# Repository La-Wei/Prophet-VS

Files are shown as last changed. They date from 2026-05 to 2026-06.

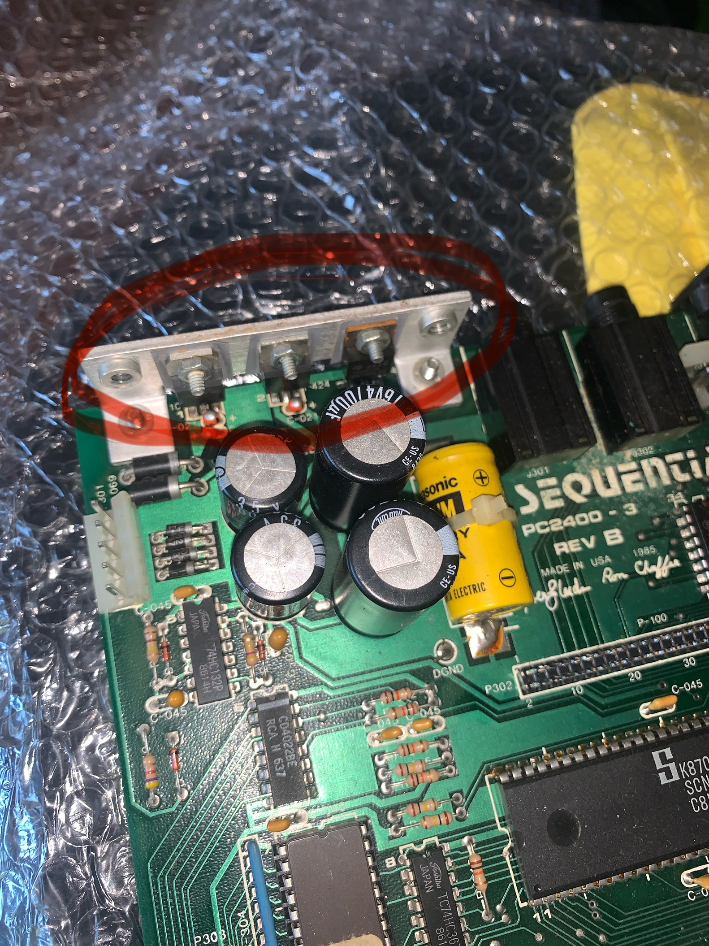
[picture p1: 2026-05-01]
IMG_5543.jpg

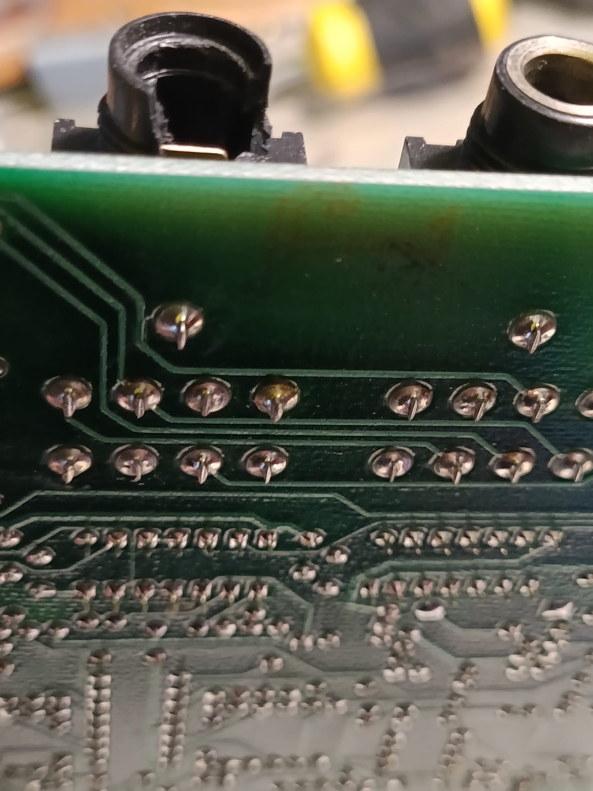
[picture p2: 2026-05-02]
b3b7119b-25aa-43f1-9ff1-f48e857112dc.JPG

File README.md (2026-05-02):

# Prophet VS - diagnosi riparazione

Questa repository contiene materiale preparato per aiutare un tecnico a diagnosticare due problemi separati sul Sequential Circuits Prophet VS:

- audio/modulazione/bleed che passa anche con volume a zero
- retro case molto caldo nella zona dei tre regolatori TO-220

## Apri prima questi file

1. [Cause possibili e fix](tecnico/01_problemi_e_fix/cause_e_fix.md)
2. [Briefing tecnico](tecnico/01_problemi_e_fix/technician_briefing_volume_zero_bleed.md)
3. [Mappa rapida](tecnico/01_problemi_e_fix/quick_navigation_map.md)
4. [CEM5530: diagnosi e ricambi](tecnico/01_problemi_e_fix/cem5530_diagnosi_ricambi.md)
5. [CEM5530/ELD5530: dossier clone o ricostruzione](tecnico/07_autocostruzione_ricambi/cem5530_clone_build_dossier.md)
6. [ELD5530 V2-like con MAX5167: progetto preliminare](tecnico/07_autocostruzione_ricambi/max5167_v2_like_pre_design.md)
7. [Rev A MAX5167: prototipo non validato](tecnico/07_autocostruzione_ricambi/rev_a_max5167_prototipo/README.md)
8. [Moduli Straylight X5530 trovati](tecnico/07_autocostruzione_ricambi/straylight_x5530_moduli_trovati.md)
9. [Contatti acquisto ELD5530 / CEM5530 replacement](tecnico/07_autocostruzione_ricambi/contatti_acquisto_eld5530_cem5530.md)
10. [Batteria memoria, SRAM e mod senza batteria](tecnico/01_problemi_e_fix/batteria_memoria_nvram.md)
11. [Jack posteriori](tecnico/01_problemi_e_fix/jack_sostituzione.md)
12. [Ricambi pannello posteriore](tecnico/01_problemi_e_fix/pannello_posteriore_ricambi.md)
13. [Checklist ispezione](tecnico/02_checklist_misure/visual_inspection_checklist.md)
14. [Piano misure sicure](tecnico/02_checklist_misure/safe_measurement_plan.md)

## Cartelle

- `tecnico/`: pacchetto pulito da consegnare al tecnico.
- `doc/`: PDF originali e knowledge base completa usata per estrarre note e immagini.
- `prompt/`: prompt di lavoro usati per generare la documentazione.

## PDF nel pacchetto tecnico

La cartella `tecnico/06_pdf_originali/` contiene:

- `pvs_service.pdf`
- `sci_prophet_vs_ecr738.pdf`
- `sci_prophet_vs_ecr739.pdf`
- `5530.pdf`
- `5508.pdf`

La sottocartella `tecnico/06_pdf_originali/component_datasheets/` contiene link ai datasheet esterni `MAX5167` e `SSM2300` utili per valutare cloni `CEM5530`. La cartella `tecnico/07_autocostruzione_ricambi/rev_a_max5167_prototipo/` contiene una proposta Rev A marcata chiaramente come prototipo non validato.

## Regolatori nella foto

Nella foto `tecnico/foto/IMG_5543.jpg`, i tre TO-220 fissati al case/dissipatore sono regolatori lineari:

- sinistra: `U301 7805`, rail `+5VD`
- centro: `U302 7812`, rail `+12V`
- destra: `U303 7912`, rail `-12V`

Il regolatore caldo non va considerato automaticamente guasto: e' gia' stato sostituito con uno piu capiente. La priorita' e' misurare rail, ripple, Vin/Vout, temperatura e carico a valle.

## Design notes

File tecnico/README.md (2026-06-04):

# Pacchetto tecnico pulito

Questa cartella e' pensata per un tecnico che deve diagnosticare un Sequential Circuits Prophet VS con due problemi da tenere separati finche le misure non li collegano:

- audio/modulazione/bleed che passa anche con volume a zero
- case posteriore molto caldo nella zona dei tre regolatori TO-220 fissati al dissipatore

## Da aprire per primi

1. `01_problemi_e_fix/cause_e_fix.md`
2. `01_problemi_e_fix/technician_briefing_volume_zero_bleed.md`
3. `01_problemi_e_fix/quick_navigation_map.md`
4. `01_problemi_e_fix/cem5530_diagnosi_ricambi.md`
5. `07_autocostruzione_ricambi/cem5530_clone_build_dossier.md`
6. `07_autocostruzione_ricambi/max5167_v2_like_pre_design.md`
7. `07_autocostruzione_ricambi/rev_a_max5167_prototipo/README.md`
8. `07_autocostruzione_ricambi/straylight_x5530_moduli_trovati.md`
9. `07_autocostruzione_ricambi/contatti_acquisto_eld5530_cem5530.md`
10. `01_problemi_e_fix/batteria_memoria_nvram.md`
11. `01_problemi_e_fix/jack_sostituzione.md`
12. `01_problemi_e_fix/pannello_posteriore_ricambi.md`
13. `02_checklist_misure/visual_inspection_checklist.md`
14. `02_checklist_misure/safe_measurement_plan.md`
15. `01_problemi_e_fix/ronzio_acuto_chorus_u916_ne571/README.md`

## Identificazione regolatori nella foto

La foto `foto/IMG_5543.jpg` mostra la board `PC2400-3 REV B` con tre TO-220 fissati al case/dissipatore. Dai documenti sono regolatori lineari:

- sinistra: `U301 7805`, rail `+5VD`
- centro: `U302 7812`, rail `+12V`
- destra: `U303 7912`, rail `-12V`

L'ordine sinistra->destra deriva dalla designator map `pvs_service` pagina 5; confermare sulla serigrafia reale se visibile.

## Struttura

- `01_problemi_e_fix/`: cause, fix, briefing e mappa rapida.
- `02_checklist_misure/`: controlli visivi e piano misure sicure.
- `03_mappe_circuito/`: mappe brevi per audio, S&H/CV, power/reset, pressure, ECR e chorus.
- `04_componenti_net_rail/`: indici componenti, rail, net e connettori utili.
- `05_pagine_rilevanti/`: note e immagini delle sole pagine utili.
- `06_pdf_originali/`: PDF sorgenti principali.
- `07_autocostruzione_ricambi/`: dossier per valutare cloni/ricostruzione di ricambi non reperibili e prototipo Rev A `MAX5167`.
- `foto/`: foto utente dell'area regolatori.

PDF inclusi in `06_pdf_originali/`: `pvs_service.pdf`, `sci_prophet_vs_ecr738.pdf`, `sci_prophet_vs_ecr739.pdf`, `5530.pdf`, `5508.pdf`. La sottocartella `06_pdf_originali/component_datasheets/` contiene link ai datasheet esterni `MAX5167` e `SSM2300`.

## Escluso apposta

Non ci sono prompt, OCR grezzo, script di estrazione, manifest JSON, cache o pagine non citate. La knowledge base completa resta in `doc/prophet_vs_service_context/` se serve tornare al materiale grezzo.

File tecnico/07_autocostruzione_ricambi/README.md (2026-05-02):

# Autocostruzione ricambi

Questa cartella raccoglie materiale per un tecnico che voglia valutare la ricostruzione di ricambi non reperibili.

Aprire prima:

1. [CEM5530 / ELD5530: dossier per clone o ricostruzione](cem5530_clone_build_dossier.md)
2. [Progetto preliminare ELD5530 V2-like con MAX5167](max5167_v2_like_pre_design.md)
3. [Rev A MAX5167 - prototipo non validato](rev_a_max5167_prototipo/README.md)
4. [Moduli Straylight X5530 trovati](straylight_x5530_moduli_trovati.md)
5. [Contatti per acquisto ELD5530 / CEM5530 replacement](contatti_acquisto_eld5530_cem5530.md)

Nota: questa cartella non contiene Gerber o schema ELD5530 originale, perche' non ne ho trovato una pubblicazione verificabile. Il dossier serve a evitare lavoro alla cieca; il progetto `MAX5167` porta invece la pista piu realistica fino a pin mapping, alimentazioni, vincoli PCB e test minimi. Synthelectro 2014 conferma IC Maxim Integrated per `ELD5530 V2`, ma non pubblica la sigla: `MAX5167` resta quindi un'ipotesi tecnica forte, non una BOM ufficiale. La sottocartella `rev_a_max5167_prototipo/` e' una base concreta per CAD/prototipo, ma resta non validata e non va montata nel Prophet VS senza collaudo fuori macchina.

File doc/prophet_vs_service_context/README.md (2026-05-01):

# Prophet VS service context

Questa cartella contiene una knowledge base locale generata dai PDF scannerizzati in `doc/`, senza modificare i PDF originali.

## Come e' stata creata
- `scripts/extract_pdf_pages.py` renderizza ogni pagina come PNG in `page_images/`.
- PyMuPDF/fitz non era disponibile in questo ambiente; lo script ha usato fallback locale macOS CUPS + `rastertotiff` + Pillow a 300 DPI.
- `scripts/extract_text_and_ocr.py` tenta testo nativo e poi OCR locale con Tesseract.
- `scripts/generate_markdown_kb.py` genera note pagina, indici, mappe circuito, indici componenti e note diagnostiche.

## Affidabilita OCR
OCR medio su datasheet e molte pagine schematiche; basso o incerto su alcune ECR/artwork. Ogni file pagina riporta `METHOD` e `CONFIDENCE`. Se un valore non e' chiaro, e' trattato come [NON CHIARO].

## Come navigare
- Inizia da `index.md` per argomento.
- Usa `source_files.md` per capire i PDF.
- Usa `page_notes/` per pagina specifica.
- Usa `circuit_maps/` per ragionare su pressure, S&H, audio, power/reset, keyboard e ECR.
- Usa `diagnostic_notes/` per partire dai sintomi.

## Da dove partire per riparazione
- Bleed/distorsione a volume zero: `diagnostic_notes/symptom_audio_at_volume_zero.md`, poi `circuit_maps/audio_path.md` e `circuit_maps/sample_hold_cv.md`.
- Pressure/aftertouch: `circuit_maps/pressure_aftertouch.md` e `circuit_maps/board_revisions_ecr.md`.
- Alimentazione: `circuit_maps/power_reset.md`.

## Avvisi
- Non sostituisce un tecnico synth qualificato.
- Sezioni alimentazione/mains possono essere pericolose.
- Vecchie PCB possono danneggiarsi con calore eccessivo, forza, puntali sbagliati o corti durante le misure.

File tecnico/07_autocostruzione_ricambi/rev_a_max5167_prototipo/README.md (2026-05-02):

# Rev A MAX5167 - prototipo non validato

## Stato

Questa cartella contiene una proposta di progetto `Rev A` per un modulo sostitutivo `CEM5530` basato su `MAX5167`.

E' un **prototipo non validato**:

- non e' uno schema originale `ELD5530`;
- non e' una BOM ufficiale Synthelectro: la fonte 2014 conferma solo IC Maxim Integrated, non la sigla `MAX5167`;
- non e' un progetto collaudato nel Prophet VS;
- non contiene Gerber pronti per produzione;
- non va montato nel synth senza test fuori macchina;
- va trasformato in CAD, revisionato e provato da un tecnico.

Obiettivo della `Rev A`: dare al tecnico una base concreta con schema testuale, pin map, BOM funzionale, vincoli PCB e test plan.

Nota batteria: questo prototipo sostituisce solo il `CEM5530`. Non e' la mod memoria non volatile e non elimina la batteria del Prophet VS; vedere `../../01_problemi_e_fix/batteria_memoria_nvram.md`.

## Applicazione pratica

La `Rev A` non e' una modifica interna a un chip. E' una schedina sostitutiva:

```text
CEM5530 originale fuori dallo socket
modulo Rev A inserito nello stesso socket
MAX5167 e alimentazioni locali montati sul modulo Rev A
```

Il CAD serve per realizzare fisicamente quella schedina: il `MAX5167` e' un 48-TQFP, mentre il `CEM5530` originale e' un modulo/IC a 40 pin con piedinatura diversa. La PCB fa da traduttore tra il Prophet e il `MAX5167`.

Se un modulo finito `ELD5530`/Straylight e' reperibile e collaudato, questa cartella non serve per montarlo. Serve solo se il tecnico deve costruire un sostituto.

## Aprire in ordine

1. [00_status_prototipo.md](00_status_prototipo.md)
2. [01_schema_testuale_rev_a.md](01_schema_testuale_rev_a.md)
3. [02_netlist_pinmap_rev_a.csv](02_netlist_pinmap_rev_a.csv)
4. [03_bom_funzione_rev_a.md](03_bom_funzione_rev_a.md)
5. [04_vincoli_pcb_rev_a.md](04_vincoli_pcb_rev_a.md)
6. [05_piano_collaudo_rev_a.md](05_piano_collaudo_rev_a.md)
7. [06_dati_da_misurare_sul_prophet.md](06_dati_da_misurare_sul_prophet.md)
8. [07_handoff_cad.md](07_handoff_cad.md)
9. [cad_kicad/README.md](cad_kicad/README.md)

## Cosa puo' fare il tecnico con questa cartella

- Disegnare lo schema in KiCad/Altium/Eagle senza dover ricavare da zero il mapping.
- Aprire un progetto KiCad iniziale in `cad_kicad/`.
- Creare il footprint adattatore `CEM5530` 40 pin -> `MAX5167` 48-TQFP.
- Selezionare componenti reali per boost, LDO, filtri e protezioni.
- Preparare un primo prototipo.
- Testare il modulo fuori dal Prophet VS.

## Cosa manca prima di dichiararlo funzionante

- Misure reali su `U449/U425`: rail, `VIN`, `INH`, address, carichi.
- Scelta part number finali per alimentazioni e protezioni.
- Layout PCB e revisione indipendente.
- Prototipo fisico.
- Collaudo strumentale.
- Installazione controllata in un solo socket alla volta.

## Rimandi

- Progetto preliminare: [../max5167_v2_like_pre_design.md](../max5167_v2_like_pre_design.md)
- Dossier generale: [../cem5530_clone_build_dossier.md](../cem5530_clone_build_dossier.md)
- Pinout CEM5530: [../../05_pagine_rilevanti/note/5530/page_002.md](../../05_pagine_rilevanti/note/5530/page_002.md)
- Schema Prophet S&H/CV: [../../05_pagine_rilevanti/note/pvs_service/page_006.md](../../05_pagine_rilevanti/note/pvs_service/page_006.md)

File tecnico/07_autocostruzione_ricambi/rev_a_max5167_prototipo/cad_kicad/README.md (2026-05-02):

# KiCad CAD - Rev A MAX5167 prototype

## Stato

Questa cartella contiene un progetto KiCad iniziale per il modulo `MAX5167 Rev A`.

E' **CAD di partenza**, non CAD finale:

- schema e PCB sono marcati come prototipo non validato;
- il PCB e' un placeholder meccanico/elettrico da completare in KiCad;
- non generare Gerber senza revisione del tecnico;
- usare la netlist CSV e lo schema testuale come sorgenti vincolanti.

## File

- `max5167_rev_a_prototype.kicad_pro`: progetto KiCad.
- `max5167_rev_a_prototype.kicad_sch`: foglio schematico di overview con vincoli Rev A.
- `max5167_rev_a_prototype.kicad_pcb`: board placeholder 4 layer con aree funzionali e serigrafia prototipo.
- [exports/max5167_rev_a_schematic.pdf](exports/max5167_rev_a_schematic.pdf): PDF esportato dallo schematico con `kicad-cli`.

Nota: lo schematico e' stato esportato con `kicad-cli 10.0.1` dal DMG KiCad montato localmente. Il PCB e' volutamente un placeholder di layout e va completato in KiCad prima di generare Gerber.

## Come usarlo

1. Aprire `max5167_rev_a_prototype.kicad_pro` in KiCad.
2. Creare/verificare i simboli reali:
   - `J1` socket/header `CEM5530` 40 pin;
   - `U1` `MAX5167` 48-TQFP;
   - `U2/U3/U4` alimentazioni;
   - `U5` DNP opzionale per stretching.
3. Importare il mapping da `../02_netlist_pinmap_rev_a.csv`.
4. Completare lo schema elettrico.
5. Completare il layout PCB.
6. Eseguire ERC/DRC.
7. Fare revisione indipendente prima di qualsiasi Gerber.

## Avvertenza

Il CAD non rende il progetto automaticamente sicuro. Il punto critico resta il collaudo fuori macchina: rail, startup, ripple, timing `INH`, address e carichi CV.

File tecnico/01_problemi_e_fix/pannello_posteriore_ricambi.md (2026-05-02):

# Pannello posteriore: jack, MIDI e switch

## Decisione sui jack 1/4"

I 4 jack 1/4" posteriori hanno plastica rotta: sostituirli tutti.

Foto locali aggiornate:

- `../foto/jack_pcb_01.JPG`
- `../foto/jack_pcb_02.JPG`
- `../foto/midi_din_originale_01.JPG`

Ricambio candidato:

- Jalco `YKB21-5078`
- 1/4" / 6.3 mm PCB
- stereo con switch
- filetto `M12x1`
- equivalenti dichiarati: `HLJ-2305`, `HTJ-064-16D`

Link sorgente: `https://www.synth-parts.com/en/products/connectors-and-cable/14-phone-jack/5460/ykb21-5078-phone-jack-1/4-6.3-mm-for-printed-circuits-stereo`

Jack mono Synth-Parts, solo se i footswitch risultano davvero mono e con footprint diverso:

- Jalco `YKB21-5076`, mono con switch, PCB, filetto `M12x1`: `https://www.synth-parts.com/en/products/connectors-and-cable/14-phone-jack/5475/ykb21-5076-phone-jack-1/4-6.3-mm-pcb-mono`
- Jalco `YKB21-5012`, mono con switch, PCB, filetto `M12x1`: `https://www.synth-parts.com/en/products/connectors-and-cable/14-phone-jack/5461/ykb21-5012-phone-jack-1/4-6.3-mm-for-printed-circuits-mono`

Compra: se tutti e 4 i footprint sono uguali, 4 pezzi `YKB21-5078`; se i due footswitch sono footprint mono, 2 stereo `YKB21-5078` piu 2 mono da scegliere tra `YKB21-5076`/`YKB21-5012` dopo misure.

## Porta/selettore MIDI OUT/THRU

Chiarimento utente: il componente rugginoso e' quello dell'area `MIDI OUT/THRU`, non il selettore tensione.

Il Prophet VS ha tre connessioni MIDI 5 poli DIN:

- `MIDI IN`
- `MIDI OUT`
- `MIDI OUT/THRU`

Il service mostra il circuito MIDI sulla pagina `pvs_service` 3:

- `U333 68B50`: UART MIDI;
- `U312 PC900`: optoisolatore MIDI IN;
- `Q302`: driver `MIDI OUT`;
- `Q301`: driver `MIDI OUT/THRU`.

Quindi la zona da controllare e' pagina `pvs_service` 3, non la pagina alimentazione.

## Se e' la presa DIN `MIDI OUT/THRU`

Se e' arrugginita la presa DIN femmina:

1. testare MIDI OUT e MIDI THRU con cavi buoni;
2. ispezionare pin, schermatura metallica, saldature e piazzole;
3. se la ruggine e' estesa o i contatti sono instabili, sostituire la presa.

Aggiornamento dalle foto: `../foto/midi_din_originale_01.JPG` mostra una presa DIN 5 poli diversa dai ricambi Jalco PCB gia linkati. Si vede un corpo con inserto rosso/fenolico, contatti lunghi piegati verso la PCB e due flange/orecchie di fissaggio. Quindi `YKF51-5050` e `YKF51-5046` non vanno ordinati come ricambi sicuri.

Il service non basta per garantire il footprint meccanico dei DIN. Prima di ordinare bisogna guardare la board reale e capire se i MIDI sono:

1. un blocco triplo integrato, tre DIN in un solo corpo;
2. tre prese DIN singole separate;
3. una DIN panel/chassis mount con terminali lunghi piegati/saldati in PCB, come sembra dalla nuova foto;
4. una variante ruotata o con pinout diverso.

Ricambi candidati, da confermare fisicamente:

- se e' un blocco triplo: Jalco `YKF51-5046`, triple female MIDI DIN socket for PCB, ma le foto nuove non puntano a questa soluzione;
- se sono singoli PCB moderni: Jalco `YKF51-5050` o `BCTE5P1-5211`, ma le foto nuove non sembrano combaciare;
- se e' come in foto: cercare una DIN femmina 5 poli `180 degree`, panel/chassis mount o PCB right-angle con flange, terminali solder/PC lunghi e stessa geometria.

Fonti ricambio:

- `https://www.synth-parts.com/en/products/connectors-and-cable/din-sockest-and-plugs/6651/e-mu-triple-female-midi-socket-for-pcb-jalco-ykf51-5046`
- `https://www.synth-parts.com/en/products/connectors-and-cable/din-sockest-and-plugs/6721/din-female-5-pin-midi-for-pcb-ykf51-5050`
- `https://www.synth-parts.com/en/products/connectors-and-cable/din-sockest-and-plugs/5442/din-female-5-pin-midi-for-printed-circuits`
- `https://www.synth-parts.com/en/products/connectors-and-cable/din-sockest-and-plugs/`

Nota importante: i link Synth-Parts sopra sono ora **solo confronto**, non ricambio confermato per il Prophet VS fotografato. Dalle foto bisogna cercare un ricambio con stessa meccanica, non solo "DIN MIDI 5 pin".

### Pista MIDI piu concreta dopo le foto

La pista piu concreta non e' Synth-Parts/Jalco, ma una DIN femmina 5 poli `180 degree` di famiglia Switchcraft DIN panel/PC mount.

Candidati Switchcraft da confrontare per primi:

- `57NC5FX`: DIN panel mount, 5 contatti a 180 gradi, terminali PC/thru-hole. E' il candidato piu interessante se il tecnico vuole terminali da PCB.
- `57GB5FX`: DIN panel mount, 5 contatti a 180 gradi, terminali solder cup/flared solder. E' interessante se l'originale ha terminali lunghi/saldabili da formare verso la PCB.
- `57PC5F`: DIN femmina right-angle PC mount, 5 contatti a 180 gradi, contact arrangement F. Da confrontare se serve un corpo piu "PCB right-angle" invece del panel mount classico.

Link utili:

- `https://www.switchcraft.com/din-panel-mount-connector-5-contacts-at-180-pc-terminals/57nc5fx/`
- `https://www.switchcraft.com/din-panel-mount-connector-5-contacts-at-180-/57gb5fx/`
- `https://www.switchcraft.com/female-din-right-angle-pc-mount-5-contacts-at-180-contact-arrangement-f/57pc5f/`

Verdetto operativo: prima misurare/interfacciare con questi tre datasheet/foto. Se uno combacia per flange, altezza e pattern terminali, quello diventa il ricambio MIDI preferito. Se non combacia, si cerca ancora, ma almeno si e' nella famiglia giusta.

Candidati/famiglie da confrontare fuori Synth-Parts:

- Switchcraft `57GB5FX`: DIN femmina 5 contatti 180 gradi, panel mount, usata per MIDI, `https://www.performanceaudio.com/products/switchcraft-57gb5fx-5-pin-din-panel-mount-jack`;
- Lumberg `0105 05`: DIN 5 poli right-angle/PCB chassis socket, `https://cpc.farnell.com/lumberg/0105-05/din-connector-rcpt-5pos-chassis/dp/CN25115`;
- Hirschmann `MAB 5 SH`: DIN 5 poli PCB right-angle, `https://uk.farnell.com/hirschmann/mab-5-sh/socket-din-pcb-5pin/dp/1944987`;
- Deltron `671-0501`: DIN 5 poli female PCB right-angle, `https://no.rs-online.com/web/p/din-connectors/1806737`.

Questi sono candidati di ricerca: non comprarli senza misurare distanza fori, altezza rispetto al pannello, forma flange, orientamento pin e pattern dei terminali.

## Se e' il piccolo switch `MIDI OUT/THRU`

Se il componente rugginoso e' proprio un piccolo slide switch vicino alla porta `MIDI OUT/THRU`, cercare come:

- slide switch right-angle PCB;
- `SP3T` / `1P3T`;
- funzione `ON-ON-ON`;
- low-current signal switch, non mains;
- stesso footprint, stessa altezza leva, stesso passo pin, stessi eventuali pin di ancoraggio.

Candidati da confrontare, non da comprare alla cieca:

- C&K `OS103011MA7QP1C`: SP3T, through-hole, right angle, PC pin;
- C&K `AYZ0103AGRLC`: SP3T, SMD/gull wing, right angle;
- Same Sky/CUI `SLW-1516255-6A-RA-D`: SP3T, through-hole, right angle;
- generici `SS-13F16` / `SS-13F24`: SP3T, through-hole, right angle.

Fonte utile ma non Prophet VS: una discussione Gearspace su Prophet 2000 descrive il selettore MIDI Thru/Out come slide switch right-angle `SP3T`. Questo aiuta la ricerca della famiglia componente, ma non prova il footprint del Prophet VS.

Fonte: `https://gearspace.com/board/geekzone/1421716-prophet-2000-need-help-finding-replacement-part.html`

## Test funzionale

Prima di dissaldare:

1. con MIDI monitor, verificare `MIDI OUT` separato;
2. verificare `MIDI OUT/THRU` nelle posizioni disponibili;
3. muovere leggermente plug/switch: se il segnale cade o diventa intermittente, il componente e' da sostituire;
4. se la ruggine e' sullo switch, misurare continuita' tra comune e contatti in ogni posizione.

## Nota separata: power e selettore tensione

Sul retro esistono anche componenti mains:

- `S1`: power switch;
- `S2`: selettore tensione `110/220`;
- `F1`: fuse.

Questi non sono l'oggetto indicato dall'utente, ma se risultano rugginosi vanno controllati come parti di rete AC.

## Lista acquisto pratica

Da comprare subito se il footprint jack e' confermato:

- 4 x Jalco `YKB21-5078`, se tutti e 4 i jack hanno stesso footprint stereo/switch
- oppure 2 x `YKB21-5078` + 2 x mono `YKB21-5076`/`YKB21-5012`, se i footswitch sono davvero footprint mono
- dadi `M12x1` di scorta, se non inclusi o se quelli originali sono ossidati

Da comprare solo dopo foto/misura:

- MIDI DIN: non comprare `YKF51-5050`/`YKF51-5046` come sicuri; dalle foto serve probabilmente DIN femmina 5 poli panel/PCB right-angle con flange e terminali lunghi. Prima confrontare Switchcraft `57NC5FX`, `57GB5FX`, `57PC5F`;
- eventuale slide switch `MIDI OUT/THRU` SP3T/right-angle con footprint identico.

Da non fare:

- non montare jack MIDI generici se non entrano perfettamente nel pannello;
- non ordinare un blocco triplo MIDI se sulla board ci sono tre DIN separati;
- non ordinare uno switch SP3T solo perche ha la stessa funzione: deve combaciare fisicamente;
- non lasciare la presa/switch `MIDI OUT/THRU` rugginosa se il contatto e' intermittente.

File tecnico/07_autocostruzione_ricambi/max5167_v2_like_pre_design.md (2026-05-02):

# Progetto preliminare ELD5530 V2-like con MAX5167

## Stato del progetto

Questo documento e' una pre-progettazione tecnica per una scheda sostitutiva del `CEM5530` in stile `ELD5530 V2`.

Non e' lo schema originale ELD5530, non e' una BOM definitiva e non e' un Gerber pronto da produrre. Serve a portare il lavoro fino al punto in cui un tecnico/progettista possa disegnare lo schema in CAD, fare una revisione pin-to-pin e preparare un prototipo senza ripartire da zero.

Per il pacchetto Rev A concreto, vedere [rev_a_max5167_prototipo/README.md](rev_a_max5167_prototipo/README.md). La Rev A e' marcata come prototipo non validato.

Risposta breve alla domanda: la fonte primaria Synthelectro 2014 conferma che `ELD5530 V2` e' basato su un IC Maxim Integrated, ma non pubblica la sigla. Il forum Gearspace cita esplicitamente il `MAX5167` e il datasheet `MAX5167` combacia molto bene con la funzione richiesta. Quindi il progetto piu realistico resta `MAX5167` su PCB adattatore 40 pin, con alimentazioni locali integrate, ma va trattato come prototipo dedotto e non come replica certificata dell'ELD5530 originale.

La stessa fonte 2014 spiega anche perche' le alimentazioni locali sono obbligatorie: la prima versione del ricambio richiedeva due piccole modifiche sulla board perche' non gestiva tutte le alimentazioni; la V2 invece fornisce direttamente le tensioni necessarie e viene presentata come plug-in replacement del `CEM5530`.

Nota batteria: questa scheda sostituisce il `CEM5530` nello sample & hold/CV e non elimina la batteria memoria. La batteria sparisce solo con una mod separata alle SRAM patch non volatili; vedere `../01_problemi_e_fix/batteria_memoria_nvram.md`.

## Cosa significa "modifica" in pratica

Non si modifica fisicamente il `MAX5167` e non si modifica il silicio del `CEM5530`.

La modifica e' una **scheda adattatrice**:

```text
socket Prophet per CEM5530
  -> schedina adattatrice 40 pin
  -> MAX5167 saldato sulla schedina
  -> regolatori/filtri locali sulla schedina
  -> pin della schedina che imitano il CEM5530 originale
```

Il `MAX5167` e' il chip commerciale che fa il lavoro sample & hold. Pero' non ha:

- lo stesso package del `CEM5530`;
- la stessa piedinatura;
- le stesse alimentazioni dirette;
- solo 30 canali, perche ne ha 32;
- la stessa meccanica plug-in.

Per questo serve il CAD: non per "programmare" o "modificare" il chip, ma per disegnare la piccola PCB che converte piedinatura, alimentazioni e segnali. In pratica il tecnico non prende un `MAX5167` e lo infila nel Prophet: salda il `MAX5167` su una schedina, testa la schedina, poi inserisce la schedina al posto del `CEM5530`.

Se si trova un modulo `ELD5530` o Straylight gia finito e collaudato, il CAD non serve all'utente: si compra il modulo e si monta. Il CAD serve solo se il modulo va ricostruito.

## Come si applica sul Prophet VS

Procedura pratica ideale, se il modulo Rev A viene davvero realizzato:

1. Diagnosticare quale `CEM5530` e' guasto o sospetto: `U449`, `U425`, oppure entrambi.
2. Misurare rail, `VIN`, `INH` e address sul socket originale.
3. Costruire la schedina adattatrice `MAX5167` fuori dal synth.
4. Collaudarla su alimentatore e fixture, non nel Prophet.
5. Spegnere il Prophet, rimuovere il `CEM5530` originale dal socket.
6. Se il socket originale e' doppia lira o fragile, sostituirlo con socket tulip di qualita'.
7. Inserire la schedina adattatrice rispettando pin 1.
8. Accendere con controllo corrente/temperatura.
9. Verificare CV e audio prima di montare il secondo modulo.

Quindi la modifica visibile sulla macchina dovrebbe essere minima: togliere il vecchio chip e inserire il modulo adattatore. La parte complessa sta tutta nella piccola scheda sostitutiva.

## Vincoli non negoziabili

- Modulo plug-in al posto del `CEM5530`, senza fili esterni se possibile.
- Compatibilita' con socket `U449` e `U425` del Prophet VS.
- Footprint maschio compatibile con il `CEM5530` a `40` pin.
- Ingresso comune dal DAC/S&H Prophet verso l'ingresso sample del nuovo IC.
- `30` uscite CV operative; i due canali extra del `MAX5167` restano non usati.
- Polarita' `INH` compatibile: high = hold, low = sample/acquire.
- Alimentazioni locali pulite: il `MAX5167` non va alimentato direttamente dal rail `+8V` originale.
- Prova fuori dal synth obbligatoria prima dell'installazione.

## Confronto CEM5530 vs MAX5167

| Punto | CEM5530 | MAX5167 | Impatto sul progetto |
| --- | --- | --- | --- |
| Canali | 30 S&H | 32 S&H | `OUT30/OUT31` restano NC/test pad |
| Address | 5 bit `A0..A4` | 5 bit `ADDR0..ADDR4` | Mapping diretto, da confermare sul timing Prophet |
| Controllo | `INH` | `S/H`, `SELECT`, `CONFIG` | `INH` puo' pilotare `S/H` se `SELECT` e' reso sempre attivo |
| Sample/hold | `INH` low aggiorna il canale indirizzato; high mette in hold/auto-zero | `S/H` low sample, high hold | Polarita' compatibile |
| Rail | Nel Prophet visibili `+8V`, `-5V`, GND/AGND | `VDD +10V`, `VSS -5V`, `VL +5V` | Serve generazione locale `+10V` e `+5V` |
| Package | 40 pin | 48 pin TQFP | Serve PCB adattatore |
| Droop | Da datasheet CEM, verificare pagina 4 | Tipico `1 mV/s` | Adeguato in teoria, ma va misurato nel refresh reale |
| Acquisition | CEM: ciclo veloce, pagina 4 | Datasheet MAX: 2.5 us tipico, fino a 4 us per acquisizione accurata | Misurare larghezza reale di sample nel Prophet |
| Output impedance | Buffer interni CEM | Varianti `L/M/N`: 50R/500R/1k | Preferire footprint che consenta piccole correzioni |

## Pinout CEM5530 ricavato dalla pagina 2

Da confermare visivamente su `../05_pagine_rilevanti/immagini/5530/page_002.png` e sulla board reale prima di disegnare il PCB.

| Pin CEM5530 | Segnale |
| --- | --- |
| 1 | `VIN` |
| 2-9 | `O0..O7` |
| 10 | `INH` |
| 11 | `A4` |
| 12-19 | `O8..O15` |
| 20 | `VSS` |
| 21 | `GND` |
| 22-29 | `O16..O23` |
| 30 | `A0` |
| 31 | `A1` |
| 32 | `A2` |
| 33 | `A3` |
| 34-39 | `O24..O29` |
| 40 | `VDD` |

## Mapping proposto CEM5530 -> MAX5167

Questo e' il mapping elettrico di partenza. Prima del CAD va verificato con continuita' sullo schema `pvs_service` pagina 6 e con una prova su breadboard/fixture.

| CEM5530 | MAX5167 | Note |
| --- | --- | --- |
| pin 1 `VIN` | pin 11 `IN` | Collegamento diretto iniziale; aggiungere footprint serie `0R/100R` e pad test |
| pin 10 `INH` | pin 5 `S/H` | Polarita' compatibile: high hold, low sample |
| pin 11 `A4` | pin 3 `ADDR4` | Address bit 4 |
| pin 30 `A0` | pin 47 `ADDR0` | Address bit 0 |
| pin 31 `A1` | pin 48 `ADDR1` | Address bit 1 |
| pin 32 `A2` | pin 1 `ADDR2` | Address bit 2 |
| pin 33 `A3` | pin 2 `ADDR3` | Address bit 3 |
| pin 2 `O0` | pin 14 `OUT0` | Uscita CV 0 |
| pin 3 `O1` | pin 15 `OUT1` | Uscita CV 1 |
| pin 4 `O2` | pin 16 `OUT2` | Uscita CV 2 |
| pin 5 `O3` | pin 17 `OUT3` | Uscita CV 3 |
| pin 6 `O4` | pin 18 `OUT4` | Uscita CV 4 |
| pin 7 `O5` | pin 19 `OUT5` | Uscita CV 5 |
| pin 8 `O6` | pin 20 `OUT6` | Uscita CV 6 |
| pin 9 `O7` | pin 21 `OUT7` | Uscita CV 7 |
| pin 12 `O8` | pin 22 `OUT8` | Uscita CV 8 |
| pin 13 `O9` | pin 23 `OUT9` | Uscita CV 9 |
| pin 14 `O10` | pin 24 `OUT10` | Uscita CV 10 |
| pin 15 `O11` | pin 25 `OUT11` | Uscita CV 11 |
| pin 16 `O12` | pin 26 `OUT12` | Uscita CV 12 |
| pin 17 `O13` | pin 27 `OUT13` | Uscita CV 13 |
| pin 18 `O14` | pin 28 `OUT14` | Uscita CV 14 |
| pin 19 `O15` | pin 29 `OUT15` | Uscita CV 15 |
| pin 22 `O16` | pin 31 `OUT16` | Uscita CV 16 |
| pin 23 `O17` | pin 32 `OUT17` | Uscita CV 17 |
| pin 24 `O18` | pin 33 `OUT18` | Uscita CV 18 |
| pin 25 `O19` | pin 34 `OUT19` | Uscita CV 19 |
| pin 26 `O20` | pin 35 `OUT20` | Uscita CV 20 |
| pin 27 `O21` | pin 36 `OUT21` | Uscita CV 21 |
| pin 28 `O22` | pin 37 `OUT22` | Uscita CV 22 |
| pin 29 `O23` | pin 38 `OUT23` | Uscita CV 23 |
| pin 34 `O24` | pin 39 `OUT24` | Uscita CV 24 |
| pin 35 `O25` | pin 40 `OUT25` | Uscita CV 25 |
| pin 36 `O26` | pin 41 `OUT26` | Uscita CV 26 |
| pin 37 `O27` | pin 42 `OUT27` | Uscita CV 27 |
| pin 38 `O28` | pin 43 `OUT28` | Uscita CV 28 |
| pin 39 `O29` | pin 44 `OUT29` | Uscita CV 29 |
| n/a | pin 45 `OUT30` | NC, pad test opzionale |
| n/a | pin 46 `OUT31` | NC, pad test opzionale |
| pin 20 `VSS` | pin 9 `VSS` | Filtrare; rail `-5V` locale |
| pin 21 `GND` | pin 8 `DGND`, pin 10 `AGND` | Unione controllata, stella locale |
| pin 40 `VDD` | non diretto a MAX `VDD` | Usare come ingresso `+8V` per alimentazioni locali |
| n/a | pin 30 `VDD` | `+10V` locale regolato |
| n/a | pin 7 `VL` | `+5V` logico locale |
| n/a | pin 4 `SELECT` | Default a `VL` |
| n/a | pin 6 `CONFIG` | Default a `DGND`; cosi `SELECT` e' active-high |
| n/a | pin 12 `CH` | Default a `VDD +10V`, verificare clamp desiderato |
| n/a | pin 13 `CL` | Default a `VSS -5V`, verificare clamp desiderato |

## Schema elettrico di principio

```text
CEM5530 socket pin 40 VDD circa +8V
  -> filtro ingresso
  -> boost low-noise +11/+12V
  -> LDO/filtraggio finale +10V
  -> MAX5167 pin 30 VDD
  -> MAX5167 pin 12 CH

CEM5530 socket pin 40 VDD circa +8V
  -> LDO low-noise +5V
  -> MAX5167 pin 7 VL
  -> pull-up SELECT

CEM5530 socket pin 20 VSS circa -5V
  -> filtro ingresso
  -> MAX5167 pin 9 VSS
  -> MAX5167 pin 13 CL

CEM5530 socket pin 21 GND/AGND
  -> punto stella locale
  -> MAX5167 pin 10 AGND
  -> MAX5167 pin 8 DGND

CEM5530 pin 10 INH
  -> 47R/100R serie opzionale
  -> MAX5167 pin 5 S/H

MAX5167 pin 6 CONFIG
  -> DGND

MAX5167 pin 4 SELECT
  -> VL
```

## Alimentazioni locali

La parte piu "V2-like" e' questa: la scheda deve generare da sola le tensioni che il `MAX5167` richiede.

Proposta base:

- ingresso dal pin `VDD` CEM: misurare sul Prophet reale, atteso circa `+8V`;
- ingresso dal pin `VSS` CEM: misurare sul Prophet reale, atteso circa `-5V`;
- `+10V` analogico per `MAX5167 VDD`: generarlo con boost da `+8V`, preferibilmente seguito da filtraggio o LDO se il margine e lo spazio lo consentono;
- `+5V` logico per `MAX5167 VL`: generarlo da `+8V` con LDO locale low-noise;
- `-5V` analogico per `MAX5167 VSS`: usare il rail `VSS` esistente solo dopo filtro e misura ripple;
- `AGND/DGND`: unione locale controllata, poi ritorno al pin `GND` CEM.

Punti da non saltare:

- misurare corrente assorbita dal modulo originale se ancora funzionante;
- dimensionare il boost con margine termico, non solo con corrente teorica del datasheet;
- rispettare il limite `VDD-VSS` del `MAX5167`: con `+10V` e `-5V` si lavora gia vicino al massimo ammesso; evitare overshoot di startup, boost mal regolato o `-5V` assente durante l'accensione;
- tenere il ripple del boost lontano dall'ingresso `VIN`, dalle uscite CV e dal ground analogico;
- prevedere test pad per `+8_IN`, `-5_IN`, `+10_A`, `+5_L`, `GND`, `INH`, `VIN`.

Protezione raccomandata in revisione 1: soft-start o enable controllato del boost, clamp/TVS adeguati sui rail locali se compatibili con il rumore richiesto, e prova di accensione/spegnimento con oscilloscopio su `VDD`, `VSS`, `VL` e `GND`.

## Timing e logica

Il `MAX5167` puo' funzionare in modo molto simile al `CEM5530` se:

- `CONFIG` e' tenuto low;
- `SELECT` e' tenuto high;
- `S/H` riceve il segnale `INH`.

Con questa configurazione:

- `INH`/`S/H` high: tutti i canali in hold;
- `INH`/`S/H` low: il canale indirizzato da `ADDR0..ADDR4` campiona `IN`.

Il rischio vero non e' la polarita', ma la larghezza temporale. Nel `MAX5167` il minimo impulso digitale `S/H` e' molto breve, ma quello non basta a garantire che l'uscita abbia gia acquisito il valore analogico con precisione. Il datasheet indica acquisizione tipica `2.5 us` e fino a `4 us` per accuratezza piena: il datasheet `CEM5530` e la logica Prophet vanno quindi misurati con oscilloscopio:

- larghezza del tratto `INH` low;
- setup/hold degli address rispetto a `INH`;
- stabilizzazione del DAC prima del sample;
- tempo tra due canali successivi.

Decisione progettuale consigliata:

- primo prototipo senza stretching di `INH`, per non alterare la macchina;
- se la finestra low e' troppo breve, aggiungere solo in seconda revisione una piccola logica opzionale, abilitabile con jumper, che estenda `S/H` low senza invadere il cambio address/DAC successivo;
- non aggiungere monostabili "a sentimento": un impulso piu lungo puo' campionare il canale sbagliato.

Nota di audit: aggiungere nel CAD footprint DNP per una logica di stretching, ma popolare la revisione 1 in modalita' passiva/direct. In questo modo si lascia una via di correzione senza introdurre subito una variabile nuova.

## Uscite e carichi

Scelta iniziale consigliata: partire dal `MAX5167L` se reperibile autentico, per l'impedenza d'uscita piu bassa (`50R`). Le varianti `M` e `N` hanno impedenze piu alte e possono essere utili con carichi capacitivi, ma possono introdurre piu errore se il carico della CV e' basso.

Layout consigliato:

- footprint per resistenza serie opzionale su ogni uscita, default `0R` o DNP secondo test;
- test pad almeno su `OUT0`, `OUT15`, `OUT29`;
- `OUT30` e `OUT31` solo su test pad, non collegati al socket;
- niente condensatori verso massa sulle uscite in revisione 1, salvo footprint DNP, per non rallentare CV o caricare il chip;
- se una linea Prophet mostra carico troppo basso, prevedere buffer op amp esterno solo su revisione dedicata.

## BOM preliminare

Questa BOM e' volutamente per funzione, non per marca definitiva.

| Q.ta | Parte | Nota |
| --- | --- | --- |
| 1 | `MAX5167L` / `MAX5167M` / `MAX5167N`, 48-TQFP | Preferenza iniziale `L`; comprare solo da fonte affidabile |
| 1 | PCB adattatore 40 pin -> 48-TQFP | 4 layer consigliati: power/ground piu puliti |
| 1 | Boost converter regolato per `+10V` finale | Da `+8V`; scegliere modello low-noise e collaudabile |
| 1 | LDO/filtraggio `+10V` se si usa boost sopra `+10V` | Consigliato se lo spazio lo permette |
| 1 | LDO `+5V` logico | Da `+8V` a `VL` |
| 1 | Filtro/ferrite rail `-5V` | Prima di `MAX5167 VSS` |
| varie | Protezione startup/overshoot rail | Soft-start, enable o clamp da definire in CAD |
| 1 | Footprint DNP per stretching `S/H` | Solo se le misure Prophet mostrano sample troppo breve |
| 1 | Set pin torniti 40 pin | Maschio, passo e larghezza da misurare sul socket |
| 30 | Resistenze serie uscita opzionali | Footprint `0R/100R/470R`, default dopo test |
| 6 | Resistenze serie logica opzionali | `INH`, `A0..A4`, tipicamente `47R/100R` se servono |
| varie | Decoupling | `100nF` vicino ai pin, piu bulk `1uF/10uF` per rail |
| varie | Test pad | Rail, `VIN`, `INH`, address, uscite campione |

## Vincoli PCB

- Tenere boost converter e induttore lontani da `VIN` e dalle uscite CV.
- Ground plane continuo, con ritorno analogico pulito.
- `MAX5167` il piu vicino possibile al centro del modulo per fanout equilibrato.
- Decoupling direttamente ai pin `VDD`, `VSS`, `VL`.
- Pin header meccanicamente robusto; evitare pin economici che stressano il socket.
- Altezza massima da misurare nel Prophet reale prima di scegliere componenti.
- Orientamento pin 1 marcato in modo molto evidente sul silkscreen.
- Prevedere spazio per una label `MAX5167 V2-like, not original ELD5530`.

## Piano test prima del Prophet

1. Ispezione ottica del PCB e continuita' tra tutti i pin del finto `CEM5530`.
2. Alimentazione da banco con limitazione corrente su `+8V`, `-5V`, GND simulati.
3. Verifica rail locali: `+10V`, `+5V`, ripple e startup.
4. Verifica termica 30-60 minuti senza segnali.
5. Generatore DAC simulato su `VIN`, address manuali/logic analyzer su `A0..A4`.
6. Per ogni address 0-29: portare `S/H` low, campionare, tornare high, verificare solo il canale atteso.
7. Verificare che `OUT30/OUT31` non tocchino il socket.
8. Misurare droop su 1 minuto e su intervallo pari al refresh Prophet.
9. Misurare hold step e glitch quando si cambia address.
10. Test con carichi equivalenti alle CV Prophet: almeno `5k`, `10k`, `47k` e capacita' parassita ragionevole.
11. Solo dopo: installare un modulo alla volta nel Prophet, con alimentatore limitato o lamp/current monitor se disponibile.

## Gate prima di mandare in produzione

Non produrre piu di un prototipo finche questi punti non sono chiusi:

- rail reali misurati sui socket `U449` e `U425`;
- larghezza `INH` low/high misurata in condizioni operative;
- range reale del segnale `VIN` misurato;
- carico minimo delle linee CV piu critiche stimato o misurato;
- spazio verticale e orientamento pin 1 verificati fisicamente;
- disponibilita' reale e autenticita' del `MAX5167` verificata;
- revisione indipendente del mapping pin-to-pin.

## Esito audit

| Area | Stato | Nota |
| --- | --- | --- |
| Architettura | verde | `MAX5167` e' funzionalmente molto vicino al `CEM5530` |
| Pin mapping | giallo | Tabella pronta, ma da verificare su immagine e board reale |
| Alimentazioni | giallo | Concetto V2-like definito; part number da scegliere dopo misure |
| Timing | giallo/rosso | Polarita' ok; larghezza sample da misurare prima del PCB definitivo |
| Output/carichi | giallo | Serve misura o stima carichi CV Prophet |
| Meccanica | giallo | Serve misura altezza e socket |
| Produzione | rosso | Nessun Gerber definitivo; serve prototipo e test |

## Fonti e rimandi

- Dossier generale: [cem5530_clone_build_dossier.md](cem5530_clone_build_dossier.md)
- Rev A prototipo: [rev_a_max5167_prototipo/README.md](rev_a_max5167_prototipo/README.md)
- Datasheet CEM5530 locale: `../06_pdf_originali/5530.pdf`
- Pinout CEM5530 locale: [5530 pagina 2](../05_pagine_rilevanti/note/5530/page_002.md)
- Timing CEM5530 locale: [5530 pagina 4](../05_pagine_rilevanti/note/5530/page_004.md)
- Schema Prophet S&H/CV: [pvs_service pagina 6](../05_pagine_rilevanti/note/pvs_service/page_006.md)
- Synthelectro ELD5530 V2: `https://synthelectro-fr.blogspot.com/2014/06/cem5530-pour-prophet-vs-studio-440.html`
- Synthelectro archivio giugno 2014 con lo stesso post: `https://synthelectro-fr.blogspot.com/2014/06/`
- Analog Devices / Maxim MAX5167 product page: `https://www.analog.com/en/products/max5167l.html`
- Analog Devices / Maxim MAX5167 datasheet: `https://www.analog.com/media/en/technical-documentation/data-sheets/MAX5167-MAX5167N.pdf`

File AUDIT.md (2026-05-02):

# Audit repository

Data audit: 2026-05-02

## Esito rapido

- `5508.pdf` copiato in `tecnico/06_pdf_originali/5508.pdf`.
- Aggiunto dossier `CEM5530/ELD5530` per clone/ricostruzione in `tecnico/07_autocostruzione_ricambi/`.
- Aggiunto progetto preliminare `ELD5530 V2-like` basato su `MAX5167`, con pin mapping, rail locali, vincoli PCB e piano test.
- Aggiunta cartella `rev_a_max5167_prototipo/` con schema testuale, netlist CSV, BOM funzionale, vincoli PCB, collaudo e handoff CAD. E' marcata come prototipo non validato.
- Aggiunto progetto KiCad iniziale in `tecnico/07_autocostruzione_ricambi/rev_a_max5167_prototipo/cad_kicad/`.
- Aggiunta nota `batteria_memoria_nvram.md`: `ELD5530` non elimina la batteria; solo una mod SRAM non volatile puo' farlo.
- Correzione ELD5530 da fonte primaria Synthelectro 2014: V2 confermata su IC Maxim Integrated, ma `MAX5167` resta ipotesi tecnica non BOM ufficiale.
- Aggiunto file `contatti_acquisto_eld5530_cem5530.md` con destinatari e email inglesi per cercare 2 moduli.
- Aggiunta nota `straylight_x5530_moduli_trovati.md`: i due moduli in foto sembrano Straylight `X5530`, cloni/ricambi `CEM5530` basati su 4 x `SMP18`.
- Chiarito che i dissipatori consigliati sono per `CEM5530` originali; sui cloni `X5530` non vanno aggiunti senza misura o istruzione Straylight.
- Aggiunti link datasheet esterni `MAX5167` e `SSM2300` in `tecnico/06_pdf_originali/component_datasheets/README.md`.
- Link Markdown controllati: 364 link locali controllati, 0 rotti su 109 file Markdown.
- Pacchetto tecnico controllato: non contiene prompt, script, OCR grezzo, manifest JSON o cache.
- Vecchia cartella `doc/prophet_vs_technician_package/`: assente.
- Cartella consegnabile: `tecnico/`.
- Knowledge base completa: `doc/prophet_vs_service_context/`.

## Struttura attuale

- `README.md`: guida principale in root.
- `AUDIT.md`: questo report.
- `tecnico/`: materiale pulito per il tecnico.
- `doc/`: PDF originali e knowledge base completa/generata.
- `prompt/`: prompt di lavoro.

## Pacchetto tecnico

File principali da aprire:

1. `tecnico/01_problemi_e_fix/cause_e_fix.md`
2. `tecnico/01_problemi_e_fix/technician_briefing_volume_zero_bleed.md`
3. `tecnico/01_problemi_e_fix/quick_navigation_map.md`
4. `tecnico/01_problemi_e_fix/cem5530_diagnosi_ricambi.md`
5. `tecnico/07_autocostruzione_ricambi/cem5530_clone_build_dossier.md`
6. `tecnico/07_autocostruzione_ricambi/max5167_v2_like_pre_design.md`
7. `tecnico/07_autocostruzione_ricambi/rev_a_max5167_prototipo/README.md`
8. `tecnico/07_autocostruzione_ricambi/straylight_x5530_moduli_trovati.md`
9. `tecnico/07_autocostruzione_ricambi/contatti_acquisto_eld5530_cem5530.md`
10. `tecnico/01_problemi_e_fix/batteria_memoria_nvram.md`
11. `tecnico/01_problemi_e_fix/jack_sostituzione.md`
12. `tecnico/01_problemi_e_fix/pannello_posteriore_ricambi.md`
13. `tecnico/02_checklist_misure/visual_inspection_checklist.md`
14. `tecnico/02_checklist_misure/safe_measurement_plan.md`

PDF inclusi:

- `tecnico/06_pdf_originali/pvs_service.pdf`
- `tecnico/06_pdf_originali/sci_prophet_vs_ecr738.pdf`
- `tecnico/06_pdf_originali/sci_prophet_vs_ecr739.pdf`
- `tecnico/06_pdf_originali/5530.pdf`
- `tecnico/06_pdf_originali/5508.pdf`

Link datasheet esterni utili:

- `tecnico/06_pdf_originali/component_datasheets/README.md`
- `MAX5167-MAX5167N` Analog Devices
- `SSM2300` Analog Devices

## Controlli effettuati

- Validazione link Markdown su tutti i `.md` della repo: nessun link mancante.
- Ricerca percorsi obsoleti nel pacchetto tecnico: nessun riferimento a `doc/prophet_vs_technician_package`.
- Ricerca contenuti da escludere in `tecnico/`: nessun `prompt/`, `scripts/`, `extracted_text/`, `manifest*.json`.
- Dimensione indicativa: `tecnico/` circa 11M; `doc/prophet_vs_service_context/` circa 17M.

## Note residue

- `.DS_Store` era presente in root come file di sistema macOS. Aggiunto `.gitignore` per evitarne il tracking futuro; il file fisico non e' stato cancellato.
- `IMG_5543.jpg` resta sia in root sia in `tecnico/foto/IMG_5543.jpg`: la copia in `tecnico/` serve al pacchetto consegnabile, quella in root e' il sorgente originale dell'utente.
- Non sono stati trovati Gerber/schema/BOM pubblici e verificabili per `ELD5530`: il dossier documenta questa assenza. La pre-progettazione `MAX5167` e la cartella Rev A portano avanti la soluzione piu probabile, ma restano da verificare al banco prima di qualsiasi produzione o installazione.

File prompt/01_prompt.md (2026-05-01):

Stai lavorando su un workspace locale e privato per ricerca/riparazione di un Sequential Circuits Prophet VS.

Obiettivo:
Trasformare i PDF/documenti scannerizzati di servizio in una knowledge base tecnica strutturata e leggibile, così che un altro agente di codice/analisi possa usarla più avanti per ragionare su possibili guasti, comportamento dei circuiti, posizione dei componenti, revisioni delle schede e passi diagnostici.

Importante:
- Non modificare i PDF originali.
- Non cancellare nulla.
- I documenti sorgente sono dentro la cartella: doc/
- Lavora solo dentro una nuova sottocartella: doc/prophet_vs_service_context/
- Questi PDF sono quasi tutti scansioni/immagini, quindi l’estrazione normale del testo potrebbe essere incompleta o vuota.
- Preferisci script riproducibili e file Markdown generati, invece di note manuali sparse.
- Sii molto esplicito sull’incertezza. Se l’OCR non è chiaro, marca il punto come [NON CHIARO] invece di indovinare.
- L’output finale deve essere utile anche senza riaprire i PDF originali.
- Non usare servizi remoti, API esterne o upload online. Tutto deve rimanere locale.

File sorgente:
- doc/sci_prophet_vs_ecr738.pdf
- doc/sci_prophet_vs_ecr739.pdf
- doc/pvs_service.pdf
- doc/5508.pdf
- doc/5530.pdf

Contesto:
Lo strumento è un Sequential Circuits Prophet VS. L’utente vuole indagare possibili problemi di riparazione, tra cui audio distorto o bleed con volume a zero, possibile contaminazione di CV/controlli, comportamento del circuito pressure/aftertouch, problemi sample & hold, revisioni scheda, riparazioni fatte male, piste sollevate, componenti che scaldano, problemi di alimentazione e percorsi diagnostici generali.

Task:

1. Crea struttura cartelle

Crea:

doc/prophet_vs_service_context/
  README.md
  index.md
  source_files.md
  extracted_text/
  page_images/
  page_notes/
  circuit_maps/
  diagnostic_notes/
  component_index/
  scripts/

2. Estrai ogni pagina PDF come immagine ad alta risoluzione

Scrivi uno script:

doc/prophet_vs_service_context/scripts/extract_pdf_pages.py

Usa Python.
Usa PyMuPDF/fitz se disponibile. Se non è disponibile, documenta la dipendenza mancante e fornisci istruzioni di installazione.

Per ogni PDF:
- renderizza ogni pagina ad alta risoluzione, circa 300 DPI se pratico
- salva PNG in:
  doc/prophet_vs_service_context/page_images/<nome_pdf_senza_estensione>/page_001.png
- crea un manifest JSON con:
  - nome PDF sorgente
  - numero pagine
  - percorsi immagini generate
  - dimensioni immagini
  - timestamp estrazione

3. Estrai testo / OCR dove possibile

Scrivi lo script:

doc/prophet_vs_service_context/scripts/extract_text_and_ocr.py

Prima prova l’estrazione testo nativa dal PDF.
Se il testo estratto è vuoto o quasi vuoto, prova OCR solo se esiste uno strumento OCR locale disponibile.
Non usare servizi remoti.
Se l’OCR non è disponibile, crea file placeholder che dicano che l’OCR non è disponibile e indicano il percorso dell’immagine pagina.

Per ogni pagina crea:

doc/prophet_vs_service_context/extracted_text/<nome_pdf>/page_001.txt

Formato file:

SOURCE: <pdf>
PAGE: <n>
METHOD: native_text | ocr | unavailable
CONFIDENCE: high | medium | low | unavailable

CONTENT:
...

4. Crea note tecniche per ogni pagina

Per ogni pagina crea:

doc/prophet_vs_service_context/page_notes/<nome_pdf>/page_001.md

Ogni nota deve includere:

# <nome PDF> pagina <n>

## Cosa sembra contenere questa pagina
Descrivi in italiano semplice se la pagina sembra essere:
- schema elettrico
- artwork PCB
- datasheet
- ECR / engineering change record
- BOM / lista modifiche
- layout
- pressure circuit
- sample & hold
- chorus
- keyboard matrix
- alimentazione
- cartridge board
- generazione waveform
- ecc.

## Etichette / componenti / IC / net visibili
Estrai tutto quello che è chiaramente leggibile:
- riferimenti IC: Uxxx
- resistenze/capacitori: Rxxx, Cxxx
- connettori: Pxxx, Jxxx
- rail: +5V, -5V, +12V, -12V, AGND, DGND
- net nominate: LEFT, RIGHT, PAN, LEV, VCA, VCF, PRESSURE, RESET, ecc.
- chip: CEM5530, PD508, 4051, TL08x, 7805, 7905, 5530, ecc.

## Riassunto funzione del circuito
Spiega cosa probabilmente fa il circuito, separando:
- Confermato dalle etichette
- Inferenza ragionevole
- Incerto / da verificare manualmente

## Rilevanza per riparazione
Elenca perché questa pagina è utile per diagnosticare un Prophet VS.

## Possibili failure mode collegati a questa pagina
Elenca solo guasti elettronici plausibili. Esempi:
- op amp guasto
- condensatore in perdita
- regolatore guasto
- saldatura crepata
- via/pista danneggiata
- sample & hold IC guasto
- problema rete resistiva pressure sensor
- ossidazione connettore
- problema ground analogico/digitale
- rail alimentazione basso o con ripple
- CV bleed da sample & hold droop
- valore resistenza ECR errato
- circuito keyboard/pressure danneggiato

## Cross-reference
Collega pagine correlate di altri PDF se evidente.

5. Crea source_files.md

Riassumi lo scopo di ogni PDF sorgente:

- doc/sci_prophet_vs_ecr738.pdf:
  ECR 738, engineering change record Sequential. Sembra relativo a Prophet VS PCB 2400 board 4 / circuito main analog sample & hold / sensor e modifiche resistenze pressure sensor.

- doc/sci_prophet_vs_ecr739.pdf:
  ECR 739, engineering change record Sequential. Sembra relativo a Prophet VS PCB 2400 board 3 / keyboard and power supply / pressure circuit changes.

- doc/pvs_service.pdf:
  Pacchetto schemi Prophet VS, inclusi keyboard matrix, pressure circuit, sample & hold/sensor, wave circuits, chorus, cartridge board, artwork/layout schede.

- doc/5508.pdf:
  Datasheet OnChip Systems PD508 Octal Sample & Hold.

- doc/5530.pdf:
  Datasheet preliminare CEM5530 30-channel Sample & Hold.

Marca ogni riassunto come basato sul materiale scannerizzato visibile e non garantito completo.

6. Crea index.md

Crea un indice navigabile raggruppato per argomento:

## Pressure / aftertouch circuit
Linka tutte le pagine rilevanti da:
- ECR738
- ECR739
- pvs_service
- eventuali sezioni datasheet utili a capire comportamento S&H/tensioni

## Sample & Hold / generazione CV
Linka:
- datasheet PD508
- datasheet CEM5530
- pagine schematiche Prophet VS che mostrano S&H, LEV, PAN, VCF, VCA, WAVE A-D, ecc.

## Audio path / VCA / filtri / chorus
Linka tutte le pagine pvs_service che riguardano:
- chorus left/right
- filtri 7 kHz
- percorso uscita analogica
- controlli VCA/filtro se visibili

## Keyboard / pannello / controlli
Linka:
- keyboard matrix
- pressure sensor
- pagine ECR scannerizzate

## Alimentazione / rail
Linka tutte le pagine che mostrano:
- trasformatore
- regolatori 7805/7905
- +5V, -5V, +12V, -12V
- reset circuits
- ground analogico/digitale

## Board artwork / riparazione fisica
Linka pagine layout/artwork PCB dagli ECR e dal service PDF.

7. Crea indice componenti

Crea questi file Markdown:

doc/prophet_vs_service_context/component_index/ics.md
doc/prophet_vs_service_context/component_index/resistors_caps.md
doc/prophet_vs_service_context/component_index/connectors.md
doc/prophet_vs_service_context/component_index/power_rails.md
doc/prophet_vs_service_context/component_index/named_nets.md

Ogni file deve contenere una tabella:

| Riferimento / Net | Visto in pagina sorgente | Funzione / contesto | Note / incertezza |

Esempi:
| U459 | sci_prophet_vs_ecr738 pagina 2 | Op amp vicino al circuito pressure sensor | Visibile nello schema; verificare parte/valore esatto |
| R458 | sci_prophet_vs_ecr738 pagina 2 | Resistenza modificata in ECR 738 | ECR dice cambiata da 2K a 15K, verificare sulla board |
| CEM5530 | 5530.pdf pagine 1-4 | IC 30-channel sample & hold | Importante per generazione CV/droop/bleed |

8. Crea mappe circuitali

Crea:

doc/prophet_vs_service_context/circuit_maps/pressure_aftertouch.md
doc/prophet_vs_service_context/circuit_maps/sample_hold_cv.md
doc/prophet_vs_service_context/circuit_maps/audio_path.md
doc/prophet_vs_service_context/circuit_maps/power_reset.md
doc/prophet_vs_service_context/circuit_maps/keyboard_matrix.md
doc/prophet_vs_service_context/circuit_maps/chorus.md
doc/prophet_vs_service_context/circuit_maps/board_revisions_ecr.md

Ogni mappa circuito deve includere:

## Ruolo nel Prophet VS
## Pagine/sorgenti
## Componenti importanti
## Rail importanti
## Flusso del segnale, per quanto leggibile
## Cosa può andare storto
## Come potrebbe collegarsi ai sintomi
## Cose da misurare in sicurezza
## Cose da non assumere

Per “cose da misurare in sicurezza”, suggerisci test point concettuali, non procedure invasive precise, a meno che siano chiaramente mostrate nello schema.

9. Crea una knowledge base diagnostica

Crea:

doc/prophet_vs_service_context/diagnostic_notes/README.md
doc/prophet_vs_service_context/diagnostic_notes/symptom_audio_at_volume_zero.md
doc/prophet_vs_service_context/diagnostic_notes/symptom_distorted_self_sound.md
doc/prophet_vs_service_context/diagnostic_notes/symptom_aftertouch_pressure_fault.md
doc/prophet_vs_service_context/diagnostic_notes/symptom_overheating_component.md
doc/prophet_vs_service_context/diagnostic_notes/symptom_cv_bleed_or_modulation_leak.md
doc/prophet_vs_service_context/diagnostic_notes/symptom_power_rail_problem.md
doc/prophet_vs_service_context/diagnostic_notes/visual_inspection_checklist.md
doc/prophet_vs_service_context/diagnostic_notes/safe_measurement_plan.md

Per ogni file sintomo usa questa struttura:

# Sintomo: <nome>

## Descrizione sintomo
## Aree circuito più rilevanti
## Pagine sorgente da ispezionare
## Possibili cause ordinate dalla più probabile alla meno probabile
## Quale evidenza supporterebbe ogni causa
## Quale evidenza la escluderebbe
## Misure/controlli da eseguire
## Aree scheda/componenti da ispezionare visivamente
## Rischi / cautele
## Domande per un tecnico

Per questo sintomo specifico:
“Prophet VS emette suono / bleed distorto anche con volume a zero; in alcune patch sembra passare LFO/modulazione anche con volume a zero.”

Considera possibili aree:
- leakage controllo VCA
- audio path dopo il volume control
- sezione output/chorus
- uscite CV sample & hold che perdono/droopano
- op amp o analog switch guasto
- ripple alimentazione
- problema ground
- riparazione precedente fatta male / pista sollevata
- problema connettore o jack
- contaminazione CV da pannello/controlli
- possibile problema CEM5530/PD508 o circuiti collegati alla generazione CV, se applicabile

Non diagnosticare nulla come certo. Crea un albero di ipotesi.

10. Analisi specifica ECR

Crea:

doc/prophet_vs_service_context/circuit_maps/board_revisions_ecr.md

Riassumi con attenzione ECR738 e ECR739.

Per ECR738:
- identifica il motivo dichiarato della modifica
- identifica piste/componenti cambiati se visibili
- elenca valori resistenze menzionati
- spiega perché le modifiche a tensione/resistenze del pressure sensor possono essere importanti
- elenca cosa un tecnico dovrebbe verificare fisicamente sulla scheda

Per ECR739:
- stessa struttura
- confronto con ECR738

Importante:
Non assumere che il Prophet VS dell’utente abbia o non abbia queste modifiche ECR.
Crea una checklist per verificare:
- revisione board
- presenza di piste tagliate
- jumper aggiunti
- valori resistenze
- qualità saldature
- corrispondenza con artwork PCB scannerizzato

11. README.md finale

README.md deve spiegare:

- Cosa contiene questa cartella
- Come sono state estratte le pagine
- Quanto è affidabile l’OCR
- Come navigare il materiale
- Da dove partire per diagnosi riparazione
- Avviso importante: non sostituisce un tecnico synth qualificato
- Avviso importante: sezioni alimentazione/mains possono essere pericolose
- Avviso importante: vecchie PCB possono danneggiarsi con calore eccessivo, forza, probe sbagliati o corti durante le misure

12. Regole qualità

- Non inventare valori componenti.
- Se non sei sicuro, scrivi [NON CHIARO].
- Usa link relativi.
- Usa nomi file esatti e numeri pagina.
- Ogni affermazione su un circuito deve puntare a una pagina sorgente.
- Tieni separati “confermato”, “inferito” e “speculativo”.
- Dai priorità all’utilità per la riparazione, non alla formattazione perfetta.
- Genera Markdown conciso ma completo. Evita muri di testo enormi.
- Alla fine stampa un breve riassunto dei file creati e i file più importanti da cui partire per la diagnosi.

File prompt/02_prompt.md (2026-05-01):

Ora usa la knowledge base generata in:

doc/prophet_vs_service_context/

per creare un briefing diagnostico mirato per un tecnico che deve lavorare su un Sequential Circuits Prophet VS.

Sintomo principale osservato:
- Con volume a zero, passa comunque qualcosa: suono, patch distorta o bleed audio.
- In alcune patch sembra passare un comportamento tipo LFO/modulazione anche con volume a zero.
- Nella foto locale `IMG_5543.jpg` si vede la board `PC2400-3 REV B` e tre dispositivi TO-220 fissati al case/dissipatore. L'utente li chiama "transistor", ma dai documenti sembrano i regolatori lineari della sezione alimentazione digital/keyboard:
  - `U301` = `7805`, rail `+5VD`
  - `U302` = `7812`, rail `+12V`
  - `U303` = `7912`, rail `-12V`
  La designator map `pvs_service` pagina 5 mostra questi tre TO-220 in ordine fisico sinistra->destra come `U301`, `U302`, `U303`; confermare comunque sulla serigrafia reale se visibile.
- Uno di questi tre regolatori scalda troppo: da dietro il case diventa molto caldo/brucia. E' stata aggiunta una ventola esterna come mitigazione, ma la causa non e' stata trovata.
- Quel regolatore e' gia stato sostituito con un componente piu capiente; quindi non trattare il regolatore stesso come causa certa. Considera invece carico eccessivo a valle, condensatore in perdita/corto, ponte/rectifier o filtro, rail sbilanciato, dissipazione anomala per tensione in ingresso, isolamento termico/mica/pasta termica, vite/dissipatore/case, ground o riparazione precedente.
- Potrebbero esserci riparazioni precedenti e alcune saldature/piste potrebbero richiedere ispezione.
- Lo strumento è rimasto inutilizzato per anni.
- L’utente vuole capire quali aree circuito possono plausibilmente causare questi sintomi prima di consegnarlo a un tecnico.

Foto utente da includere nel briefing:
- `IMG_5543.jpg`: area alimentazione `PC2400-3 REV B`, tre TO-220 su dissipatore/case, connettori e condensatori vicini.

Crea:

doc/prophet_vs_service_context/diagnostic_notes/technician_briefing_volume_zero_bleed.md

Struttura:

# Briefing tecnico: Prophet VS audio/modulazione che passa con volume a zero

## 1. Sintomo noto
Descrivi il sintomo senza sovradiagnosticare.
Includi anche il sintomo termico separato:
- case posteriore molto caldo in corrispondenza dei tre TO-220/regolatori
- uno dei regolatori scalda troppo
- e' gia stato sostituito con uno piu capiente, quindi il sospetto principale deve spostarsi sul circuito alimentato o sulle condizioni di dissipazione, non sul solo regolatore

## 2. Documenti/pagine sorgente più rilevanti
Elenca le note Markdown pagina per pagina e le immagini originali generate da ispezionare.
Includi esplicitamente:
- `IMG_5543.jpg`
- `doc/prophet_vs_service_context/page_notes/pvs_service/page_004.md`
- `doc/prophet_vs_service_context/page_images/pvs_service/page_004.png`
- `doc/prophet_vs_service_context/page_notes/pvs_service/page_005.md`
- `doc/prophet_vs_service_context/page_images/pvs_service/page_005.png`
- `doc/prophet_vs_service_context/page_notes/sci_prophet_vs_ecr739/page_004.md`
- `doc/prophet_vs_service_context/circuit_maps/power_reset.md`
- `doc/prophet_vs_service_context/component_index/ics.md`
- `doc/prophet_vs_service_context/component_index/power_rails.md`

## 3. Albero ipotesi ad alto livello
Separa in:

A. Percorso audio dopo il controllo volume
B. Problema VCA / control voltage
C. Leakage/droop/uscita errata dal sample & hold
D. Leakage sezione chorus/output o op amp guasto
E. Problema rail alimentazione / ground / reset
F. Problema CV keyboard/pressure/aftertouch
G. Riparazione precedente fatta male: solder bridge, pista sollevata, resistenza errata, pista tagliata, jumper errato
H. Problema normalizzazione connettori/jack
I. Surriscaldamento dei regolatori `U301/U302/U303` sul dissipatore/case

Per ogni ipotesi includi:
- Perché potrebbe essere compatibile con il sintomo
- Quale area dello schema ispezionare
- Quale misura o osservazione la supporterebbe
- Cosa la escluderebbe
- Componenti/net/pagine rilevanti dai documenti

## 4. Controlli sicuri e non invasivi da fare prima
Includi:
- ispezione visiva
- reinserimento/reseating connettori
- controllo corrosione/ruggine evidente intorno a MIDI/footswitch/aux/output
- controllo revisione board / modifiche ECR alle resistenze
- controllo rail alimentazione con la dovuta cautela
- test di ascolto: uscita dry vs chorus/output se applicabile
- inizializzazione patch / confronto tra patch inizializzata e factory patch
- comportamento del pot volume e capire se il segnale è prima o dopo il volume control
- identificazione visiva dei tre regolatori su `IMG_5543.jpg`: `U301 7805`, `U302 7812`, `U303 7912`; la designator map indica sinistra->destra `U301/U302/U303`, da confermare sulla PCB reale se la serigrafia e visibile
- controllo segni di stress termico intorno a `U301/U302/U303`, condensatori elettrolitici/tantalio vicini, ponte rettificatore/diodi e connettori
- controllo che vite, isolamento, rondella, pasta termica e contatto con dissipatore/case siano corretti

## 5. Misure per tecnico qualificato
Includi misure concettuali:
- rail +5, -5, +12, -12 e ripple
- per `U301 7805`, `U302 7812`, `U303 7912`: tensione ingresso, tensione uscita, ripple, caduta Vin-Vout, temperatura, corrente/carico se misurabile in sicurezza
- confronto temperatura tra i tre regolatori, senza concludere che quello piu caldo sia guasto
- controllo assorbimento a valle dei rail `+5VD`, `+12V`, `-12V`
- controllo di condensatori in perdita/corto o IC a valle che caricano il rail
- comportamento CV VCA quando volume è a zero
- uscite sample & hold per droop/rumore/livelli DC errati
- uscite op amp bloccate/saturate
- tensione circuito pressure sensor / valori resistenze
- continuità piste tagliate/jumper ECR
- continuità ground

Non dare istruzioni pericolose lato mains.

## 6. Rilevanza ECR738/ECR739
Spiega come le modifiche ECR su pressure sensor, resistenze e piste potrebbero o non potrebbero essere collegate al sintomo.
Dichiara chiaramente che questi ECR non sono automaticamente la causa, ma modifiche mancanti, sbagliate o fatte male potrebbero creare comportamenti strani nelle control voltage.

## 7. Componenti/aree da attenzionare
Crea una tabella:

| Area | Componenti/net | Perché rilevante | Pagina sorgente |

Usa solo componenti realmente trovati nell’indice generato.
La tabella deve includere una riga dedicata ai tre regolatori:
- `U301 7805`, `U302 7812`, `U303 7912`, rail `+5VD`, `+12V`, `-12V`, ordine fisico sinistra->destra dalla designator map `pvs_service pagina 5`, sorgenti `pvs_service pagina 4`, `sci_prophet_vs_ecr739 pagina 4`, foto `IMG_5543.jpg`.

## 8. Domande da fare al riparatore
Crea una checklist che l’utente può mandare a un tecnico:

- Puoi verificare se le modifiche ECR738/ECR739 sono presenti e fatte correttamente?
- Puoi controllare rail e ripple prima di sostituire IC a caso?
- Puoi verificare se il bleed è prima o dopo il potenziometro volume/output stage?
- Puoi controllare con oscilloscopio le linee CV rilevanti e il controllo VCA?
- Puoi ispezionare solder bridge, piste sollevate o riparazioni precedenti?
- Puoi identificare fisicamente i tre regolatori sul dissipatore/case (`U301/U302/U303`) e dirmi quale dei tre scalda?
- Puoi misurare Vin/Vout/ripple e caduta termica sui regolatori, e verificare se c'e' carico eccessivo a valle?
- Puoi controllare condensatori/diodi/ponte rettificatore e IC alimentati dal rail del regolatore caldo?
- Puoi verificare isolamento, vite, rondelle e pasta termica del regolatore sul dissipatore/case?
- Puoi confrontare il comportamento su patch inizializzata e factory patch?
- Puoi evitare recap generalizzato se le misure non indicano problemi ai condensatori?

## 9. Conclusione
Dai un ordine diagnostico più probabile, non una diagnosi singola fissa.
La conclusione deve trattare i due sintomi insieme ma senza forzarli:
- il bleed/distorsione puo essere audio/CV/S&H/output
- il regolatore caldo puo essere una causa comune se il rail e' rumoroso/basso o se un carico a valle disturba la macchina
- oppure possono essere due problemi separati

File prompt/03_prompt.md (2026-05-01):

Crea una mappa rapida di navigazione per la riparazione:

doc/prophet_vs_service_context/diagnostic_notes/quick_navigation_map.md

Usa anche il briefing gia' creato:

doc/prophet_vs_service_context/diagnostic_notes/technician_briefing_volume_zero_bleed.md

Mantieni separati due problemi che possono essere collegati ma non vanno forzati in una sola diagnosi:

- audio/modulazione/bleed che passa con volume a zero
- case/regolatore troppo caldo nella zona dei tre TO-220 fissati al dissipatore

I tre TO-220 della foto `IMG_5543.jpg` sono da trattare come regolatori lineari, non transistor generici:

- `U301` = `7805`, rail `+5VD`
- `U302` = `7812`, rail `+12V`
- `U303` = `7912`, rail `-12V`

La designator map `pvs_service` pagina 5 indica ordine fisico sinistra->destra `U301`, `U302`, `U303`; confermare comunque sulla serigrafia reale se visibile.

Deve rispondere in modo pratico a queste domande:

1. Se il problema è audio che passa con volume a zero, partire da queste pagine.
2. Se il problema è contaminazione CV/modulazione, partire da queste pagine.
3. Se il problema è pressure/aftertouch, partire da queste pagine.
4. Se il problema è instabilità alimentazione/rail, partire da queste pagine.
5. Se il problema è case caldo/regolatore che scalda troppo, partire da queste pagine.
6. Se il problema è riparazione precedente fatta male/pista sollevata/modifica ECR sbagliata, partire da queste pagine.
7. Se il problema è chorus/output, partire da queste pagine.

Per ogni punto includi:
- PDF sorgente
- numero pagina
- percorso immagine pagina generata
- percorso nota pagina generata
- perché questa pagina è importante
- cosa ispezionare per primo
- eventuale nota "non concludere automaticamente" quando il problema potrebbe avere cause multiple

Tieni il file corto, pratico e orientato a un tecnico.

Poi prepara una cartella consegnabile e pulita per il tecnico fuori da `doc/`:

tecnico/

Aggiorna anche un `README.md` nella root principale del progetto, con link ai file principali e una sintesi delle cause/fix.

Deve contenere solo materiale utile alla diagnosi:

- `01_problemi_e_fix/cause_e_fix.md` con cause possibili, verifiche e fix consigliati
- README operativo della cartella
- briefing tecnico `technician_briefing_volume_zero_bleed.md`
- mappa rapida `quick_navigation_map.md`
- checklist/ispezione/misure sicure
- mappe circuito concise
- indici componenti utili
- note pagina e immagini pagina solo delle pagine davvero rilevanti
- PDF sorgenti principali
  - includere anche `5508.pdf` come riferimento S&H, anche se non e' il primo PDF da aprire
- foto utente `IMG_5543.jpg`

Usa cartelle visualmente utili e non ripetere "Prophet VS" nel nome delle cartelle. Esempio:

- `01_problemi_e_fix/`
- `02_checklist_misure/`
- `03_mappe_circuito/`
- `04_componenti_net_rail/`
- `05_pagine_rilevanti/`
- `06_pdf_originali/`
- `foto/`

Non includere:

- cartella `prompt/`
- script di estrazione
- OCR grezzo `extracted_text/`
- manifest JSON
- cache o file di sistema
- pagine/immagini non citate dalla mappa o dal briefing

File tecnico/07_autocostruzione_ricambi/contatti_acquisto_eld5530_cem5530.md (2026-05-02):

# Contatti per chiedere 2 ELD5530 / CEM5530 replacement

Data ricerca: 2026-05-02.

Obiettivo: trovare due moduli sostitutivi per `CEM5530` del Sequential Circuits Prophet VS, posizioni `U449` e `U425`.

Nota importante: `ELD5530` e' il ricambio Synthelectro/Eric Penot. Con gli altri contatti non chiamarlo necessariamente `ELD5530`: chiedere "CEM5530 replacement modules" o "CEM5530 clone modules" compatibili Prophet VS.

Aggiornamento: sono stati trovati in casa due moduli `Straylight Engineering X5530` con quattro `SMP18` per scheda. Prima di comprare altri ricambi, vedere `straylight_x5530_moduli_trovati.md` e farli verificare al tecnico.

## Priorita contatti

| Priorita | Contatto | Cosa chiedere | Canale | Fonte/nota |
| --- | --- | --- | --- | --- |
| 1 | Eric Penot / Synthelectro | 2 veri `ELD5530 V2` per Prophet VS `U449/U425` | `synthelectro@netcourrier.com` | Email pubblicata da Synthelectro nei commenti 2015: `https://synthelectro-fr.blogspot.com/2015/07/how-to-upgrade-programm-memory-of.html` |
| 2 | Straylight Engineering / Tom Virostek | 2 `CEM5530 replacement modules`; non sono ELD ma sono ricambi moderni gia documentati | Contact form: `https://www.straylightengineering.com/contact/` | Straylight 2023 diceva di avere `CEM5530 replacement modules`; pagina 2020 indicava `75 USD` cad.: `https://www.straylightengineering.com/update-jan-2023/`, `https://www.straylightengineering.com/what-a-year/` |
| 3 | Syntaur | 2 `IC, CEM5530 clone`, part `#7012`; verificare stock reale e spedizione in Italia | Shop/contact Syntaur: `https://syntaur.com/keyboard.php?keyboard=Sequential_Prophet+VS`, telefono `+1 830-627-1530`, contact page `https://syntaur.com/contact.html` | Pagina Prophet VS lista `IC, CEM5530 clone $139.95 (Part #7012)` |
| 4 | Wine Country Sequential / SequentialCircuits.com | Chiedere se resta qualche daughterboard/clone `CEM5530` o ricambio compatibile, oppure una pista ufficiale | `Sales@WineCountrySequential.com`; per riparazioni storiche `Repairs@WineCountrySequential.com` | Wine Country sta liquidando ricambi; sales email pubblicata su SequentialCircuits.com: `https://sequentialcircuits.com/sequentialcircuitsends.html` |
| 5 | D.L.S.E. / Synthrepair | Chiedere stock NOS/pull `CEM5530`, eventuali cloni o indicazioni europee | `INFO@DLSE.NL`, `INFO@SYNTHREPAIR.COM`, telefono `+31-653-846722` | Il sito dichiara stock di molti ricambi rari e contatti: `https://www.dlse.nl/info.html` |
| 6 | Synthtaste Germany | Chiedere se possono fornire/installare moduli compatibili Prophet VS o indicare fonte EU | `post@synthtaste.com`, telefono `+49 160 96456505` | Fanno service Prophet VS/VS Rack: `https://www.synthtaste.com/en/synth-service-product-upgrades/sequential-circuit-service` |
| 7 | Sequential official support | Chiedere se conoscono un service partner o fonte attuale per `CEM5530 replacement modules` | `support@sequential.com`, telefono `+1 415 830 6393 x1` | Supporto ufficiale Sequential: `https://sequential.com/support/contact-support/` |
| 8 | Reverb seller "Sounds Good" | Chiedere via Reverb se hanno ancora moduli Straylight extra o altri `CEM5530 clone` | Messaggio venditore nella vecchia inserzione Reverb | Inserzione venduta riportava 3 Straylight replacements acquistati come backup: `https://reverb.com/item/70333060-cem-5530-clone-sequential-prophet-vs` |

## Email 1 - Synthelectro / veri ELD5530

Subject:

```text
Two ELD5530 V2 modules for Sequential Prophet VS
```

Body:

```text
Hello Eric,

I own a Sequential Circuits Prophet VS and I am looking for two ELD5530 V2
replacement modules for the original CEM5530 chips, positions U449 and U425.

I found your Synthelectro post about the CEM5530 replacement for Prophet VS
and Studio 440. Are two ELD5530 V2 modules still available?

If yes, could you please confirm:

- price for two modules;
- shipping cost to Italy;
- payment method;
- installation notes;
- pin-1 orientation;
- height clearance inside the Prophet VS;
- whether replacing the original double-lyre sockets with quality tulip sockets
  is recommended before installation;
- whether you recommend replacing both CEM5530 modules at the same time.

If the modules are no longer available, would you be willing to share or sell
the schematic, PCB/Gerber files, BOM, or enough documentation for my technician
to build two replacement modules?

Thank you very much,

[Your name]
Italy
```

## Email 2 - Straylight / Syntaur / Wine Country / ricambi compatibili

Subject:

```text
Two CEM5530 replacement modules for Sequential Prophet VS
```

Body:

```text
Hello,

I own a Sequential Circuits Prophet VS and I am looking for two replacement
modules for the original CEM5530 sample-and-hold chips, positions U449 and U425.

Do you currently have two CEM5530 replacement/clone modules available?

If yes, could you please confirm:

- price for two modules;
- shipping cost to Italy;
- payment method;
- compatibility with Prophet VS keyboard, positions U449 and U425;
- installation notes;
- pin-1 orientation;
- height clearance;
- whether replacing the original double-lyre sockets with quality tulip sockets
  is recommended;
- whether the modules are tested before shipping.

If you do not have modules available, do you know a reliable current source for
two Prophet VS compatible CEM5530 replacement modules?

Thank you very much,

[Your name]
Italy
```

## Email 3 - Tecnici / stockisti EU

Subject:

```text
Looking for two CEM5530 replacements for Sequential Prophet VS
```

Body:

```text
Hello,

I am repairing a Sequential Circuits Prophet VS and need two replacements for
the original CEM5530 sample-and-hold chips, positions U449 and U425.

I am looking for one of the following:

- two ELD5530 modules;
- two Straylight or other modern CEM5530 replacement modules;
- two tested original CEM5530 chips;
- or a reliable source for any of the above.

Do you have any available, or can you recommend a current source in Europe?

The instrument is in Italy. I can provide board photos if useful.

Thank you,

[Your name]
Italy
```

## Messaggio breve per Reverb

```text
Hello,

I saw your sold listing for CEM5530 clone / Straylight replacements for the
Sequential Prophet VS. Do you still have any available, or do you know a source
for two modules?

I need two for a Prophet VS, positions U449 and U425, shipped to Italy.

Thank you.
```

## Prima di pagare

Chiedere sempre:

- foto fronte/retro del modulo;
- conferma compatibilita' Prophet VS `U449/U425`;
- pin 1/orientamento;
- altezza massima;
- se serve cambiare socket;
- se i moduli sono testati;
- politica in caso di DOA;
- costo spedizione e dogana/VAT;
- numero tracking.

Non comprare moduli anonimi senza foto e senza conferma installazione Prophet VS.

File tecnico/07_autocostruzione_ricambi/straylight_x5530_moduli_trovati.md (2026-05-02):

# Moduli Straylight X5530 trovati

Data nota: 2026-05-02.

## Identificazione dalla foto

La foto utente mostra due schede verdi marchiate:

- `X5530`;
- `Straylight Engineering`;
- data/lotto visibile `2018`;
- quattro IC Analog Devices `SMP18` per scheda.

Conclusione pratica: questi sembrano **due moduli Straylight Engineering X5530**, cioe' moduli sostitutivi/cloni per `CEM5530`.

Non sono `ELD5530` Synthelectro e non sono il prototipo `MAX5167` della repo. Sono una terza pista concreta, probabilmente gia' pronta all'uso se integra e correttamente compatibile.

## Perche sono compatibili come architettura

Il `CEM5530` originale e' un sample & hold multiplexato a `30` canali.

Ogni `SMP18` e' un sample & hold ottale, quindi:

```text
4 x SMP18 = 4 x 8 canali = 32 canali
```

Questo combacia con l'idea di sostituire un `CEM5530` a `30` canali usando quattro IC ottali e lasciando due canali non usati o gestiti dalla logica della scheda.

Fonte IC: Analog Devices descrive `SMP18` come `Fast Acquisition Octal Sample-and-Hold with Multiplexed Input`: `https://www.analog.com/en/products/smp18.html`

Fonte modulo: Straylight Engineering documenta una nuova board clone `5530` prodotta come PCB a 4 layer/factory assembled: `https://www.straylightengineering.com/5530-clone-boards-available-new-design/`

## Cosa cambia per il piano

Se questi due moduli sono fisicamente integri, la priorita' cambia:

1. non comprare subito `ELD5530` o altri cloni;
2. far verificare questi due moduli al tecnico;
3. contattare Straylight solo per confermare istruzioni, orientamento e note installazione se necessario;
4. usare il progetto `MAX5167` solo come backup/documentazione, non come prima strada.

Il Prophet VS usa due `CEM5530`, in posizioni `U449` e `U425`. Quindi una coppia di moduli `X5530` e' potenzialmente il set completo richiesto dalla macchina.

## Controlli prima di montarli

Non montarli direttamente solo perche sembrano corretti.

Chiedere al tecnico di verificare:

- foto fronte/retro e laterale di entrambi i moduli;
- presenza e rettilineita' dei pin maschio;
- nessun pin piegato, ossidato o spezzato;
- nessun corto visibile tra pin o saldature;
- nessun componente staccato o scheda flessa;
- verso pin 1 del modulo e verso pin 1 del socket `CEM5530`;
- compatibilita' meccanica con lo spazio disponibile sopra `U449/U425`;
- stato dei socket originali Prophet VS: se double-lyre fragili, valutare socket tulip di qualita';
- continuita' di base su alimentazioni e GND prima dell'inserimento;
- eventuale assorbimento anomalo con test fuori macchina, se il tecnico ha fixture adatta.

## Dissipatori sui cloni X5530

Non aggiungere automaticamente i dissipatori pensati per i `CEM5530` originali.

Il consiglio dei dissipatori riguarda soprattutto il chip originale in package lungo `40` pin, che concentra calore su un solo corpo DIP. Il modulo `X5530` e' diverso:

- usa quattro `SMP18` SOIC distribuiti sulla scheda;
- la dissipazione e' divisa su piu IC e sulla PCB;
- un dissipatore `40-DIP` non si applica meccanicamente al modulo;
- piccoli dissipatori incollati sui singoli SOIC possono toccare pin, aumentare altezza o stressare le saldature.

Quindi, salvo istruzioni Straylight o misura termica reale:

1. montare il modulo senza dissipatori aggiunti;
2. verificare temperatura dopo accensione controllata;
3. confrontare i due moduli tra loro;
4. se un `SMP18` o una zona della scheda scalda molto piu dell'altra, spegnere e diagnosticare rail/orientamento/modulo;
5. non incollare dissipatori permanenti prima di avere misure.

Una leggera temperatura sui `SMP18` puo' essere normale. Un modulo troppo caldo al tatto, con assorbimento anomalo o rail che crollano, non va "curato" col dissipatore: va spento e diagnosticato.

## Installazione raccomandata

Sequenza prudente:

1. diagnosticare se il problema riguarda `U449`, `U425` o entrambi;
2. salvare foto dei `CEM5530` originali montati, con orientamento pin 1;
3. spegnere e scollegare completamente il Prophet VS;
4. rimuovere un solo `CEM5530` alla volta;
5. se il socket e' fragile, sostituirlo prima di provare il modulo;
6. inserire un solo `X5530`, rispettando pin 1;
7. accendere con controllo corrente/temperatura;
8. verificare rail, CV e comportamento audio;
9. solo dopo ripetere sul secondo socket.

## Nota acquisti

Con questi due moduli in mano, le email di acquisto diventano secondarie.

Usare `contatti_acquisto_eld5530_cem5530.md` solo per:

- chiedere conferma installazione a Straylight;
- comprare ricambi solo se questi moduli risultano danneggiati;
- cercare un secondo set di backup.

## Da comunicare al tecnico

Messaggio breve:

```text
I found two Straylight Engineering X5530 modules dated 2018.
They appear to be CEM5530 replacement modules based on four Analog Devices SMP18
octal sample-and-hold ICs per board. Please verify pin-1 orientation, socket
condition, mechanical clearance, shorts, and basic power/GND continuity before
installing them in U449/U425.
```

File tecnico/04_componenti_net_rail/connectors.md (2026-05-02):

# Connettori e test point utili

| Riferimento | Area | Perche interessa | Sorgenti |
| --- | --- | --- | --- |
| `P402/P403` | Main analog S&H / pressure | Interconnessione tra sensor, CV e rail; utile per tracciamento non invasivo | pvs_service pagina 6 |
| `P302/P305` | Digital/analog interconnect | Collegano aree keyboard/power e analog/S&H; ossidazione o falso contatto puo' creare sintomi strani | pvs_service pagine 4/6 |
| `P303` | Keyboard/power | Visibile nella sezione pressure/power | pvs_service pagina 4, ECR739 pagina 4 |
| `P901`, `P3908`, `P4093` | Output/chorus/audio | Utili se il difetto cambia tra uscite o canali | pvs_service pagine 9/11 |
| `TP301/TP302` | Pressure circuit | Test point legati a pressure/sensor; utili per verificare ECR e comportamento aftertouch | pvs_service pagina 4, ECR739 pagina 4 |
| 4 jack 1/4" posteriori | Output audio e footswitch | Ossido o normalizzazione difettosa puo' introdurre rumore, bleed o falsi contatti; non sono tutti equivalenti elettricamente | Vedi `../01_problemi_e_fix/jack_sostituzione.md` |
| 3 porte MIDI DIN | `MIDI IN`, `MIDI OUT`, `MIDI OUT/THRU` | Corrosione o contatti laschi possono bloccare MIDI; la nuova foto mostra una DIN diversa dai Jalco PCB moderni linkati inizialmente. Prima pista ricambio: famiglia Switchcraft `57NC5FX` / `57GB5FX` / `57PC5F`, da misurare | pvs_service pagina 3; foto `../foto/midi_din_originale_01.JPG`; vedi `../01_problemi_e_fix/pannello_posteriore_ricambi.md` |
| Eventuale slide switch `MIDI OUT/THRU` | Selettore OUT/THRU vicino alla porta MIDI | Se presente fisicamente sulla macchina, cercare un SP3T/right-angle low-current con stesso footprint; non dedurre dal solo schema | Verifica fisica; vedi `../01_problemi_e_fix/pannello_posteriore_ricambi.md` |
| `S1/S2/F1` posteriori | Power switch, selettore tensione, fuse | Nota separata: se anche questi fossero rugginosi sono mains e vanno trattati con cautela | pvs_service pagina 4 |

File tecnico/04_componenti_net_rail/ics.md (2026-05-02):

# IC e regolatori utili

| Riferimento | Area | Perche interessa | Sorgenti |
| --- | --- | --- | --- |
| `U301 7805` | Alimentazione digital/keyboard | Regolatore `+5VD`; uno dei tre TO-220 sul dissipatore/case | pvs_service pagina 4/5, ECR739 pagina 4 |
| `U302 7812` | Alimentazione digital/keyboard | Regolatore `+12V`; uno dei tre TO-220 sul dissipatore/case | pvs_service pagina 4/5, ECR739 pagina 4 |
| `U303 7912` | Alimentazione digital/keyboard | Regolatore `-12V`; uno dei tre TO-220 sul dissipatore/case | pvs_service pagina 4/5, ECR739 pagina 4 |
| `U304 78L05` | Alimentazione/reset | Regolatore locale nella sezione keyboard/power | pvs_service pagina 4, ECR739 pagina 4 |
| `U305 HC132` | Reset/logica | Reset gate; rail instabili possono creare comportamenti digitali strani | pvs_service pagina 4, ECR739 pagina 4 |
| `U310` | Pressure circuit | Op amp/IC nel circuito pressure lato keyboard/power | pvs_service pagina 4, ECR739 pagina 4 |
| `U459` | Pressure sensor | Op amp pressure lato main analog/S&H; vicino a R458/ECR738 | pvs_service pagina 6, ECR738 pagina 2 |
| `U449/U425 CEM5530` | Sample & hold / CV | Generano CV `VCA/VCF/PAN/LEV` e chorus/final CV; noti come punto fragile del Prophet VS; vedi `../01_problemi_e_fix/cem5530_diagnosi_ricambi.md` | pvs_service pagina 6, 5530 pagine 1/3/4 |
| SRAM patch + batteria | Memoria programmi | Le SRAM originali restano alimentate dalla batteria a synth spento; `ELD5530` non cambia questa parte; vedi `../01_problemi_e_fix/batteria_memoria_nvram.md` | pvs_service CPU/memoria, Synthelectro 2015 |
| `5508.pdf` | Riferimento S&H | Datasheet S&H supplementare utile per concetti di hold/droop/timing; non prova che PD508/5508 sia montato nello strumento | PDF in `06_pdf_originali/` |
| `U451` | DAC/riferimento S&H | Parte del percorso DAC verso CEM5530 | pvs_service pagina 6 |
| `U453/U454` | Timing/logica S&H | Logica associata a controllo/timing CV | pvs_service pagina 6 |
| `U401 7905`, `U402 78M05`, `U450 78M08` | Rail analogici locali | Generano rail locali per S&H/CV; ripple qui puo' causare CV errate | pvs_service pagina 6 |
| `U455-U458` | VCF/VCA/PAN audio path | Area diretta per bleed, VCA che non chiude o audio distorto | pvs_service pagina 9 |
| `U903/U904/U920` | Chorus/output | Output/chorus left-right; possibile bleed dopo volume | pvs_service pagina 11 |
| `TL082` | Output/lowpass | Op amp nel percorso output/right/lowpass | pvs_service pagina 12 |

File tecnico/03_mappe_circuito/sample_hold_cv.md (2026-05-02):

# Sample & Hold / CV Generation

## Ruolo nel Prophet VS
Mappa di lavoro per diagnosi e lettura incrociata. Le affermazioni sotto derivano dalle pagine/sorgenti linkate.

## Pagine/sorgenti
- [pvs_service pagina 6](../05_pagine_rilevanti/note/pvs_service/page_006.md)
- [pvs_service pagina 9](../05_pagine_rilevanti/note/pvs_service/page_009.md)
- [5530 pagina 1](../05_pagine_rilevanti/note/5530/page_001.md)
- [5530 pagina 2](../05_pagine_rilevanti/note/5530/page_002.md)
- [5530 pagina 3](../05_pagine_rilevanti/note/5530/page_003.md)
- [5530 pagina 4](../05_pagine_rilevanti/note/5530/page_004.md)
- [CEM5530: diagnosi, ricambi e dissipazione](../01_problemi_e_fix/cem5530_diagnosi_ricambi.md)
- PDF supplementare: [5508.pdf](../06_pdf_originali/5508.pdf), utile come riferimento S&H generico ma non trattato come prova che quel chip sia montato nel Prophet VS esaminato.

## Componenti importanti
U449/U425 CEM5530, DAC/U451 6012, U453/U454 HC174 e concetti CEM5530/5508 per hold, droop e timing.

Nota pratica: `U449/U425` sono anche componenti storicamente fragili; prima di sostituirli controllare rail/timing/socket/piste, e valutare dissipatori o cloni solo con conferma strumentale. Per i dissipatori sui due `CEM5530`, usare due pezzi bassi, circa `50-51 x 13-14 x 5 mm`, con pad/tape termico se non integrato; dettagli e link sono in `../01_problemi_e_fix/cem5530_diagnosi_ricambi.md`.

## Rail importanti
+12V, -12V, +8V, +5.6V, -5V, +5VD, VDD/VSS/VREF.

## Flusso del segnale, per quanto leggibile
Digital data/address/timing -> DAC/reference -> CEM5530 input/inhibit/address -> held CV outputs such as VCA, VCF, PAN, LEV, chorus/final CV.

## Cosa puo andare storto
- Op amp o IC guasto, condensatore in perdita, saldatura crepata, via/pista danneggiata, connettore ossidato.
- Rail basso/con ripple o ground analogico/digitale disturbato.
- Valori ECR errati, jumper/tagli non documentati o riparazioni precedenti malfatte.

## Come potrebbe collegarsi ai sintomi
CV droop, modulation leak, VCA not closing, pan/level drift, distorted control voltages, output bleed with volume low.

## Cose da misurare in sicurezza
- Verificare concettualmente i rail indicati nelle pagine sorgente prima di inseguire segnali piccoli.
- Confrontare ground analogico/digitale solo come da schema e senza creare corti accidentali.
- Osservare uscite/ingressi etichettati nelle pagine linkate con strumenti adeguati e massa corretta.
- Nelle aree mains/trasformatore, operare solo con tecnico qualificato e isolamento appropriato.

## Cose da non assumere
- Non assumere che le modifiche ECR738/ECR739 siano presenti sullo strumento reale.
- Non assumere valori OCR se l'immagine non li conferma chiaramente.
- Non sostituire componenti per somiglianza del sintomo senza prova elettrica o ispezione fisica.

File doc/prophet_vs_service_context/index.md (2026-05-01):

# Prophet VS service context index

## Pressure / aftertouch circuit
- [ECR738 pressure sensor modification](page_notes/sci_prophet_vs_ecr738/page_002.md)
- [ECR739 pressure circuit / power supply](page_notes/sci_prophet_vs_ecr739/page_004.md)
- [Digital keyboard and power supply: pressure circuit](page_notes/pvs_service/page_004.md)
- [Main analog sample & hold / sensor](page_notes/pvs_service/page_006.md)
- [CEM5530 overview, CV generation context](page_notes/5530/page_001.md)

## Sample & Hold / generazione CV
- [Main analog S&H/sensor, CEM5530 outputs](page_notes/pvs_service/page_006.md)
- [Main analog wave/CV area](page_notes/pvs_service/page_007.md)
- [Main analog wave/voice area](page_notes/pvs_service/page_008.md)
- [VCF/VCA/PAN audio/CV area](page_notes/pvs_service/page_009.md)
- [PD508 overview](page_notes/5508/page_001.md)
- [PD508 specifications](page_notes/5508/page_002.md)
- [PD508 timing](page_notes/5508/page_003.md)
- [PD508 input/output](page_notes/5508/page_004.md)
- [CEM5530 overview](page_notes/5530/page_001.md)
- [CEM5530 application hints](page_notes/5530/page_003.md)
- [CEM5530 timing](page_notes/5530/page_004.md)

## Audio path / VCA / filtri / chorus
- [CV outputs for VCA/VCF/PAN/LEV and chorus/final CV](page_notes/pvs_service/page_006.md)
- [Main analog VCF/VCA/PAN](page_notes/pvs_service/page_009.md)
- [Audio output / chorus area](page_notes/pvs_service/page_011.md)
- [Right voices / 7 kHz lowpass / output](page_notes/pvs_service/page_012.md)

## Keyboard / pannello / controlli
- [Left front panel controls](page_notes/pvs_service/page_001.md)
- [Right front panel and cartridge](page_notes/pvs_service/page_002.md)
- [Keyboard matrix / pressure](page_notes/pvs_service/page_004.md)
- [Pressure/keyboard/power ECR page](page_notes/sci_prophet_vs_ecr739/page_004.md)

## Alimentazione / rail
- [Digital keyboard and power supply](page_notes/pvs_service/page_004.md)
- [Main analog local regulators and analog rails](page_notes/pvs_service/page_006.md)
- [Digital reset/clock/bus](page_notes/pvs_service/page_003.md)
- [Power supply and reset on ECR739](page_notes/sci_prophet_vs_ecr739/page_004.md)
- [CEM5530 power supply limits](page_notes/5530/page_003.md)

## Board artwork / riparazione fisica
- [Digital/keyboard PCB artwork/layout](page_notes/pvs_service/page_005.md)
- [Main analog PCB artwork/layout](page_notes/pvs_service/page_010.md)
- [ECR738 artwork/layout reference](page_notes/sci_prophet_vs_ecr738/page_003.md)
- [ECR739 support page, low confidence](page_notes/sci_prophet_vs_ecr739/page_002.md)

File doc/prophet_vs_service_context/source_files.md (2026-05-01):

# Source files

Ogni riassunto e' basato sul materiale scannerizzato visibile e sull'OCR locale; non e' garantito completo.

| File | Scopo apparente | Affidabilita |
| --- | --- | --- |
| `doc/sci_prophet_vs_ecr738.pdf` | ECR 738, engineering change record Sequential. Sembra relativo a Prophet VS PCB 2400/main analog sample & hold / sensor e modifiche al pressure sensor. | Medio/basso: scansione chiara solo in parte; pagina 2 mostra il dettaglio piu utile. |
| `doc/sci_prophet_vs_ecr739.pdf` | ECR 739, engineering change record Sequential. Sembra relativo a Prophet VS PCB 2400 digital/keyboard/power supply e pressure circuit changes. | Medio/basso: pagina 4 e' la piu leggibile; pagine 2-3 sono poco chiare. |
| `doc/pvs_service.pdf` | Pacchetto schemi Prophet VS: front panel, cartridge, digital processor, keyboard/power/pressure, main analog sample & hold/sensor, voice/audio/chorus/output e artwork/layout. | Medio: OCR rumoroso ma immagini renderizzate sono leggibili. |
| `doc/5508.pdf` | Datasheet OnChip Systems PD508 Octal Sample & Hold. | Medio: OCR leggibile; verificare formule e tabelle sull'immagine. |
| `doc/5530.pdf` | Datasheet preliminare CEM5530 30-channel Sample & Hold. | Medio: pagine 1, 3, 4 leggibili; pagina 2/pinout richiede verifica immagine. |

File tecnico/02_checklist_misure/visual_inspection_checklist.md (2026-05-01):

# Visual inspection checklist

## Prima di alimentare
- Cercare componenti anneriti, crepati, montati al contrario o con valore non coerente con le ECR.
- Cercare pad sollevati, piste tagliate, jumper volanti, fili stressati e saldature fredde.
- Ispezionare connettori P/J/TB citati nelle page note e jack/output.
- Verificare zone pressure sensor, regolatori, main analog S&H e audio output.

## Dopo confronto con documenti
- Confrontare board revision con ECR738/ECR739.
- Verificare R458, R321, R307/R308/R309/R320/R304 solo con riferimento immagine e misura fisica.
- Marcare ogni punto non leggibile come [NON CHIARO], non indovinare.

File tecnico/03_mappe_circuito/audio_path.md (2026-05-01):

# Audio Path / VCA / VCF / Output

## Ruolo nel Prophet VS
Mappa di lavoro per diagnosi e lettura incrociata. Le affermazioni sotto derivano dalle pagine/sorgenti linkate.

## Pagine/sorgenti
- [pvs_service pagina 6](../05_pagine_rilevanti/note/pvs_service/page_006.md)
- [pvs_service pagina 9](../05_pagine_rilevanti/note/pvs_service/page_009.md)
- [pvs_service pagina 11](../05_pagine_rilevanti/note/pvs_service/page_011.md)
- [pvs_service pagina 12](../05_pagine_rilevanti/note/pvs_service/page_012.md)

## Componenti importanti
VCF/VCA/PAN/LEV CV outputs, op amps on audio pages, left/right voice/output sections, 7 kHz lowpass section.

## Rail importanti
+12V, -12V, AGND and any local analog rails shown on the page images.

## Flusso del segnale, per quanto leggibile
Voice/filter/VCA stages -> pan/left/right routing -> chorus/output/filter stages. CV from S&H controls VCA/VCF/PAN/LEV.

## Cosa puo andare storto
- Op amp o IC guasto, condensatore in perdita, saldatura crepata, via/pista danneggiata, connettore ossidato.
- Rail basso/con ripple o ground analogico/digitale disturbato.
- Valori ECR errati, jumper/tagli non documentati o riparazioni precedenti malfatte.

## Come potrebbe collegarsi ai sintomi
Bleed with volume at zero can come from VCA control leakage, audio coupling after volume, output/chorus leakage, op amp bias issues, rail ripple, or bad ground.

## Cose da misurare in sicurezza
- Verificare concettualmente i rail indicati nelle pagine sorgente prima di inseguire segnali piccoli.
- Confrontare ground analogico/digitale solo come da schema e senza creare corti accidentali.
- Osservare uscite/ingressi etichettati nelle pagine linkate con strumenti adeguati e massa corretta.
- Nelle aree mains/trasformatore, operare solo con tecnico qualificato e isolamento appropriato.

## Cose da non assumere
- Non assumere che le modifiche ECR738/ECR739 siano presenti sullo strumento reale.
- Non assumere valori OCR se l'immagine non li conferma chiaramente.
- Non sostituire componenti per somiglianza del sintomo senza prova elettrica o ispezione fisica.

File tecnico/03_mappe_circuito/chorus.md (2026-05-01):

# Chorus / Output Control

## Ruolo nel Prophet VS
Mappa di lavoro per diagnosi e lettura incrociata. Le affermazioni sotto derivano dalle pagine/sorgenti linkate.

## Pagine/sorgenti
- [pvs_service pagina 6](../05_pagine_rilevanti/note/pvs_service/page_006.md)
- [pvs_service pagina 9](../05_pagine_rilevanti/note/pvs_service/page_009.md)
- [pvs_service pagina 11](../05_pagine_rilevanti/note/pvs_service/page_011.md)
- [pvs_service pagina 12](../05_pagine_rilevanti/note/pvs_service/page_012.md)

## Componenti importanti
LEFT CHORUS CV, RIGHT CHORUS CV, chorus LEDs/status, left/right output pages, op amps and filters on C9xx/R9xx pages.

## Rail importanti
+12V, -12V, +5VD for control, AGND.

## Flusso del segnale, per quanto leggibile
Front panel/status/control lines enable chorus; analog audio path routes left/right through chorus/output/filter sections.

## Cosa puo andare storto
- Op amp o IC guasto, condensatore in perdita, saldatura crepata, via/pista danneggiata, connettore ossidato.
- Rail basso/con ripple o ground analogico/digitale disturbato.
- Valori ECR errati, jumper/tagli non documentati o riparazioni precedenti malfatte.

## Come potrebbe collegarsi ai sintomi
Distorted self-sound, channel imbalance, bleed after volume, chorus stuck on/off, noisy output.

## Cose da misurare in sicurezza
- Verificare concettualmente i rail indicati nelle pagine sorgente prima di inseguire segnali piccoli.
- Confrontare ground analogico/digitale solo come da schema e senza creare corti accidentali.
- Osservare uscite/ingressi etichettati nelle pagine linkate con strumenti adeguati e massa corretta.
- Nelle aree mains/trasformatore, operare solo con tecnico qualificato e isolamento appropriato.

## Cose da non assumere
- Non assumere che le modifiche ECR738/ECR739 siano presenti sullo strumento reale.
- Non assumere valori OCR se l'immagine non li conferma chiaramente.
- Non sostituire componenti per somiglianza del sintomo senza prova elettrica o ispezione fisica.

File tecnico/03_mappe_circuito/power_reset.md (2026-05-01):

# Power / Reset

## Ruolo nel Prophet VS
Mappa di lavoro per diagnosi e lettura incrociata. Le affermazioni sotto derivano dalle pagine/sorgenti linkate.

## Pagine/sorgenti
- [pvs_service pagina 4](../05_pagine_rilevanti/note/pvs_service/page_004.md)
- [pvs_service pagina 6](../05_pagine_rilevanti/note/pvs_service/page_006.md)
- [sci_prophet_vs_ecr739 pagina 4](../05_pagine_rilevanti/note/sci_prophet_vs_ecr739/page_004.md)
- [5530 pagina 3](../05_pagine_rilevanti/note/5530/page_003.md)

## Componenti importanti
U301 7805, U302 7812, U303 7912, U304 78L05, U401 7905, U402 78M05, U450 78M08, reset gates U305/HC132, transformer/rectifier area.

## Rail importanti
+5VD, +12V, -12V, +8V, +5.6V, -5V, AGND/DGND.

## Flusso del segnale, per quanto leggibile
Transformer/rectifiers/regulators generate digital and analog rails; reset logic depends on supply behavior.

## Cosa puo andare storto
- Op amp o IC guasto, condensatore in perdita, saldatura crepata, via/pista danneggiata, connettore ossidato.
- Rail basso/con ripple o ground analogico/digitale disturbato.
- Valori ECR errati, jumper/tagli non documentati o riparazioni precedenti malfatte.

## Come potrebbe collegarsi ai sintomi
Low/rippled rails can cause distortion, CV error, digital mis-refresh, reset instability, heat, or audio hum/bleed.

## Cose da misurare in sicurezza
- Verificare concettualmente i rail indicati nelle pagine sorgente prima di inseguire segnali piccoli.
- Confrontare ground analogico/digitale solo come da schema e senza creare corti accidentali.
- Osservare uscite/ingressi etichettati nelle pagine linkate con strumenti adeguati e massa corretta.
- Nelle aree mains/trasformatore, operare solo con tecnico qualificato e isolamento appropriato.

## Cose da non assumere
- Non assumere che le modifiche ECR738/ECR739 siano presenti sullo strumento reale.
- Non assumere valori OCR se l'immagine non li conferma chiaramente.
- Non sostituire componenti per somiglianza del sintomo senza prova elettrica o ispezione fisica.

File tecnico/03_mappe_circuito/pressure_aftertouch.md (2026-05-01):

# Pressure / Aftertouch

## Ruolo nel Prophet VS
Mappa di lavoro per diagnosi e lettura incrociata. Le affermazioni sotto derivano dalle pagine/sorgenti linkate.

## Pagine/sorgenti
- [pvs_service pagina 4](../05_pagine_rilevanti/note/pvs_service/page_004.md)
- [pvs_service pagina 6](../05_pagine_rilevanti/note/pvs_service/page_006.md)
- [sci_prophet_vs_ecr738 pagina 2](../05_pagine_rilevanti/note/sci_prophet_vs_ecr738/page_002.md)
- [sci_prophet_vs_ecr739 pagina 4](../05_pagine_rilevanti/note/sci_prophet_vs_ecr739/page_004.md)

## Componenti importanti
U310, U459, R321, R307, R308, R309, R320, R304, R458, pressure sensor connector, TP301/TP302.

## Rail importanti
+12V, -12V, +5VD, AGND/DGND; ECR738 page 2 also shows local +12V biasing near pressure sensor.

## Flusso del segnale, per quanto leggibile
Pressure sensor -> op amp/scale network -> SENSOR/PRESSURE net -> digital/analog interconnect. Confermato sulle pagine sopra; dettagli di pin/value vanno verificati sulle immagini.

## Cosa puo andare storto
- Op amp o IC guasto, condensatore in perdita, saldatura crepata, via/pista danneggiata, connettore ossidato.
- Rail basso/con ripple o ground analogico/digitale disturbato.
- Valori ECR errati, jumper/tagli non documentati o riparazioni precedenti malfatte.

## Come potrebbe collegarsi ai sintomi
Aftertouch non lineare, pressione sempre alta/bassa, CV contaminato, reset/rumore se ground/rail condivisi hanno problemi.

## Cose da misurare in sicurezza
- Verificare concettualmente i rail indicati nelle pagine sorgente prima di inseguire segnali piccoli.
- Confrontare ground analogico/digitale solo come da schema e senza creare corti accidentali.
- Osservare uscite/ingressi etichettati nelle pagine linkate con strumenti adeguati e massa corretta.
- Nelle aree mains/trasformatore, operare solo con tecnico qualificato e isolamento appropriato.

## Cose da non assumere
- Non assumere che le modifiche ECR738/ECR739 siano presenti sullo strumento reale.
- Non assumere valori OCR se l'immagine non li conferma chiaramente.
- Non sostituire componenti per somiglianza del sintomo senza prova elettrica o ispezione fisica.

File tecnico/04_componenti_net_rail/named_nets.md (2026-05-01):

# Net utili

| Net | Area | Perche interessa | Sorgenti |
| --- | --- | --- | --- |
| `VCA` | S&H -> VCA | Se non raggiunge il livello di chiusura, puo' lasciare passare audio a volume zero | pvs_service pagine 6/9 |
| `VCF` | S&H -> filtro | CV errata puo' alterare timbro o creare comportamento patch/modulazione strano | pvs_service pagine 6/9 |
| `PAN` | S&H -> pan/audio | Drift o errore puo' cambiare bilanciamento left/right | pvs_service pagine 6/9 |
| `LEV` | S&H/output | Livelli/final CV; utile per bleed o output anomalo | pvs_service pagine 6/12 |
| `LEFT/RIGHT` | Audio path | Percorso canali; utile per capire se il difetto e' mono, stereo o output-specifico | pvs_service pagine 9/11/12 |
| `CHORUS`, `LEFT CHORUS`, `RIGHT CHORUS` | Chorus/output | Se il difetto cambia con chorus/output, partire da qui | pvs_service pagine 6/11/12 |
| `PRESSURE/SENSOR` | Pressure/aftertouch | CV pressure fuori scala puo' contaminare controlli o modulazioni | pvs_service pagine 4/6, ECR738 pagina 2, ECR739 pagina 4 |
| `INH` | S&H timing | Timing errato puo' creare droop/hold error o CV non stabili | pvs_service pagina 6, 5530 pagina 4 |
| `DAC` | S&H input | DAC/riferimento rumoroso o errato si riflette su molte CV | pvs_service pagina 6, 5530 pagine 1/3 |
| `RESET` | Logica/reset | Rail/reset instabili possono alterare inizializzazione e controllo CV | pvs_service pagina 4, ECR739 pagina 4 |

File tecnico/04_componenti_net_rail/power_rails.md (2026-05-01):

# Rail utili

| Rail | Dove compare | Perche interessa | Cosa controllare |
| --- | --- | --- | --- |
| `+5VD` | pvs_service pagine 4/6, ECR739 pagina 4 | Rail digitale; legato a `U301 7805`, reset/logica e refresh CV | Tensione, ripple, carico a valle, temperatura `U301` |
| `+12V` | pvs_service pagine 4/6/12, ECR739 pagina 4 | Rail analogico/op amp e rail del regolatore `U302 7812` | Tensione, ripple, Vin/Vout `U302`, carico audio/CV |
| `-12V` | pvs_service pagine 4/6/12, ECR739 pagina 4 | Rail analogico/op amp e rail del regolatore `U303 7912` | Tensione, ripple, Vin/Vout `U303`, carico audio/CV |
| `+8V` | pvs_service pagina 6 | Rail locale S&H/CV/output; generato vicino a `U450 78M08` | Stabilita', ripple, effetto su CEM5530 e chorus/final CV |
| `+5.6V` | pvs_service pagina 6 | Rail/riferimento locale analogico S&H | Stabilita' e rumore sulle CV |
| `-5V` | pvs_service pagina 6 | Rail locale analogico vicino a `U401 7905` | Stabilita', ripple e carico a valle |
| `AGND/DGND` | pvs_service pagine 4/6, ECR739 pagina 4 | Ground analogico/digitale; ground difettoso puo' causare bleed/rumore | Continuita' secondo schema, senza creare ponti accidentali |

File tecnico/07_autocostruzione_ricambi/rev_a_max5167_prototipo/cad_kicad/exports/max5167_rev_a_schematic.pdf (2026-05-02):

1 | 2 | 3 | 4 | 5 | 6 | 7 | 8
1 | 2 | 3 | 4 | 5 | 6 | 7 | 8

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
F Date: 2026-05-02
KiCad E.D.A. 10.0.1 | Id: 1/1
Size: A3 | Rev: A PROTOTYPE | - NOT VALIDATED

Title: MAX5167 Rev A CEM5530 Replacement Prototype

File: max5167_rev_a_prototype.kicad_sch

Sheet: /

Prophet VS technician package

This is a KiCad starting point, not production CAD.

Do not generate Gerbers before schematic, footprint, ERC, DRC and bench-test review.
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

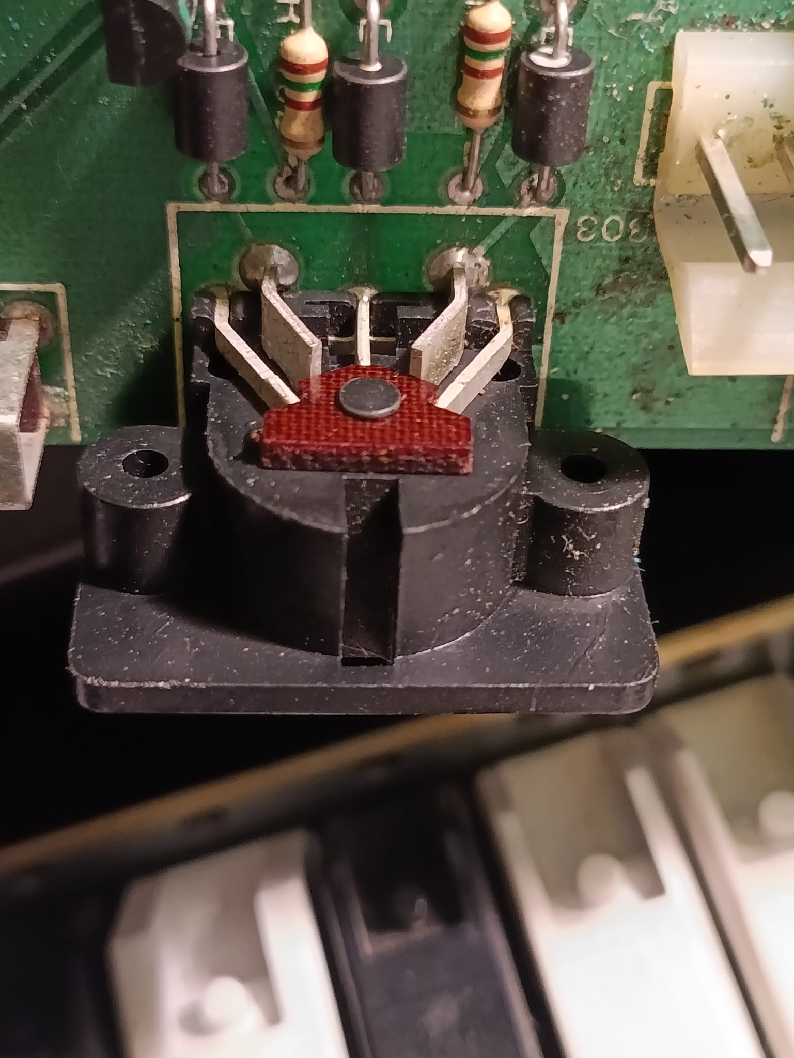
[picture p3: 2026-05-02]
c4852b98-8b9b-45b2-87f7-ef65d1ee70a3.JPG

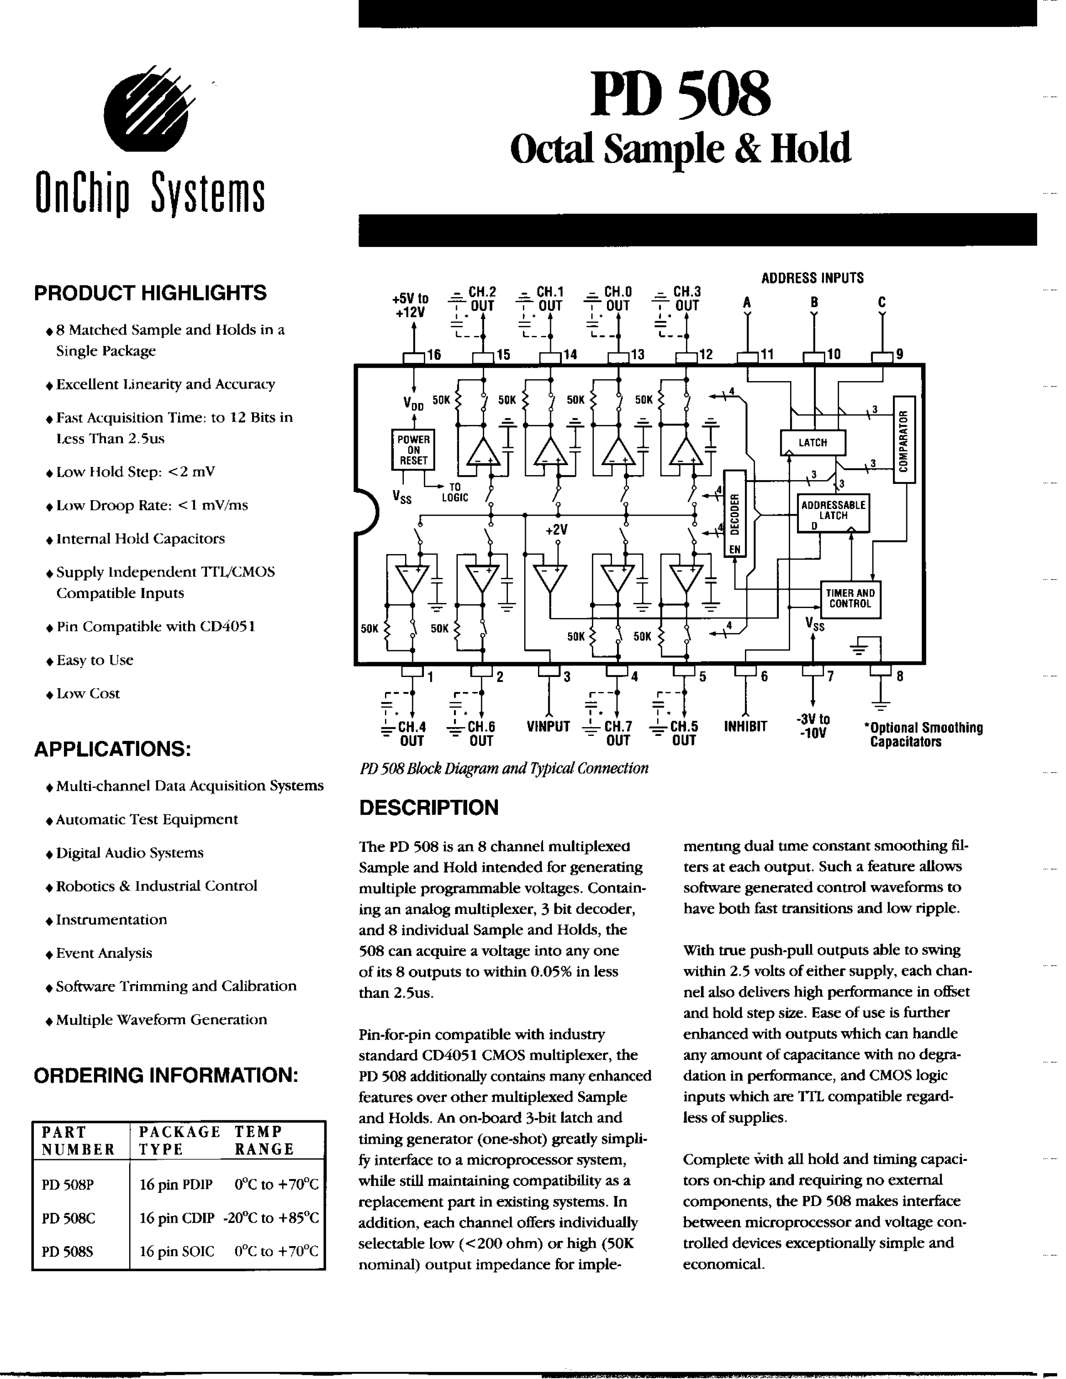
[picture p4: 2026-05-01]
doc/prophet_vs_service_context/page_images/5508/page_001.png

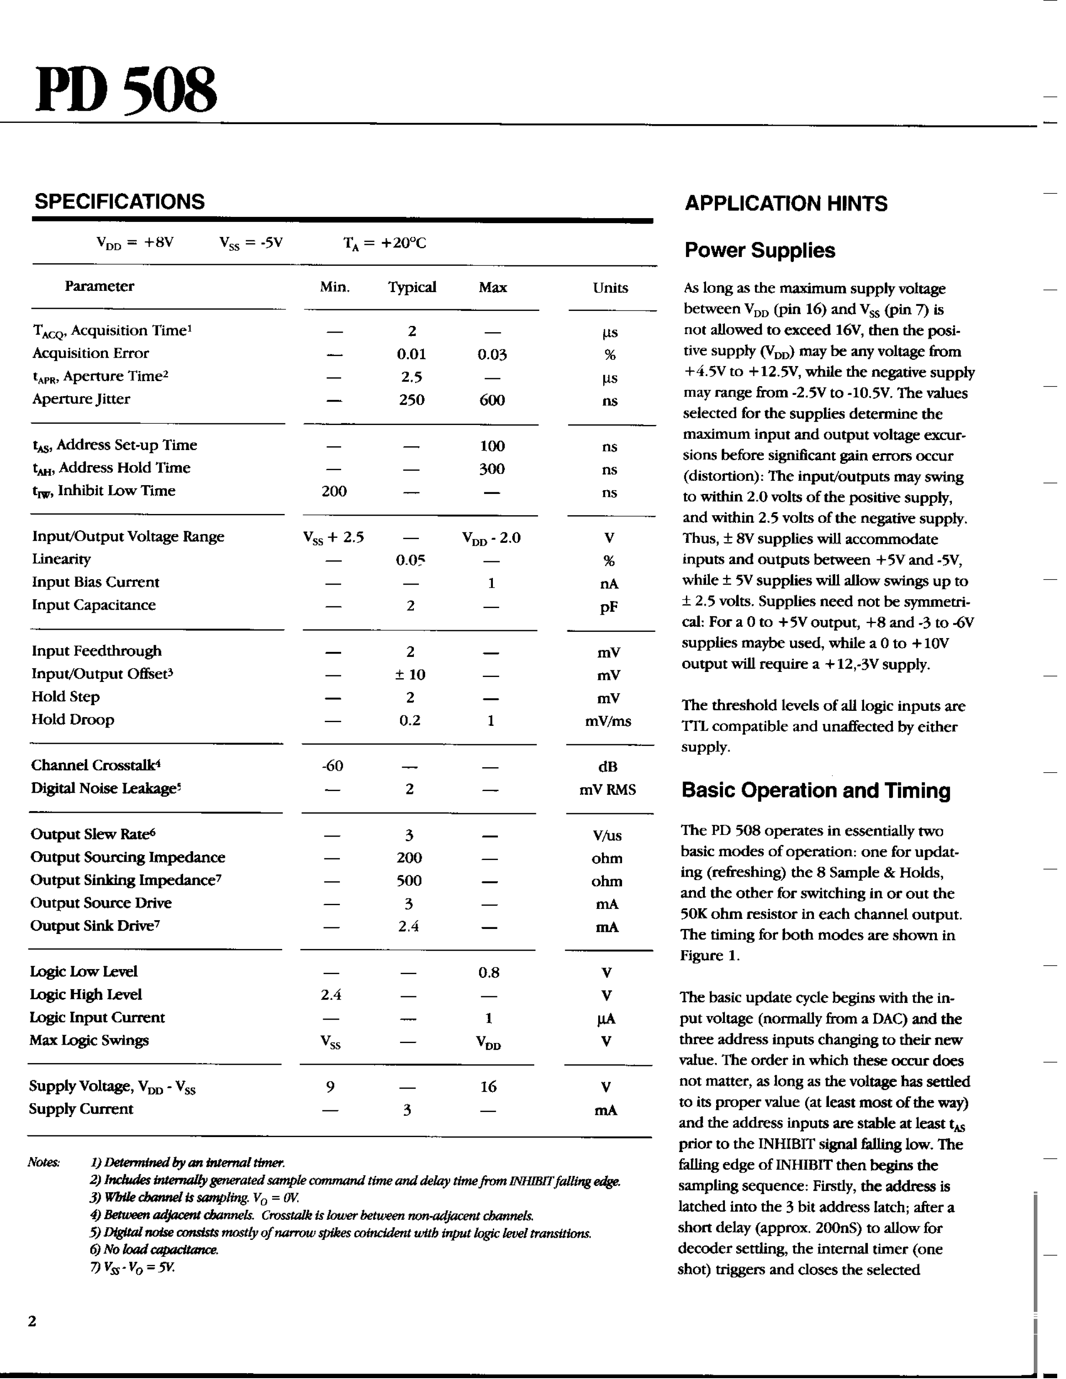
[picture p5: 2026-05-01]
doc/prophet_vs_service_context/page_images/5508/page_002.png

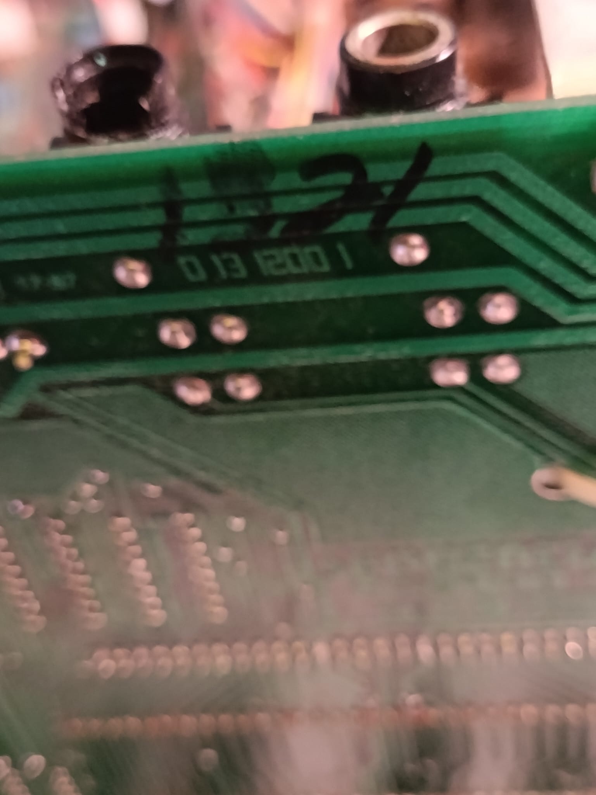
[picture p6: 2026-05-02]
9f6742c6-3080-4c11-a903-6115adde6a9a.JPG

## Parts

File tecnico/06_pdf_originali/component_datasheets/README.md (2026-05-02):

# Datasheet componenti per ricambi

Questa sottocartella serve come promemoria per datasheet esterni utili alla ricostruzione di moduli `CEM5530`.

PDF consigliati da scaricare manualmente se il tecnico vuole lavorare offline:

- Maxim/Analog Devices `MAX5167-MAX5167N`: `https://www.analog.com/media/en/technical-documentation/data-sheets/MAX5167-MAX5167N.pdf`
- Analog Devices `SSM2300` obsolete datasheet: `https://www.analog.com/media/en/technical-documentation/obsolete-data-sheets/ssm2300.pdf`

Nota: il download automatico con `curl` non e' riuscito in questa sessione, quindi qui restano i link ufficiali. I PDF gia' inclusi nella cartella superiore sono invece:

- `../5530.pdf`
- `../5508.pdf`
- `../pvs_service.pdf`
- `../sci_prophet_vs_ecr738.pdf`
- `../sci_prophet_vs_ecr739.pdf`

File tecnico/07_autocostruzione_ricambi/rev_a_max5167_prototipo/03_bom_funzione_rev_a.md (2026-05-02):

# BOM funzionale Rev A

## Stato

Questa non e' una BOM di acquisto definitiva. E' una BOM funzionale per trasformare lo schema testuale in CAD.

Il tecnico deve scegliere part number reali in base a:

- disponibilita' autentica;
- package e altezza;
- rumore;
- startup/enable;
- corrente e temperatura;
- compatibilita' con layout piccolo.

## IC principali

| Ref | Funzione | Specifica minima | Popolamento |
| --- | --- | --- | --- |
| `U1` | Sample & hold 32 canali | `MAX5167L/M/N`, 48-TQFP | obbligatorio |
| `U2` | Boost `+8V_FILT` -> `+11V_PRE` | regolabile, soft-start/enable, low-noise | obbligatorio salvo soluzione alternativa validata |
| `U3` | Regolazione/filtraggio `+11V_PRE` -> `+10V_A` | LDO low-noise o regolatore equivalente | consigliato |
| `U4` | LDO `+8V_FILT` -> `+5V_L` | low-noise, stabile con cap scelti | obbligatorio |
| `U5` | Stretching opzionale `S/H` | logica/monostabile compatibile 5V | DNP Rev A iniziale |

## Passivi e protezioni

| Ref | Valore iniziale | Funzione | Popolamento |
| --- | --- | --- | --- |
| `RIN1` | `0R`, opzione `100R` | serie su `VIN` | obbligatorio |
| `RN_LOGIC` | `0R` o `47R` | serie su `A0..A4`, `INH` | obbligatorio |
| `RSEL` | `10k` | pull-up `SELECT` a `+5V_L` | obbligatorio |
| `RCFG` | `10k` | pull-down `CONFIG` a `DGND_LOCAL` | obbligatorio |
| `R_OUT0..R_OUT29` | `0R`, opzioni `100R/470R` | serie uscite CV | obbligatorio |
| `R_OUT30/R_OUT31` | DNP | solo test pad, non socket | DNP |
| `FB1` | ferrite o `0R` | filtro `+8V_IN` | obbligatorio |
| `FB2` | ferrite o `0R` | filtro `-5V_IN` | obbligatorio |
| `F1` | `0R` o polyfuse piccolo | isolamento/debug su `+8V_IN` | consigliato |
| `D_RAIL*` | DNP | clamp/TVS rail locali | DNP finche non scelti |

## Decoupling minimo

| Ref | Valore iniziale | Posizione |
| --- | --- | --- |
| `C1` | `10uF` | `+8V_FILT` verso `GND_IN` |
| `C2` | `100nF` | `+8V_FILT` vicino ingresso |
| `C3` | `10uF` | `+11V_PRE` uscita boost |
| `C4` | `100nF` | `+11V_PRE` vicino U3 |
| `C5` | `10uF` | `+10V_A` verso `AGND_LOCAL` |
| `C6` | `100nF` | vicino U1 pin 30 |
| `C7` | `4.7uF/10uF` | `+5V_L` verso `DGND_LOCAL` |
| `C8` | `100nF` | vicino U1 pin 7 |
| `C9` | `10uF` | `-5V_A` verso `AGND_LOCAL` |
| `C10` | `100nF` | vicino U1 pin 9 |
| `C_AGND` | DNP | eventuale filtro locale massa/rail |
| `C_OUT*` | DNP | uscite CV verso massa, solo se test lo richiede |

## Connettori e meccanica

| Ref | Parte | Nota |
| --- | --- | --- |
| `J1` | header maschio 40 pin compatibile socket `CEM5530` | pin torniti consigliati |
| `TP_*` | test pad | rail, address, `VIN`, `INH`, CV campione |
| label PCB | serigrafia | `MAX5167 Rev A PROTOTYPE - NOT VALIDATED` |

## Note di scelta componenti

- `MAX5167L`: preferenza iniziale se autentico, per uscita a bassa impedenza.
- `MAX5167M/N`: valutabili se il tecnico vuole piu resistenza d'uscita interna o se il carico capacitivo lo richiede.
- U2 deve essere scelto guardando ripple e startup, non solo corrente massima.
- U3 deve evitare overshoot su `+10V_A`.
- U4 deve dare `+5V_L` pulito e stabile prima della logica.
- I componenti DNP non sono decorativi: servono a correggere Rev A senza rifare subito il PCB.

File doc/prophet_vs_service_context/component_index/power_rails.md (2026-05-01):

# Power rails

| Riferimento / Net | Visto in pagina sorgente | Funzione / contesto | Note / incertezza |
| --- | --- | --- | --- |
| +5VD | pvs_service pagine 3-4, 6 | Logica digitale | Rail digitale, possibile causa di reset o refresh CV se basso/ripple. |
| +12V / -12V | pvs_service pagine 4, 6, 12 | Rail analogici/op amp e alimentazione | Rilevanti per headroom op amp e S&H; misurare con cautela. |
| +8V / +5.6V / -5V | pvs_service pagina 6 | Rail locali main analog/S&H | Visibili vicino a regolatori 78M08/78M05/7905. |
| AGND / DGND | pvs_service pagine 4, 6 | Ground analogico/digitale | Contaminazione o connessioni difettose possono causare bleed/rumore. |
| +12V | pvs_service pagina 4; pvs_service pagina 6; pvs_service pagina 9; pvs_service pagina 12; sci_prophet_vs_ecr738 pagina 2; sci_prophet_vs_ecr739 pagina 4 | OCR/immagine: contesto da verificare nella page note | Estratto automaticamente; possibili falsi OCR. |
| +5.6V | pvs_service pagina 6 | OCR/immagine: contesto da verificare nella page note | Estratto automaticamente; possibili falsi OCR. |
| +5V | 5508 pagina 1; 5508 pagina 2; 5530 pagina 1; 5530 pagina 3; pvs_service pagina 1; pvs_service pagina 2; pvs_service pagina 3; pvs_service pagina 4; ... 13 occorrenze | OCR/immagine: contesto da verificare nella page note | Estratto automaticamente; possibili falsi OCR. |
| +8V | 5508 pagina 2; 5530 pagina 3; pvs_service pagina 1; pvs_service pagina 6; pvs_service pagina 11; pvs_service pagina 12; sci_prophet_vs_ecr738 pagina 2 | OCR/immagine: contesto da verificare nella page note | Estratto automaticamente; possibili falsi OCR. |
| -12V | 5530 pagina 3; pvs_service pagina 4; pvs_service pagina 6; pvs_service pagina 12; sci_prophet_vs_ecr738 pagina 2; sci_prophet_vs_ecr739 pagina 4 | OCR/immagine: contesto da verificare nella page note | Estratto automaticamente; possibili falsi OCR. |
| -5V | 5508 pagina 2; 5508 pagina 4; 5530 pagina 3; pvs_service pagina 6 | OCR/immagine: contesto da verificare nella page note | Estratto automaticamente; possibili falsi OCR. |
| AGND | pvs_service pagina 4; pvs_service pagina 6; sci_prophet_vs_ecr739 pagina 4 | OCR/immagine: contesto da verificare nella page note | Estratto automaticamente; possibili falsi OCR. |
| DGND | pvs_service pagina 4; pvs_service pagina 6; sci_prophet_vs_ecr739 pagina 4 | OCR/immagine: contesto da verificare nella page note | Estratto automaticamente; possibili falsi OCR. |
| GND | pvs_service pagina 1; pvs_service pagina 2; pvs_service pagina 3; pvs_service pagina 4; pvs_service pagina 6; pvs_service pagina 7; pvs_service pagina 9; pvs_service pagina 10; ... 10 occorrenze | OCR/immagine: contesto da verificare nella page note | Estratto automaticamente; possibili falsi OCR. |
| VDD | 5530 pagina 3 | OCR/immagine: contesto da verificare nella page note | Estratto automaticamente; possibili falsi OCR. |
| VREF | pvs_service pagina 6 | OCR/immagine: contesto da verificare nella page note | Estratto automaticamente; possibili falsi OCR. |
| VSS | 5508 pagina 1; 5508 pagina 2; 5508 pagina 4; 5530 pagina 3; pvs_service pagina 6; pvs_service pagina 7; pvs_service pagina 8; pvs_service pagina 11; ... 10 occorrenze | OCR/immagine: contesto da verificare nella page note | Estratto automaticamente; possibili falsi OCR. |

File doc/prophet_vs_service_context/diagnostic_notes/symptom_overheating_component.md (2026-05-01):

# Sintomo: Componente che scalda

## Descrizione sintomo
Un regolatore, op amp, IC logico o resistenza scalda in modo anomalo.

## Aree circuito piu rilevanti
Power supply, regolatori locali, analog board, riparazioni fisiche.

## Pagine sorgente da ispezionare
- [pvs_service pagina 4](../page_notes/pvs_service/page_004.md)
- [pvs_service pagina 6](../page_notes/pvs_service/page_006.md)
- [sci_prophet_vs_ecr739 pagina 4](../page_notes/sci_prophet_vs_ecr739/page_004.md)

## Possibili cause ordinate dalla piu probabile alla meno probabile
1. Corto a valle
2. Condensatore in perdita
3. Regolatore sovraccarico
4. IC guasto
5. Jumper/pista errata dopo riparazione

## Quale evidenza supporterebbe ogni causa
- Il sintomo cambia quando si osservano/isolano concettualmente le aree circuito indicate nelle pagine sorgente.
- Le misure mostrano rail, CV o audio fuori range rispetto alle etichette presenti nello schema.
- Ispezione visiva trova saldature, jumper, piste o componenti nella stessa zona delle pagine linkate.

## Quale evidenza la escluderebbe
- Rail e ground stabili, nessun ripple anomalo, e segnale/CV corretto prima e dopo il blocco sospetto.
- Il difetto resta invariato dopo esclusione documentata del blocco indicato.
- Continuita e componenti fisici corrispondono agli schemi/ECR.

## Misure/controlli da eseguire
- Prima controllare rail principali e locali indicati nelle page note.
- Poi osservare segnali etichettati nella pagina sorgente con massa corretta e strumenti adatti.
- Confrontare comportamento statico e dinamico: valore DC, ripple, risposta a patch/controlli, eventuale modulazione residua.

## Aree scheda/componenti da ispezionare visivamente
- Connettori citati nelle page note.
- Zone ECR e riparazioni precedenti, soprattutto tagli piste/jumper.
- Regolatori, op amp, CEM5530/S&H, condensatori tantalio/elettrolitici e jack/output.

## Rischi / cautele
- Non operare su mains/trasformatore senza tecnico qualificato.
- Evitare corti con puntali; vecchie PCB possono sollevare pad con calore o forza.
- Non sostituire parti rare senza prova; alcuni IC possono essere difficili da reperire.

## Domande per un tecnico
- Il difetto cambia tra uscita left/right, cuffie/line out o chorus on/off?
- Il bleed segue VCA/VCF/PAN/LEV o resta nel percorso audio finale?
- I rail locali e reference sono stabili a freddo/caldo?
- La board mostra ECR738/ECR739 applicati, parziali o assenti?

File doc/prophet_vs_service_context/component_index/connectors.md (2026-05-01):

# Connettori e test point

| Riferimento / Net | Visto in pagina sorgente | Funzione / contesto | Note / incertezza |
| --- | --- | --- | --- |
| P402/P403 | pvs_service pagina 6 | Interconnessione S&H/sensor/CV | Mostra SENSOR, DGND e vari rail/CV; usare per tracciamento non invasivo. |
| P302/P305 | pvs_service pagina 4; pvs_service pagina 6 | Connettori digital/analog board | Visibili in circuiti pressure/power e S&H. |
| J401/J306 | pvs_service pagina 6; sci_prophet_vs_ecr739 pagina 4 | Pressure sensor connector, lettura incerta per numerazione | OCR/immagine non sempre concordano; verificare visivamente. |
| J302 | pvs_service pagina 5 | OCR/immagine: contesto da verificare nella page note | Estratto automaticamente; possibili falsi OCR. |
| J304 | pvs_service pagina 5 | OCR/immagine: contesto da verificare nella page note | Estratto automaticamente; possibili falsi OCR. |
| J306 | pvs_service pagina 5 | OCR/immagine: contesto da verificare nella page note | Estratto automaticamente; possibili falsi OCR. |
| J601 | pvs_service pagina 2 | OCR/immagine: contesto da verificare nella page note | Estratto automaticamente; possibili falsi OCR. |
| P0900 | pvs_service pagina 3 | OCR/immagine: contesto da verificare nella page note | Estratto automaticamente; possibili falsi OCR. |
| P201 | pvs_service pagina 2 | OCR/immagine: contesto da verificare nella page note | Estratto automaticamente; possibili falsi OCR. |
| P202 | pvs_service pagina 3; pvs_service pagina 4; sci_prophet_vs_ecr739 pagina 4 | OCR/immagine: contesto da verificare nella page note | Estratto automaticamente; possibili falsi OCR. |
| P2305 | pvs_service pagina 3 | OCR/immagine: contesto da verificare nella page note | Estratto automaticamente; possibili falsi OCR. |
| P2400 | pvs_service pagina 5 | OCR/immagine: contesto da verificare nella page note | Estratto automaticamente; possibili falsi OCR. |
| P3002 | sci_prophet_vs_ecr739 pagina 4 | OCR/immagine: contesto da verificare nella page note | Estratto automaticamente; possibili falsi OCR. |
| P302 | pvs_service pagina 3; pvs_service pagina 5 | OCR/immagine: contesto da verificare nella page note | Estratto automaticamente; possibili falsi OCR. |
| P303 | pvs_service pagina 4; sci_prophet_vs_ecr739 pagina 4 | OCR/immagine: contesto da verificare nella page note | Estratto automaticamente; possibili falsi OCR. |
| P3035 | pvs_service pagina 4 | OCR/immagine: contesto da verificare nella page note | Estratto automaticamente; possibili falsi OCR. |
| P305 | pvs_service pagina 3 | OCR/immagine: contesto da verificare nella page note | Estratto automaticamente; possibili falsi OCR. |
| P308 | sci_prophet_vs_ecr739 pagina 4 | OCR/immagine: contesto da verificare nella page note | Estratto automaticamente; possibili falsi OCR. |
| P3201 | pvs_service pagina 4 | OCR/immagine: contesto da verificare nella page note | Estratto automaticamente; possibili falsi OCR. |
| P3205 | pvs_service pagina 3 | OCR/immagine: contesto da verificare nella page note | Estratto automaticamente; possibili falsi OCR. |
| P3206 | pvs_service pagina 5 | OCR/immagine: contesto da verificare nella page note | Estratto automaticamente; possibili falsi OCR. |
| P3302 | pvs_service pagina 4 | OCR/immagine: contesto da verificare nella page note | Estratto automaticamente; possibili falsi OCR. |
| P3908 | pvs_service pagina 11 | OCR/immagine: contesto da verificare nella page note | Estratto automaticamente; possibili falsi OCR. |
| P4002 | pvs_service pagina 6 | OCR/immagine: contesto da verificare nella page note | Estratto automaticamente; possibili falsi OCR. |
| P402 | pvs_service pagina 6 | OCR/immagine: contesto da verificare nella page note | Estratto automaticamente; possibili falsi OCR. |
| P403 | pvs_service pagina 6 | OCR/immagine: contesto da verificare nella page note | Estratto automaticamente; possibili falsi OCR. |
| P4035 | pvs_service pagina 6 | OCR/immagine: contesto da verificare nella page note | Estratto automaticamente; possibili falsi OCR. |
| P4093 | pvs_service pagina 9 | OCR/immagine: contesto da verificare nella page note | Estratto automaticamente; possibili falsi OCR. |
| P602 | pvs_service pagina 2 | OCR/immagine: contesto da verificare nella page note | Estratto automaticamente; possibili falsi OCR. |
| P901 | pvs_service pagina 11 | OCR/immagine: contesto da verificare nella page note | Estratto automaticamente; possibili falsi OCR. |
| TP301 | pvs_service pagina 4; sci_prophet_vs_ecr739 pagina 4 | OCR/immagine: contesto da verificare nella page note | Estratto automaticamente; possibili falsi OCR. |
| TP302 | pvs_service pagina 4; pvs_service pagina 5; sci_prophet_vs_ecr739 pagina 4 | OCR/immagine: contesto da verificare nella page note | Estratto automaticamente; possibili falsi OCR. |

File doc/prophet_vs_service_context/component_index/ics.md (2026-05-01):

# ICs

| Riferimento / Net | Visto in pagina sorgente | Funzione / contesto | Note / incertezza |
| --- | --- | --- | --- |
| CEM5530 | pvs_service pagina 6; 5530.pdf pagine 1-4 | 30-channel sample & hold per generazione CV | Molto rilevante per droop/bleed CV; verificare U449/U425 sullo schema. |
| PD508 | 5508.pdf pagine 1-4 | Octal sample & hold datasheet | Usare per concetti di hold step, droop e timing; non necessariamente montato nel Prophet VS esaminato. |
| U449 | pvs_service pagina 6 | CEM5530 con uscite VCA/VCF/PAN e chorus/final CV | Visibile nello schema; parte esatta indicata come 5530. |
| U425 | pvs_service pagina 6 | CEM5530 con uscite LEV | Visibile nello schema; verificare sulla board. |
| U459 | pvs_service pagina 6; sci_prophet_vs_ecr738 pagina 2 | Op amp pressure sensor | ECR738 mostra R458 vicino a U459; verificare valori fisici. |
| U310 | pvs_service pagina 4; sci_prophet_vs_ecr739 pagina 4 | Op amp pressure circuit / keyboard board | Visibile nello schema pressure ECR739. |
| U301/U302/U303 | pvs_service pagina 4; sci_prophet_vs_ecr739 pagina 4 | Regolatori 7805/7812/7912 | Sezione alimentazione; attenzione a mains/trasformatore. |
| 5530 | 5530 pagina 1; pvs_service pagina 6; sci_prophet_vs_ecr738 pagina 2 | OCR/immagine: contesto da verificare nella page note | Estratto automaticamente; possibili falsi OCR. |
| 68000 | pvs_service pagina 3 | OCR/immagine: contesto da verificare nella page note | Estratto automaticamente; possibili falsi OCR. |
| 68B50 | pvs_service pagina 3 | OCR/immagine: contesto da verificare nella page note | Estratto automaticamente; possibili falsi OCR. |
| 7805 | pvs_service pagina 4; sci_prophet_vs_ecr739 pagina 4 | OCR/immagine: contesto da verificare nella page note | Estratto automaticamente; possibili falsi OCR. |
| 7812 | pvs_service pagina 4; sci_prophet_vs_ecr739 pagina 4 | OCR/immagine: contesto da verificare nella page note | Estratto automaticamente; possibili falsi OCR. |
| 78M05 | pvs_service pagina 6 | OCR/immagine: contesto da verificare nella page note | Estratto automaticamente; possibili falsi OCR. |
| 78M08 | pvs_service pagina 6 | OCR/immagine: contesto da verificare nella page note | Estratto automaticamente; possibili falsi OCR. |
| 7905 | pvs_service pagina 6 | OCR/immagine: contesto da verificare nella page note | Estratto automaticamente; possibili falsi OCR. |
| 7912 | pvs_service pagina 4; sci_prophet_vs_ecr739 pagina 4 | OCR/immagine: contesto da verificare nella page note | Estratto automaticamente; possibili falsi OCR. |
| ADC0808 | pvs_service pagina 1 | OCR/immagine: contesto da verificare nella page note | Estratto automaticamente; possibili falsi OCR. |
| HC132 | pvs_service pagina 4; sci_prophet_vs_ecr739 pagina 4 | OCR/immagine: contesto da verificare nella page note | Estratto automaticamente; possibili falsi OCR. |
| HC174 | pvs_service pagina 4; sci_prophet_vs_ecr739 pagina 4 | OCR/immagine: contesto da verificare nella page note | Estratto automaticamente; possibili falsi OCR. |
| HC244 | pvs_service pagina 1; pvs_service pagina 7 | OCR/immagine: contesto da verificare nella page note | Estratto automaticamente; possibili falsi OCR. |
| HC273 | pvs_service pagina 8 | OCR/immagine: contesto da verificare nella page note | Estratto automaticamente; possibili falsi OCR. |
| HC32 | pvs_service pagina 3 | OCR/immagine: contesto da verificare nella page note | Estratto automaticamente; possibili falsi OCR. |
| LS221 | pvs_service pagina 6 | OCR/immagine: contesto da verificare nella page note | Estratto automaticamente; possibili falsi OCR. |
| TL082 | pvs_service pagina 12 | OCR/immagine: contesto da verificare nella page note | Estratto automaticamente; possibili falsi OCR. |
| U204 | sci_prophet_vs_ecr739 pagina 4 | OCR/immagine: contesto da verificare nella page note | Estratto automaticamente; possibili falsi OCR. |
| U223 | pvs_service pagina 3 | OCR/immagine: contesto da verificare nella page note | Estratto automaticamente; possibili falsi OCR. |
| U301 | pvs_service pagina 4; sci_prophet_vs_ecr739 pagina 4 | OCR/immagine: contesto da verificare nella page note | Estratto automaticamente; possibili falsi OCR. |
| U302 | pvs_service pagina 4; sci_prophet_vs_ecr739 pagina 4 | OCR/immagine: contesto da verificare nella page note | Estratto automaticamente; possibili falsi OCR. |
| U303 | pvs_service pagina 4; pvs_service pagina 5; sci_prophet_vs_ecr739 pagina 4 | OCR/immagine: contesto da verificare nella page note | Estratto automaticamente; possibili falsi OCR. |
| U304 | pvs_service pagina 4; sci_prophet_vs_ecr739 pagina 4 | OCR/immagine: contesto da verificare nella page note | Estratto automaticamente; possibili falsi OCR. |
| U305 | pvs_service pagina 4; sci_prophet_vs_ecr739 pagina 4 | OCR/immagine: contesto da verificare nella page note | Estratto automaticamente; possibili falsi OCR. |
| U307 | pvs_service pagina 4; pvs_service pagina 5 | OCR/immagine: contesto da verificare nella page note | Estratto automaticamente; possibili falsi OCR. |
| U308 | pvs_service pagina 5 | OCR/immagine: contesto da verificare nella page note | Estratto automaticamente; possibili falsi OCR. |
| U309 | pvs_service pagina 5 | OCR/immagine: contesto da verificare nella page note | Estratto automaticamente; possibili falsi OCR. |
| U314 | pvs_service pagina 5 | OCR/immagine: contesto da verificare nella page note | Estratto automaticamente; possibili falsi OCR. |
| U319 | pvs_service pagina 5 | OCR/immagine: contesto da verificare nella page note | Estratto automaticamente; possibili falsi OCR. |
| U320 | pvs_service pagina 5; sci_prophet_vs_ecr739 pagina 4 | OCR/immagine: contesto da verificare nella page note | Estratto automaticamente; possibili falsi OCR. |
| U323 | pvs_service pagina 3 | OCR/immagine: contesto da verificare nella page note | Estratto automaticamente; possibili falsi OCR. |
| U325 | pvs_service pagina 3 | OCR/immagine: contesto da verificare nella page note | Estratto automaticamente; possibili falsi OCR. |
| U326 | pvs_service pagina 3 | OCR/immagine: contesto da verificare nella page note | Estratto automaticamente; possibili falsi OCR. |
| U327 | pvs_service pagina 3 | OCR/immagine: contesto da verificare nella page note | Estratto automaticamente; possibili falsi OCR. |
| U329 | pvs_service pagina 5 | OCR/immagine: contesto da verificare nella page note | Estratto automaticamente; possibili falsi OCR. |
| U330 | pvs_service pagina 3 | OCR/immagine: contesto da verificare nella page note | Estratto automaticamente; possibili falsi OCR. |
| U332 | pvs_service pagina 3; pvs_service pagina 5 | OCR/immagine: contesto da verificare nella page note | Estratto automaticamente; possibili falsi OCR. |
| U333 | pvs_service pagina 5 | OCR/immagine: contesto da verificare nella page note | Estratto automaticamente; possibili falsi OCR. |
| U334 | pvs_service pagina 5 | OCR/immagine: contesto da verificare nella page note | Estratto automaticamente; possibili falsi OCR. |
| U335 | pvs_service pagina 5 | OCR/immagine: contesto da verificare nella page note | Estratto automaticamente; possibili falsi OCR. |
| U401 | pvs_service pagina 6 | OCR/immagine: contesto da verificare nella page note | Estratto automaticamente; possibili falsi OCR. |
| U402 | pvs_service pagina 6 | OCR/immagine: contesto da verificare nella page note | Estratto automaticamente; possibili falsi OCR. |
| U406 | pvs_service pagina 10 | OCR/immagine: contesto da verificare nella page note | Estratto automaticamente; possibili falsi OCR. |
| U409 | pvs_service pagina 7 | OCR/immagine: contesto da verificare nella page note | Estratto automaticamente; possibili falsi OCR. |
| U424 | pvs_service pagina 8; pvs_service pagina 10 | OCR/immagine: contesto da verificare nella page note | Estratto automaticamente; possibili falsi OCR. |
| U440 | pvs_service pagina 10; sci_prophet_vs_ecr738 pagina 2 | OCR/immagine: contesto da verificare nella page note | Estratto automaticamente; possibili falsi OCR. |
| U450 | pvs_service pagina 6 | OCR/immagine: contesto da verificare nella page note | Estratto automaticamente; possibili falsi OCR. |
| U451 | pvs_service pagina 6 | OCR/immagine: contesto da verificare nella page note | Estratto automaticamente; possibili falsi OCR. |
| U453 | pvs_service pagina 6 | OCR/immagine: contesto da verificare nella page note | Estratto automaticamente; possibili falsi OCR. |
| U454 | pvs_service pagina 6 | OCR/immagine: contesto da verificare nella page note | Estratto automaticamente; possibili falsi OCR. |
| U455 | pvs_service pagina 9 | OCR/immagine: contesto da verificare nella page note | Estratto automaticamente; possibili falsi OCR. |
| U456 | pvs_service pagina 9 | OCR/immagine: contesto da verificare nella page note | Estratto automaticamente; possibili falsi OCR. |
| U457 | pvs_service pagina 9 | OCR/immagine: contesto da verificare nella page note | Estratto automaticamente; possibili falsi OCR. |
| U458 | pvs_service pagina 9 | OCR/immagine: contesto da verificare nella page note | Estratto automaticamente; possibili falsi OCR. |
| U463 | pvs_service pagina 10 | OCR/immagine: contesto da verificare nella page note | Estratto automaticamente; possibili falsi OCR. |
| U465 | pvs_service pagina 8 | OCR/immagine: contesto da verificare nella page note | Estratto automaticamente; possibili falsi OCR. |
| U630 | pvs_service pagina 8 | OCR/immagine: contesto da verificare nella page note | Estratto automaticamente; possibili falsi OCR. |
| U903 | pvs_service pagina 11 | OCR/immagine: contesto da verificare nella page note | Estratto automaticamente; possibili falsi OCR. |
| U904 | pvs_service pagina 11 | OCR/immagine: contesto da verificare nella page note | Estratto automaticamente; possibili falsi OCR. |
| U920 | pvs_service pagina 11 | OCR/immagine: contesto da verificare nella page note | Estratto automaticamente; possibili falsi OCR. |

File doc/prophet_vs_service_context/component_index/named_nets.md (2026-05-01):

# Named nets

| Riferimento / Net | Visto in pagina sorgente | Funzione / contesto | Note / incertezza |
| --- | --- | --- | --- |
| PRESSURE / SENSOR | pvs_service pagine 4, 6; ECR738 pagina 2; ECR739 pagina 4 | Pressure/aftertouch sense path | Non assumere taratura o ECR applicata senza ispezione. |
| VCA / VCF / PAN / LEV | pvs_service pagine 6, 9 | CV verso VCA, filtri, pan e livelli | Candidati per bleed/modulation leak. |
| LEFT / RIGHT / CHORUS | pvs_service pagine 6, 9, 11, 12 | Audio/output e chorus | Rilevante per suono con volume a zero o uscita distorta. |
| RESET | pvs_service pagine 3-4; ECR739 pagina 4 | Reset digitale/logica | Problemi qui possono alterare inizializzazione e controllo CV. |
| ADDRESS BUS | pvs_service pagina 3; pvs_service pagina 7; pvs_service pagina 8; pvs_service pagina 13 | OCR/immagine: contesto da verificare nella page note | Estratto automaticamente; possibili falsi OCR. |
| CART | pvs_service pagina 1; pvs_service pagina 2; pvs_service pagina 7; pvs_service pagina 11; pvs_service pagina 13 | OCR/immagine: contesto da verificare nella page note | Estratto automaticamente; possibili falsi OCR. |
| CHORUS | pvs_service pagina 1; pvs_service pagina 2; pvs_service pagina 4; pvs_service pagina 6; pvs_service pagina 11; pvs_service pagina 12; sci_prophet_vs_ecr738 pagina 2; sci_prophet_vs_ecr739 pagina 4 | OCR/immagine: contesto da verificare nella page note | Estratto automaticamente; possibili falsi OCR. |
| DAC | 5508 pagina 2; 5508 pagina 3; 5530 pagina 1; 5530 pagina 3; pvs_service pagina 6; pvs_service pagina 13 | OCR/immagine: contesto da verificare nella page note | Estratto automaticamente; possibili falsi OCR. |
| DATA BUS | 5508 pagina 3; pvs_service pagina 13 | OCR/immagine: contesto da verificare nella page note | Estratto automaticamente; possibili falsi OCR. |
| INH | 5508 pagina 1; 5508 pagina 2; 5508 pagina 3; 5530 pagina 1; 5530 pagina 3; 5530 pagina 4; pvs_service pagina 4; pvs_service pagina 6 | OCR/immagine: contesto da verificare nella page note | Estratto automaticamente; possibili falsi OCR. |
| KEYBOARD | pvs_service pagina 4; sci_prophet_vs_ecr739 pagina 4 | OCR/immagine: contesto da verificare nella page note | Estratto automaticamente; possibili falsi OCR. |
| LEFT | pvs_service pagina 1; pvs_service pagina 2; pvs_service pagina 4; pvs_service pagina 6; pvs_service pagina 9; pvs_service pagina 11; sci_prophet_vs_ecr738 pagina 2; sci_prophet_vs_ecr739 pagina 4 | OCR/immagine: contesto da verificare nella page note | Estratto automaticamente; possibili falsi OCR. |
| LEFT CHORUS | pvs_service pagina 6; pvs_service pagina 11; sci_prophet_vs_ecr738 pagina 2 | OCR/immagine: contesto da verificare nella page note | Estratto automaticamente; possibili falsi OCR. |
| LEV | 5508 pagina 2; 5530 pagina 3; pvs_service pagina 1; pvs_service pagina 6; pvs_service pagina 7; pvs_service pagina 8; pvs_service pagina 12; sci_prophet_vs_ecr738 pagina 2; ... 9 occorrenze | OCR/immagine: contesto da verificare nella page note | Estratto automaticamente; possibili falsi OCR. |
| MIDI | pvs_service pagina 1; pvs_service pagina 3 | OCR/immagine: contesto da verificare nella page note | Estratto automaticamente; possibili falsi OCR. |
| OUTPUT EN | pvs_service pagina 6 | OCR/immagine: contesto da verificare nella page note | Estratto automaticamente; possibili falsi OCR. |
| PAN | pvs_service pagina 1; pvs_service pagina 2; pvs_service pagina 3; pvs_service pagina 6; pvs_service pagina 9; pvs_service pagina 10; sci_prophet_vs_ecr738 pagina 2; sci_prophet_vs_ecr739 pagina 4 | OCR/immagine: contesto da verificare nella page note | Estratto automaticamente; possibili falsi OCR. |
| PRESSURE | pvs_service pagina 4; pvs_service pagina 6; sci_prophet_vs_ecr738 pagina 2; sci_prophet_vs_ecr739 pagina 4 | OCR/immagine: contesto da verificare nella page note | Estratto automaticamente; possibili falsi OCR. |
| RIGHT | 5508 pagina 4; pvs_service pagina 1; pvs_service pagina 2; pvs_service pagina 6; pvs_service pagina 9; pvs_service pagina 11; pvs_service pagina 12; sci_prophet_vs_ecr738 pagina 2 | OCR/immagine: contesto da verificare nella page note | Estratto automaticamente; possibili falsi OCR. |
| RIGHT CHORUS | pvs_service pagina 6; pvs_service pagina 12; sci_prophet_vs_ecr738 pagina 2 | OCR/immagine: contesto da verificare nella page note | Estratto automaticamente; possibili falsi OCR. |
| RIGHT FINAL CV | pvs_service pagina 6 | OCR/immagine: contesto da verificare nella page note | Estratto automaticamente; possibili falsi OCR. |
| SENSOR | pvs_service pagina 6; sci_prophet_vs_ecr738 pagina 2; sci_prophet_vs_ecr739 pagina 4 | OCR/immagine: contesto da verificare nella page note | Estratto automaticamente; possibili falsi OCR. |
| SWIN | 5508 pagina 1; 5508 pagina 2; 5530 pagina 1; 5530 pagina 3; pvs_service pagina 1 | OCR/immagine: contesto da verificare nella page note | Estratto automaticamente; possibili falsi OCR. |
| VCA | pvs_service pagina 6; pvs_service pagina 9; sci_prophet_vs_ecr738 pagina 2 | OCR/immagine: contesto da verificare nella page note | Estratto automaticamente; possibili falsi OCR. |
| VCF | pvs_service pagina 6; pvs_service pagina 9; sci_prophet_vs_ecr738 pagina 2 | OCR/immagine: contesto da verificare nella page note | Estratto automaticamente; possibili falsi OCR. |

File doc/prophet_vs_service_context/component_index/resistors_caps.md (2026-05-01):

# Resistenze e capacitori

| Riferimento / Net | Visto in pagina sorgente | Funzione / contesto | Note / incertezza |
| --- | --- | --- | --- |
| R458 | sci_prophet_vs_ecr738 pagina 2; pvs_service pagina 6 | Resistenza modificata vicino a pressure sensor/U459 | ECR immagine indica 15K; verificare fisicamente e non assumere applicazione. |
| R321 | pvs_service pagina 4; sci_prophet_vs_ecr739 pagina 4 | Offset pressure circuit | Visibile come 50K nello schema ECR739/pvs. |
| R307/R308/R309/R320/R304 | pvs_service pagina 4; sci_prophet_vs_ecr739 pagina 4 | Rete pressure circuit | Valori leggibili su ECR739: 20K/10K/47K/10K/15K, da verificare. |
| C401/C402 | pvs_service pagina 6 | Capacitori/regolatori locali analogici | Vicino a 7905/78M05; verificare polarita e ripple. |
| C301 | pvs_service pagina 4; sci_prophet_vs_ecr739 pagina 4 | OCR/immagine: contesto da verificare nella page note | Estratto automaticamente; possibili falsi OCR. |
| C304 | pvs_service pagina 4; pvs_service pagina 5 | OCR/immagine: contesto da verificare nella page note | Estratto automaticamente; possibili falsi OCR. |
| C305 | pvs_service pagina 4; sci_prophet_vs_ecr739 pagina 4 | OCR/immagine: contesto da verificare nella page note | Estratto automaticamente; possibili falsi OCR. |
| C307 | pvs_service pagina 4 | OCR/immagine: contesto da verificare nella page note | Estratto automaticamente; possibili falsi OCR. |
| C308 | sci_prophet_vs_ecr739 pagina 4 | OCR/immagine: contesto da verificare nella page note | Estratto automaticamente; possibili falsi OCR. |
| C309 | pvs_service pagina 4 | OCR/immagine: contesto da verificare nella page note | Estratto automaticamente; possibili falsi OCR. |
| C317 | pvs_service pagina 5 | OCR/immagine: contesto da verificare nella page note | Estratto automaticamente; possibili falsi OCR. |
| C322 | pvs_service pagina 3 | OCR/immagine: contesto da verificare nella page note | Estratto automaticamente; possibili falsi OCR. |
| C323 | pvs_service pagina 12 | OCR/immagine: contesto da verificare nella page note | Estratto automaticamente; possibili falsi OCR. |
| C3238 | pvs_service pagina 5 | OCR/immagine: contesto da verificare nella page note | Estratto automaticamente; possibili falsi OCR. |
| C325 | pvs_service pagina 3; pvs_service pagina 5 | OCR/immagine: contesto da verificare nella page note | Estratto automaticamente; possibili falsi OCR. |
| C327 | pvs_service pagina 3 | OCR/immagine: contesto da verificare nella page note | Estratto automaticamente; possibili falsi OCR. |
| C329 | pvs_service pagina 5 | OCR/immagine: contesto da verificare nella page note | Estratto automaticamente; possibili falsi OCR. |
| C331 | pvs_service pagina 5 | OCR/immagine: contesto da verificare nella page note | Estratto automaticamente; possibili falsi OCR. |
| C334 | pvs_service pagina 5 | OCR/immagine: contesto da verificare nella page note | Estratto automaticamente; possibili falsi OCR. |
| C335 | pvs_service pagina 3; pvs_service pagina 5 | OCR/immagine: contesto da verificare nella page note | Estratto automaticamente; possibili falsi OCR. |
| C337 | pvs_service pagina 3; pvs_service pagina 5 | OCR/immagine: contesto da verificare nella page note | Estratto automaticamente; possibili falsi OCR. |
| C339 | pvs_service pagina 5 | OCR/immagine: contesto da verificare nella page note | Estratto automaticamente; possibili falsi OCR. |
| C340 | pvs_service pagina 3 | OCR/immagine: contesto da verificare nella page note | Estratto automaticamente; possibili falsi OCR. |
| C400 | pvs_service pagina 6 | OCR/immagine: contesto da verificare nella page note | Estratto automaticamente; possibili falsi OCR. |
| C402 | pvs_service pagina 6 | OCR/immagine: contesto da verificare nella page note | Estratto automaticamente; possibili falsi OCR. |
| C403 | pvs_service pagina 6 | OCR/immagine: contesto da verificare nella page note | Estratto automaticamente; possibili falsi OCR. |
| C404 | pvs_service pagina 6 | OCR/immagine: contesto da verificare nella page note | Estratto automaticamente; possibili falsi OCR. |
| C4051 | pvs_service pagina 7 | OCR/immagine: contesto da verificare nella page note | Estratto automaticamente; possibili falsi OCR. |
| C406 | pvs_service pagina 6 | OCR/immagine: contesto da verificare nella page note | Estratto automaticamente; possibili falsi OCR. |
| C409 | pvs_service pagina 7 | OCR/immagine: contesto da verificare nella page note | Estratto automaticamente; possibili falsi OCR. |
| C4124 | pvs_service pagina 9 | OCR/immagine: contesto da verificare nella page note | Estratto automaticamente; possibili falsi OCR. |
| C4162 | pvs_service pagina 9 | OCR/immagine: contesto da verificare nella page note | Estratto automaticamente; possibili falsi OCR. |
| C433 | pvs_service pagina 8 | OCR/immagine: contesto da verificare nella page note | Estratto automaticamente; possibili falsi OCR. |
| C440 | pvs_service pagina 10 | OCR/immagine: contesto da verificare nella page note | Estratto automaticamente; possibili falsi OCR. |
| C445 | pvs_service pagina 10 | OCR/immagine: contesto da verificare nella page note | Estratto automaticamente; possibili falsi OCR. |
| C449 | pvs_service pagina 8 | OCR/immagine: contesto da verificare nella page note | Estratto automaticamente; possibili falsi OCR. |
| C450 | pvs_service pagina 12 | OCR/immagine: contesto da verificare nella page note | Estratto automaticamente; possibili falsi OCR. |
| C466 | pvs_service pagina 6; pvs_service pagina 10 | OCR/immagine: contesto da verificare nella page note | Estratto automaticamente; possibili falsi OCR. |
| C470 | pvs_service pagina 6 | OCR/immagine: contesto da verificare nella page note | Estratto automaticamente; possibili falsi OCR. |
| C495 | pvs_service pagina 10 | OCR/immagine: contesto da verificare nella page note | Estratto automaticamente; possibili falsi OCR. |
| C497 | pvs_service pagina 10 | OCR/immagine: contesto da verificare nella page note | Estratto automaticamente; possibili falsi OCR. |
| C534 | pvs_service pagina 11 | OCR/immagine: contesto da verificare nella page note | Estratto automaticamente; possibili falsi OCR. |
| C597 | pvs_service pagina 11 | OCR/immagine: contesto da verificare nella page note | Estratto automaticamente; possibili falsi OCR. |
| C903 | pvs_service pagina 12 | OCR/immagine: contesto da verificare nella page note | Estratto automaticamente; possibili falsi OCR. |
| C904 | pvs_service pagina 12 | OCR/immagine: contesto da verificare nella page note | Estratto automaticamente; possibili falsi OCR. |
| C926 | pvs_service pagina 11 | OCR/immagine: contesto da verificare nella page note | Estratto automaticamente; possibili falsi OCR. |
| C927 | pvs_service pagina 11 | OCR/immagine: contesto da verificare nella page note | Estratto automaticamente; possibili falsi OCR. |
| C928 | pvs_service pagina 11 | OCR/immagine: contesto da verificare nella page note | Estratto automaticamente; possibili falsi OCR. |
| C930 | pvs_service pagina 11 | OCR/immagine: contesto da verificare nella page note | Estratto automaticamente; possibili falsi OCR. |
| C932 | pvs_service pagina 11 | OCR/immagine: contesto da verificare nella page note | Estratto automaticamente; possibili falsi OCR. |
| C937 | pvs_service pagina 12 | OCR/immagine: contesto da verificare nella page note | Estratto automaticamente; possibili falsi OCR. |
| C938 | pvs_service pagina 12 | OCR/immagine: contesto da verificare nella page note | Estratto automaticamente; possibili falsi OCR. |
| C940 | pvs_service pagina 11 | OCR/immagine: contesto da verificare nella page note | Estratto automaticamente; possibili falsi OCR. |
| C943 | pvs_service pagina 11 | OCR/immagine: contesto da verificare nella page note | Estratto automaticamente; possibili falsi OCR. |
| C947 | pvs_service pagina 12 | OCR/immagine: contesto da verificare nella page note | Estratto automaticamente; possibili falsi OCR. |
| C954 | pvs_service pagina 12 | OCR/immagine: contesto da verificare nella page note | Estratto automaticamente; possibili falsi OCR. |
| C962 | pvs_service pagina 11 | OCR/immagine: contesto da verificare nella page note | Estratto automaticamente; possibili falsi OCR. |
| C963 | pvs_service pagina 11 | OCR/immagine: contesto da verificare nella page note | Estratto automaticamente; possibili falsi OCR. |
| C964 | pvs_service pagina 11 | OCR/immagine: contesto da verificare nella page note | Estratto automaticamente; possibili falsi OCR. |
| C966 | pvs_service pagina 12 | OCR/immagine: contesto da verificare nella page note | Estratto automaticamente; possibili falsi OCR. |
| C967 | pvs_service pagina 11 | OCR/immagine: contesto da verificare nella page note | Estratto automaticamente; possibili falsi OCR. |
| C968 | pvs_service pagina 12 | OCR/immagine: contesto da verificare nella page note | Estratto automaticamente; possibili falsi OCR. |
| C969 | pvs_service pagina 12 | OCR/immagine: contesto da verificare nella page note | Estratto automaticamente; possibili falsi OCR. |
| C972 | pvs_service pagina 11 | OCR/immagine: contesto da verificare nella page note | Estratto automaticamente; possibili falsi OCR. |
| C975 | pvs_service pagina 12 | OCR/immagine: contesto da verificare nella page note | Estratto automaticamente; possibili falsi OCR. |
| C986 | pvs_service pagina 11 | OCR/immagine: contesto da verificare nella page note | Estratto automaticamente; possibili falsi OCR. |
| C988 | pvs_service pagina 11; pvs_service pagina 12 | OCR/immagine: contesto da verificare nella page note | Estratto automaticamente; possibili falsi OCR. |
| C995 | pvs_service pagina 11 | OCR/immagine: contesto da verificare nella page note | Estratto automaticamente; possibili falsi OCR. |
| R045 | pvs_service pagina 7 | OCR/immagine: contesto da verificare nella page note | Estratto automaticamente; possibili falsi OCR. |
| R109 | pvs_service pagina 11 | OCR/immagine: contesto da verificare nella page note | Estratto automaticamente; possibili falsi OCR. |
| R302 | pvs_service pagina 4; sci_prophet_vs_ecr739 pagina 4 | OCR/immagine: contesto da verificare nella page note | Estratto automaticamente; possibili falsi OCR. |
| R303 | pvs_service pagina 5 | OCR/immagine: contesto da verificare nella page note | Estratto automaticamente; possibili falsi OCR. |
| R304 | pvs_service pagina 4; sci_prophet_vs_ecr739 pagina 4 | OCR/immagine: contesto da verificare nella page note | Estratto automaticamente; possibili falsi OCR. |
| R305 | pvs_service pagina 4; sci_prophet_vs_ecr739 pagina 4 | OCR/immagine: contesto da verificare nella page note | Estratto automaticamente; possibili falsi OCR. |
| R307 | pvs_service pagina 4; sci_prophet_vs_ecr739 pagina 4 | OCR/immagine: contesto da verificare nella page note | Estratto automaticamente; possibili falsi OCR. |
| R308 | pvs_service pagina 4; sci_prophet_vs_ecr739 pagina 4 | OCR/immagine: contesto da verificare nella page note | Estratto automaticamente; possibili falsi OCR. |
| R309 | pvs_service pagina 4; sci_prophet_vs_ecr739 pagina 4 | OCR/immagine: contesto da verificare nella page note | Estratto automaticamente; possibili falsi OCR. |
| R313 | pvs_service pagina 5 | OCR/immagine: contesto da verificare nella page note | Estratto automaticamente; possibili falsi OCR. |
| R314 | pvs_service pagina 5 | OCR/immagine: contesto da verificare nella page note | Estratto automaticamente; possibili falsi OCR. |
| R315 | sci_prophet_vs_ecr739 pagina 4 | OCR/immagine: contesto da verificare nella page note | Estratto automaticamente; possibili falsi OCR. |
| R320 | pvs_service pagina 4; pvs_service pagina 5; sci_prophet_vs_ecr739 pagina 4 | OCR/immagine: contesto da verificare nella page note | Estratto automaticamente; possibili falsi OCR. |
| R323 | pvs_service pagina 3 | OCR/immagine: contesto da verificare nella page note | Estratto automaticamente; possibili falsi OCR. |
| R324 | pvs_service pagina 3 | OCR/immagine: contesto da verificare nella page note | Estratto automaticamente; possibili falsi OCR. |
| R327 | pvs_service pagina 3 | OCR/immagine: contesto da verificare nella page note | Estratto automaticamente; possibili falsi OCR. |
| R328 | pvs_service pagina 3 | OCR/immagine: contesto da verificare nella page note | Estratto automaticamente; possibili falsi OCR. |
| R330 | sci_prophet_vs_ecr739 pagina 4 | OCR/immagine: contesto da verificare nella page note | Estratto automaticamente; possibili falsi OCR. |
| R332 | pvs_service pagina 3 | OCR/immagine: contesto da verificare nella page note | Estratto automaticamente; possibili falsi OCR. |
| R333 | pvs_service pagina 3 | OCR/immagine: contesto da verificare nella page note | Estratto automaticamente; possibili falsi OCR. |
| R334 | pvs_service pagina 3; pvs_service pagina 5 | OCR/immagine: contesto da verificare nella page note | Estratto automaticamente; possibili falsi OCR. |
| R403 | pvs_service pagina 7 | OCR/immagine: contesto da verificare nella page note | Estratto automaticamente; possibili falsi OCR. |
| R406 | pvs_service pagina 7 | OCR/immagine: contesto da verificare nella page note | Estratto automaticamente; possibili falsi OCR. |
| R420 | pvs_service pagina 11 | OCR/immagine: contesto da verificare nella page note | Estratto automaticamente; possibili falsi OCR. |
| R424 | pvs_service pagina 8 | OCR/immagine: contesto da verificare nella page note | Estratto automaticamente; possibili falsi OCR. |
| R426 | pvs_service pagina 7 | OCR/immagine: contesto da verificare nella page note | Estratto automaticamente; possibili falsi OCR. |
| R435 | pvs_service pagina 7 | OCR/immagine: contesto da verificare nella page note | Estratto automaticamente; possibili falsi OCR. |
| R455 | pvs_service pagina 12 | OCR/immagine: contesto da verificare nella page note | Estratto automaticamente; possibili falsi OCR. |
| R462 | pvs_service pagina 9 | OCR/immagine: contesto da verificare nella page note | Estratto automaticamente; possibili falsi OCR. |
| R463 | pvs_service pagina 9 | OCR/immagine: contesto da verificare nella page note | Estratto automaticamente; possibili falsi OCR. |
| R474 | pvs_service pagina 10 | OCR/immagine: contesto da verificare nella page note | Estratto automaticamente; possibili falsi OCR. |
| R476 | pvs_service pagina 9 | OCR/immagine: contesto da verificare nella page note | Estratto automaticamente; possibili falsi OCR. |
| R520 | pvs_service pagina 12 | OCR/immagine: contesto da verificare nella page note | Estratto automaticamente; possibili falsi OCR. |
| R921 | pvs_service pagina 12 | OCR/immagine: contesto da verificare nella page note | Estratto automaticamente; possibili falsi OCR. |
| R922 | pvs_service pagina 12 | OCR/immagine: contesto da verificare nella page note | Estratto automaticamente; possibili falsi OCR. |
| R924 | pvs_service pagina 12 | OCR/immagine: contesto da verificare nella page note | Estratto automaticamente; possibili falsi OCR. |
| R929 | pvs_service pagina 11 | OCR/immagine: contesto da verificare nella page note | Estratto automaticamente; possibili falsi OCR. |
| R936 | pvs_service pagina 11 | OCR/immagine: contesto da verificare nella page note | Estratto automaticamente; possibili falsi OCR. |
| R939 | pvs_service pagina 11 | OCR/immagine: contesto da verificare nella page note | Estratto automaticamente; possibili falsi OCR. |
| R940 | pvs_service pagina 12 | OCR/immagine: contesto da verificare nella page note | Estratto automaticamente; possibili falsi OCR. |
| R947 | pvs_service pagina 12 | OCR/immagine: contesto da verificare nella page note | Estratto automaticamente; possibili falsi OCR. |
| R953 | pvs_service pagina 12 | OCR/immagine: contesto da verificare nella page note | Estratto automaticamente; possibili falsi OCR. |
| R954 | pvs_service pagina 12 | OCR/immagine: contesto da verificare nella page note | Estratto automaticamente; possibili falsi OCR. |
| R957 | pvs_service pagina 11 | OCR/immagine: contesto da verificare nella page note | Estratto automaticamente; possibili falsi OCR. |
| R983 | pvs_service pagina 11 | OCR/immagine: contesto da verificare nella page note | Estratto automaticamente; possibili falsi OCR. |
| RA202 | pvs_service pagina 2 | OCR/immagine: contesto da verificare nella page note | Estratto automaticamente; possibili falsi OCR. |

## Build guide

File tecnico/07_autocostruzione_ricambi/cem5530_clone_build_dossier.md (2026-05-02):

# CEM5530 / ELD5530: dossier per clone o ricostruzione

## Stato della ricerca

Data ricerca: 2026-05-02.

Non ho trovato schemi, Gerber, PCB layout o BOM pubblici e verificabili per `ELD5530`, Straylight `CEM5530 replacement module`, Wine Country, NMC/Cantos o vecchie board `PD508/CEM5508`.

Quello che risulta dalle fonti:

- `ELD5530` e' un modulo sostitutivo, non un `CEM5530` originale modificato.
- La pagina Synthelectro 2014 descrive una versione 2 basata su IC Maxim Integrated, con gestione alimentazioni integrata e inserimento diretto al posto del `CEM5530`; la sigla dell'IC Maxim non viene pubblicata li.
- La stessa pagina dice che la prima versione richiedeva due modifiche minori sulla board perche' non gestiva tutte le alimentazioni, mentre la versione 2 fornisce direttamente le tensioni necessarie.
- Gearspace cita una clonazione tramite Maxim `MAX5167` e riporta che qualcuno intendeva rimettere online gli schemi, ma non ho trovato quegli schemi pubblicati. Quindi `MAX5167` e' la pista tecnica piu plausibile, non una conferma ufficiale della BOM ELD5530.
- Nello stesso thread viene chiesto a Eric Penot di rilasciare specifiche complete/open source, ma non ho trovato evidenza che siano state pubblicate.
- Straylight descrive un proprio modulo `CEM5530` a PCB 4 layer prodotto in fabbrica, ma non pubblica schema o file di produzione.
- La foto utente mostra due moduli `Straylight Engineering X5530` con quattro IC `SMP18` per scheda. Questa e' una pista reale gia disponibile, da verificare fisicamente prima di comprare altro.
- Le vecchie alternative citate nei forum includono board basate su `SSM2300` e board basate su `PD508/CEM5508`, ma anche qui senza file di progetto pubblici.

Nota batteria: la pagina Synthelectro 2015 cita sia mod SRAM non volatile sia due `ELD5530` nello stesso Prophet VS. Solo la mod SRAM non volatile elimina la batteria; `ELD5530` non riguarda la memoria patch. Vedere `../01_problemi_e_fix/batteria_memoria_nvram.md`.

Conclusione operativa: questo non e' un progetto pronto da mandare in produzione. E' un dossier per permettere a un tecnico/progettista di ricostruire un modulo con metodo, oppure di valutare un modulo acquistato.

## Documenti locali da usare

- `../06_pdf_originali/5530.pdf`: datasheet preliminare `CEM5530`.
- `../05_pagine_rilevanti/immagini/5530/page_002.png`: pinout/diagramma `CEM5530`; OCR scarso, leggere l'immagine.
- `../05_pagine_rilevanti/note/5530/page_002.md`: nota su pinout/orientamento.
- `../05_pagine_rilevanti/note/5530/page_003.md`: limiti alimentazione e swing uscite.
- `../05_pagine_rilevanti/note/5530/page_004.md`: timing `INH`, auto-zero, acquisition e droop.
- `../06_pdf_originali/pvs_service.pdf`, pagina 6: `U449/U425`, DAC, `INH`, CV `VCA/VCF/PAN/LEV`, rail locali.
- `../05_pagine_rilevanti/immagini/pvs_service/page_006.png`: schema Prophet VS dell'area S&H/CV.
- `../06_pdf_originali/5508.pdf`: datasheet `PD508/CEM5508`, utile per capire le vecchie architetture a 4 chip.

Datasheet esterni da scaricare/verificare:

- Analog Devices `SMP18`: `https://www.analog.com/en/products/smp18.html`
- Maxim/Analog Devices `MAX5167-MAX5167N`: `https://www.analog.com/media/en/technical-documentation/data-sheets/MAX5167-MAX5167N.pdf`
- Analog Devices `MAX5167L` product page: `https://www.analog.com/en/products/max5167l.html`
- Analog Devices `SSM2300`: `https://www.analog.com/en/products/ssm2300.html`
- Analog Devices `SSM2300` obsolete datasheet: `https://www.analog.com/media/en/technical-documentation/obsolete-data-sheets/ssm2300.pdf`

## Fatti primari dal post Synthelectro 2014

Il post Synthelectro 2014 e' la fonte migliore per descrivere `ELD5530` senza mischiarlo con la mod memoria/batteria:

- `CEM5530` e' descritto come interfaccia tra processore digitale e generazione analogica;
- ogni `CEM5530` viene paragonato a `30` potenziometri comandati dal processore;
- il Prophet VS usa due `CEM5530`, per `60` segnali di controllo totali;
- lo Studio 440 usa un solo `CEM5530`;
- sul Prophet VS le posizioni sono `U449` e `U425`;
- la prima scheda sostitutiva richiedeva due modifiche minori sulla board per le alimentazioni;
- `ELD5530 V2` integra quelle alimentazioni e viene presentato come ricambio plug-in;
- i socket originali del Prophet VS sono indicati come double-lyre, meno affidabili dei tulip, con rischio rottura delle zampe/saldature;
- nella foto Synthelectro, originale e ricambio sono mostrati nello stesso verso, con pin 1 in basso a sinistra. Usare questa informazione solo insieme alla serigrafia reale.

## Requisito funzionale

Il Prophet VS monta due `CEM5530`:

- `U449`: CV legate a `VCA`, `VCF`, `PAN`, chorus/final CV e altre uscite;
- `U425`: area `LEV` e altre CV.

Ogni ricambio deve comportarsi come un `CEM5530` a `30` canali sample & hold con ingresso multiplexato, decoder/address a 5 bit, controllo `INH`, hold capacitor integrati/equivalenti e uscite compatibili con i carichi del Prophet VS.

## Schema di principio, non PCB-ready

Questo e' solo il blocco logico da progettare; non e' uno schema elettrico completo.

```text
Prophet VS socket CEM5530
  A0..A4  -------------------->  address logic  ---------->  S&H IC address
  INH     -------------------->  polarity/timing logic ---->  S&H sample/hold enable
  DAC/SWIN input ------------->  input buffer/protection -->  S&H common input
  VDD/VSS/rail locali -------->  local regulation/filter -->  S&H analog/digital rails
  AGND/DGND/ground ---------->  grounding strategy ------->  S&H grounds
  OUT0..OUT29 <---------------  S&H outputs 0..29
  unused channels <-----------  NC/clamped/held per datasheet
```

Prima di disegnare una PCB, compilare una tabella pin-to-pin reale partendo dall'immagine `5530/page_002.png` e dallo schema `pvs_service` pagina 6. L'OCR del pinout non e' affidabile.

## Architettura A: Straylight `X5530` con 4 x `SMP18`

E' la pista piu concreta per questa macchina perche due moduli sono stati trovati fisicamente.

La foto mostra quattro IC `SMP18` per scheda. Il `SMP18` e' un sample & hold ottale a ingresso multiplexato: quattro IC danno `32` canali teorici, sufficienti per emulare un `CEM5530` a `30` canali con due canali extra non usati o gestiti dalla logica.

Questa architettura non e' `ELD5530` Synthelectro e non e' il prototipo `MAX5167`. E' il clone/ricambio Straylight gia documentato come board `5530`.

Azioni:

- leggere `straylight_x5530_moduli_trovati.md`;
- verificare pin 1 e socket originali prima dell'installazione;
- non aggiungere dissipatori ai cloni `X5530` prima di avere misure: i dissipatori citati per il Prophet VS sono per i `CEM5530` originali;
- se serve, scrivere a Straylight solo per istruzioni/orientamento, non per comprare subito;
- considerare `MAX5167` solo come backup se questi moduli non sono utilizzabili.

## Architettura B: `MAX5167`

E' l'architettura piu vicina a quanto viene attribuito a `ELD5530`, ma va trattata come ipotesi tecnica: Synthelectro conferma "Maxim Integrated", non la sigla `MAX5167`.

Il `MAX5167` e' un sample & hold a `32` canali con ingresso multiplexato, 5 linee address, controllo sample/hold, uscite `OUT0..OUT31`, alimentazione analogica positiva/negativa e alimentazione logica separata. Questo lo rende concettualmente adatto a sostituire un `CEM5530` a `30` canali, ma solo tramite una schedina adattatrice.

Per la prosecuzione concreta della pista `MAX5167`, usare il progetto preliminare dedicato `max5167_v2_like_pre_design.md` e poi la cartella Rev A prototipo `rev_a_max5167_prototipo/`.

Punti da progettare/verificare:

- mapping `CEM5530 OUT0..OUT29` verso `MAX5167 OUT0..OUT29` o altra numerazione confermata;
- trattamento dei due canali extra `MAX5167`;
- polarita' e timing tra `CEM5530 INH` e ingressi `SELECT`/`S/H` del `MAX5167`;
- rail: il `MAX5167` richiede rail propri; non collegare rail Prophet a caso;
- scelta variante `MAX5167L/M/N` per impedenza uscita e compatibilita' col carico;
- disponibilita' reale del chip e rischio componenti contraffatti/obsolete;
- altezza meccanica dentro il Prophet VS.

Nota critica: la pagina Synthelectro dice che la versione 2 include la gestione delle alimentazioni necessarie. Questo e' un indizio forte che una semplice piedinatura adattata non basta.

## Architettura C: 4 x `SSM2300`

Architettura citata per vecchie board NMC/Cantos/John Leimseider.

`SSM2300` e' un sample & hold multiplexato a 8 canali. Quattro IC danno 32 canali teorici, sufficienti per emulare 30 canali `CEM5530`.

Punti da progettare/verificare:

- decode 5-bit `CEM5530` in selezione chip + indirizzo 3-bit per i quattro `SSM2300`;
- comportamento di hold per i chip non selezionati;
- compatibilita' swing uscita, droop, hold step, carico capacitivo e output buffering;
- disponibilita' `SSM2300`: il prodotto e' obsoleto, quindi eventuali chip sono NOS/pull;
- layout piu grande e maggior numero di componenti rispetto a `MAX5167`.

Questa strada e' interessante solo se il tecnico ha accesso a `SSM2300` autentici e accetta una progettazione piu complessa.

## Architettura D: 4 x `PD508/CEM5508`

Architettura storica citata per vecchie board Wine Country / emulatori anni 90.

`PD508/CEM5508` e' un octal sample & hold. Quattro chip danno 32 canali teorici, ma anche questi componenti sono rari e vecchi.

Usare `../06_pdf_originali/5508.pdf` per confrontare timing, hold, droop e carico, ma non considerarla la scelta preferita se i chip sono difficili da trovare o non testati.

## Materiali minimi da prevedere

Per un progetto vero servono almeno:

- IC S&H scelto: `MAX5167` oppure 4 x `SSM2300` oppure 4 x `PD508/CEM5508`;
- PCB adattatore con footprint maschio compatibile `CEM5530` 40 pin;
- eventuale logica glue per polarita', decode e chip-select;
- regolatori locali o riferimenti/filtri per rail richiesti dall'IC scelto;
- decoupling ravvicinato su ogni rail analogico e logico;
- connessione massa analogica/digitale ragionata, non improvvisata;
- pin/header torniti o contatti affidabili;
- socket tornito/tulip di qualita' sulla board Prophet se quello originale e' fragile;
- test fixture per provare la scheda fuori dal synth.

## Checklist di progettazione

1. Ricavare pinout `CEM5530` manualmente dall'immagine `5530/page_002.png`.
2. Verificare sul Prophet VS reale orientamento pin 1 e spazio verticale disponibile.
3. Misurare rail reali sui socket `U449/U425` prima di progettare alimentazioni.
4. Misurare con oscilloscopio `INH`, address e DAC input durante aggiornamento CV.
5. Decidere architettura e IC disponibili da fonte affidabile.
6. Disegnare schema e fare revisione incrociata pin-to-pin.
7. Prevedere protezioni/serie resistors se necessarie per output e carichi capacitivi.
8. Produrre un primo prototipo e testarlo fuori dal Prophet VS.
9. Installare un solo modulo alla volta, con controllo corrente e temperatura.
10. Confrontare CV e comportamento audio prima/dopo con patch di test.

## Test minimi fuori dal synth

- nessun corto tra rail e massa;
- assorbimento corrente coerente a freddo e a caldo;
- ogni indirizzo aggiorna solo il canale previsto;
- `INH`/sample/hold rispettano il timing del `CEM5530`;
- droop entro limiti accettabili per il refresh rate reale del Prophet VS;
- swing uscita corretto per le CV richieste;
- stabilita' con carichi simili a quelli delle CV Prophet;
- temperatura stabile dopo almeno 30-60 minuti;
- nessuna oscillazione o glitch anomalo sulle uscite hold.

## Cosa chiedere se si contatta l'autore

Messaggio utile per Synthelectro/Eric Penot:

```text
Hello,
I am repairing a Sequential Circuits Prophet VS and want to preserve it long term.
If ELD5530 modules are no longer available, would you be willing to share or sell
the schematic, PCB/Gerber files, BOM, or enough documentation for my technician
to build two replacement modules for U449 and U425?

I understand this may be a non-public design; I am not asking to publish it,
only to make a repair possible if no finished modules are available.

Thank you.
```

Messaggio utile per Straylight/Tom Virostek:

```text
Hello,
I am repairing a Sequential Circuits Prophet VS and need two CEM5530 replacement
modules for U449 and U425. If modules are no longer available, would you be
willing to share or sell documentation, schematic, Gerbers, BOM, or recommend
a way for a technician to reproduce or service the modules?

Thank you.
```

## Fonti

- Synthelectro, post 2014 `Remplacement du CEM5530 pour Prophet VS & Studio 440`: `https://synthelectro-fr.blogspot.com/2014/06/cem5530-pour-prophet-vs-studio-440.html`
- Synthelectro, archivio giugno 2014 con lo stesso post: `https://synthelectro-fr.blogspot.com/2014/06/`
- Synthelectro, post 2015 con due `ELD5530`: `https://synthelectro-fr.blogspot.com/2015/07/how-to-upgrade-programm-memory-of.html`
- Gearspace, discussione affidabilita Prophet VS e cloni `CEM5530`: `https://gearspace.com/board/electronic-music-instruments-and-electronic-music-production/724391-prophet-vs-reliability.html`
- Gearspace, pagina 2 stessa discussione: `https://gearspace.com/board/electronic-music-instruments-and-electronic-music-production/724391-prophet-vs-reliability-2.html`
- Straylight Engineering, vecchia pagina clone 5530: `https://www.straylightengineering.com/5530-clone-boards-available-new-design/`
- Straylight Engineering, update Jan 2023: `https://www.straylightengineering.com/update-jan-2023/`
- Analog Devices `SMP18`: `https://www.analog.com/en/products/smp18.html`
- Analog Devices / Maxim `MAX5167`: `https://www.analog.com/en/products/max5167l.html`
- Analog Devices / Maxim `MAX5167` datasheet PDF: `https://www.analog.com/media/en/technical-documentation/data-sheets/MAX5167-MAX5167N.pdf`
- Analog Devices `SSM2300`: `https://www.analog.com/en/products/ssm2300.html`
- Analog Devices `SSM2300` obsolete datasheet: `https://www.analog.com/media/en/technical-documentation/obsolete-data-sheets/ssm2300.pdf`

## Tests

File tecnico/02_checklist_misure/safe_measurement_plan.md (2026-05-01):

# Safe measurement plan

## Ordine consigliato
1. Ispezione visiva a strumento spento.
2. Verifica concettuale di ground e assenza di corti evidenti.
3. Misura rail a basso rischio: +5VD, +12V, -12V, +8V, +5.6V, -5V dove indicati dagli schemi.
4. Solo dopo rail stabili, osservare SENSOR/PRESSURE, VCA/VCF/PAN/LEV e output audio.

## Cautele
- Mains/trasformatore: tecnico qualificato.
- Usare puntali sicuri e massa corretta; evitare corti tra pin adiacenti.
- Non usare forza su vecchi connettori o pad.
- Non dissaldare componenti rari prima di avere evidenza.

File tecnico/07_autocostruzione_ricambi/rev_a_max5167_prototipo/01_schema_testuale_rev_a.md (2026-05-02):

# Schema testuale Rev A

## Convenzioni

Questo documento descrive lo schema elettrico che il tecnico deve riportare in CAD.

Sigle:

- `J1`: connettore/pin maschio verso socket `CEM5530` 40 pin.
- `U1`: `MAX5167L/M/N`, 48-TQFP.
- `U2`: convertitore boost da `+8V_IN` a `+11V_PRE`.
- `U3`: regolatore/filtraggio da `+11V_PRE` a `+10V_A`.
- `U4`: LDO da `+8V_FILT` a `+5V_L`.
- `U5`: logica opzionale DNP per stretching `S/H`.
- `RN_OUT`: resistenze serie opzionali sulle uscite.
- `RN_LOGIC`: resistenze serie opzionali su address e `INH`.

## J1 - socket CEM5530

J1 deve essere un adattatore maschio compatibile con package `CEM5530` 40 pin.

| J1 pin | Net Rev A |
| --- | --- |
| 1 | `VIN_IN` |
| 2-9 | `CV0..CV7` |
| 10 | `INH_IN` |
| 11 | `A4_IN` |
| 12-19 | `CV8..CV15` |
| 20 | `VSS_IN` |
| 21 | `GND_IN` |
| 22-29 | `CV16..CV23` |
| 30 | `A0_IN` |
| 31 | `A1_IN` |
| 32 | `A2_IN` |
| 33 | `A3_IN` |
| 34-39 | `CV24..CV29` |
| 40 | `VDD_IN` |

## U1 - MAX5167

### Alimentazione U1

| U1 pin | Net |
| --- | --- |
| 7 `VL` | `+5V_L` |
| 8 `DGND` | `DGND_LOCAL` |
| 9 `VSS` | `-5V_A` |
| 10 `AGND` | `AGND_LOCAL` |
| 30 `VDD` | `+10V_A` |

`AGND_LOCAL` e `DGND_LOCAL` devono unirsi in un punto locale vicino a U1 e tornare a `GND_IN`.

### Clamp U1

| U1 pin | Net | Popolamento Rev A |
| --- | --- | --- |
| 12 `CH` | `+10V_A` | `0R` o short locale |
| 13 `CL` | `-5V_A` | `0R` o short locale |

Motivo: lasciare le clamp ai rail analogici del `MAX5167`, evitando clamp intermedie prima delle misure reali delle CV.

### Ingresso analogico

```text
J1 pin 1 VIN_IN
  -> RIN1 0R/100R footprint, default 0R
  -> TP_VIN
  -> U1 pin 11 IN
```

Non aggiungere condensatori verso massa in Rev A salvo footprint DNP: il DAC Prophet e il timing sample non vanno rallentati senza misura.

### Logica address

```text
J1 pin 30 A0_IN -> RN_LOGIC 47R/0R -> U1 pin 47 ADDR0
J1 pin 31 A1_IN -> RN_LOGIC 47R/0R -> U1 pin 48 ADDR1
J1 pin 32 A2_IN -> RN_LOGIC 47R/0R -> U1 pin 1  ADDR2
J1 pin 33 A3_IN -> RN_LOGIC 47R/0R -> U1 pin 2  ADDR3
J1 pin 11 A4_IN -> RN_LOGIC 47R/0R -> U1 pin 3  ADDR4
```

Default consigliato per il primo prototipo: `0R` o `47R`, da scegliere dopo aver visto fronti e ringing.

### Logica sample/hold

Rev A default direct:

```text
J1 pin 10 INH_IN
  -> RN_LOGIC 47R/0R
  -> JP1 posizione DIRECT
  -> U1 pin 5 S/H
```

Polarita' prevista:

- `INH_IN` high -> `S/H` high -> hold;
- `INH_IN` low -> `S/H` low -> sample del canale indirizzato.

Footprint opzionale:

```text
INH_IN -> U5 DNP stretcher/logic -> JP1 posizione STRETCH -> U1 pin 5 S/H
```

`U5` non va popolato in Rev A iniziale. Serve solo se le misure mostrano che `INH low` e' troppo breve per acquisire con precisione.

### SELECT / CONFIG

```text
U1 pin 6 CONFIG -> RCFG 10k -> DGND_LOCAL
U1 pin 4 SELECT -> RSEL 10k -> +5V_L
```

Con `CONFIG` low, `SELECT` e' active-high. Tenendolo high, `S/H` resta sempre abilitato.

## Uscite CV

Ogni uscita usata passa da un footprint serie verso il pin CEM corrispondente.

```text
U1 OUTn -> R_OUTn 0R/100R/470R footprint -> J1 CVn
```

Default consigliato per Rev A:

- popolamento iniziale: `0R`;
- usare `100R` o `470R` solo se test di carico/capacita' mostrano ringing o instabilita';
- non aggiungere condensatori verso massa salvo footprint DNP.

`OUT30` e `OUT31`:

```text
U1 pin 45 OUT30 -> TP_OUT30, NC verso J1
U1 pin 46 OUT31 -> TP_OUT31, NC verso J1
```

## Alimentazioni

### Ingresso +8V

```text
J1 pin 40 VDD_IN
  -> F1/POLYFUSE opzionale o 0R
  -> FB1 ferrite/0R
  -> +8V_FILT
  -> C1 10uF verso GND_IN
  -> C2 100nF verso GND_IN
```

### Generazione +10V analogico

```text
+8V_FILT
  -> U2 boost con soft-start/enable
  -> +11V_PRE
  -> C3/C4 filtro locale
  -> U3 LDO/low-noise regulator
  -> +10V_A target 9.8V..10.0V
  -> C5 10uF verso AGND_LOCAL
  -> C6 100nF vicino a U1 pin 30
```

Note:

- target pratico `+9.8V..+10.0V`, non oltre, per rispettare margine `VDD-VSS`;
- `+11V_PRE` va scelto solo quanto basta per dropout di U3;
- se il tecnico sceglie boost diretto a `+10V_A`, deve dimostrare ripple e startup accettabili al banco.

### Generazione +5V logico

```text
+8V_FILT
  -> U4 LDO +5V
  -> +5V_L
  -> C7 4.7uF/10uF verso DGND_LOCAL
  -> C8 100nF vicino a U1 pin 7
```

### Ingresso -5V

```text
J1 pin 20 VSS_IN
  -> FB2 ferrite/0R
  -> -5V_A
  -> C9 10uF verso AGND_LOCAL
  -> C10 100nF vicino a U1 pin 9
```

### Masse

```text
J1 pin 21 GND_IN
  -> punto stella locale
  -> AGND_LOCAL
  -> DGND_LOCAL
```

Non creare loop di massa con piani separati collegati in piu punti.

## Protezione startup

Rev A deve prevedere almeno footprint per:

- soft-start/enable di U2;
- test pad `+8V_FILT`, `+11V_PRE`, `+10V_A`, `+5V_L`, `-5V_A`;
- clamp/TVS DNP sui rail se il tecnico li ritiene necessari dopo simulazione e test;
- resistenza/0R per isolare il boost durante debugging.

Regola: se `-5V_A` manca, `+10V_A` non deve superare il limite `VDD-VSS` del `MAX5167`.

## Test pad minimi

| Test pad | Net |
| --- | --- |
| `TP_GND` | `GND_IN` |
| `TP_8VIN` | `+8V_FILT` |
| `TP_11PRE` | `+11V_PRE` |
| `TP_10A` | `+10V_A` |
| `TP_5L` | `+5V_L` |
| `TP_N5A` | `-5V_A` |
| `TP_VIN` | `VIN_IN` |
| `TP_INH` | `INH_IN` |
| `TP_A0..TP_A4` | address |
| `TP_OUT0` | `CV0` |
| `TP_OUT15` | `CV15` |
| `TP_OUT29` | `CV29` |
| `TP_OUT30` | `OUT30` solo test |
| `TP_OUT31` | `OUT31` solo test |

## DNP obbligatori in Rev A

Questi footprint devono esserci, ma normalmente non vanno popolati nella prima accensione:

- U5 stretching `S/H`;
- capacitori verso massa sulle uscite CV;
- clamp/TVS rail locali;
- resistenze alternative di uscita diverse da `0R`;
- filtro RC su `VIN`.

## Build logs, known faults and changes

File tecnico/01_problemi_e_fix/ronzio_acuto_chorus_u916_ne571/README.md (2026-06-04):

# Ronzio acuto nel chorus, bypass U916 e NE571

## Scopo
Nota pratica per diagnosticare il chorus del Prophet VS quando, con chorus
inserito, si sente un ronzio acuto tipo "mosca".

Questo sintomo non va liquidato come normale rumore BBD: un BBD puo' essere
rumoroso, ma di solito produce fruscio/grana morbida, non un ronzio acuto e
insistente. Il bypass dell'ultimo integrato della catena puo' essere stato utile
come prova per far ripassare segnale, ma il chorus in questa condizione non e'
ripristinato come da progetto.

Il service manual mostra che il Prophet VS usa due `NE571` fisici nel chorus:
non sono due soppressori ridondanti, ma due parti del sistema compander.

Il `NE571` comprime/condiziona il segnale prima del BBD e lo riespande dopo il
BBD. Serve a tenere corretti livello e dinamica e a limitare quanto rumore o
clock residue della linea delay arriva all'uscita.

## Riferimenti service manual
- `../../05_pagine_rilevanti/immagini/pvs_service/page_006.png`: S&H/CV,
  `LEFT CHORUS CV`, `RIGHT CHORUS CV`, `LEFT CHORUS ON`, `RIGHT CHORUS ON`
- `../../05_pagine_rilevanti/immagini/pvs_service/page_011.png`: `LEFT CHORUS`
- `../../05_pagine_rilevanti/immagini/pvs_service/page_012.png`: `RIGHT CHORUS`
- `../../05_pagine_rilevanti/note/pvs_service/page_006.md`
- `../../05_pagine_rilevanti/note/pvs_service/page_011.md`
- `../../05_pagine_rilevanti/note/pvs_service/page_012.md`
- `../../06_pdf_originali/pvs_service.pdf`: pagine 6, 11 e 12

## Flusso chorus
- `U903 NE571`: primo stadio compander, prima della linea BBD.
- `U916 NE571`: secondo stadio compander, dopo BBD e filtri, prima dello switch
  chorus ON e dell'uscita audio.

```text
LEFT/RIGHT VOICES
-> U903 NE571
-> filtri 7 kHz
-> BBD 3209
-> filtri 7 kHz
-> U916 NE571
-> U918 4007 / chorus ON
-> uscita audio
```

## Lettura del bypass
Il bypass riferito e' sull'ultimo integrato della catena chorus, quindi va
interpretato come bypass di `U916`, il secondo `NE571`.

Dato osservato:
- prima del bypass il chorus era muto;
- sono stati provati piu' `NE571` sostitutivi, circa 5, senza risolvere;
- bypassando l'ultimo integrato della catena il chorus torna a passare, ma con
  ronzio acuto.

Questa combinazione sposta il sospetto dal singolo chip alla zona che lo fa
lavorare:
- zoccolo di `U916`, contatti lenti/ossidati, pin piegati, saldature crepate;
- alimentazione, decoupling e bias di `U916`;
- resistenze/condensatori della rete esterna del compander;
- pista o piazzola interrotta;
- uscita di `U916` caricata o bloccata da un guasto successivo;
- ricambi `NE571` non affidabili, fake o non realmente equivalenti.

Se il bypass salta solo `U916` e lascia ancora nel percorso `U918 4007`, il test
indica che il wet signal esiste a monte e che BBD/filtri generano almeno un
segnale udibile. Se invece il bypass salta anche `U918` o parte del routing,
vanno controllati anche consenso chorus ON e switch.

## Tre aree da separare
- Audio wet: `U903 -> filtri -> 3209 -> filtri -> U916 -> U918 -> uscita`.
- Clock/modulazione BBD: `7555`, `4013`, `3209`, clock trim,
  `LEFT/RIGHT CHORUS CV`.
- Consenso chorus ON: `LEFT CHORUS ON`, `RIGHT CHORUS ON`, `U918 4007`.

Un guasto al compander puo' zittire il wet signal. Un guasto al clock puo'
lasciare il wet muto o produrre ronzio acuto. Un guasto al consenso ON puo'
impedire l'inserimento del chorus anche se il wet signal esiste.

## Ronzio acuto
Nel service:
- left clock: `U912 7555` + `U913 4013` -> `U911 3209`
- right clock: `U906 7555` + `U907 4013` -> `U909 3209`
- annotazione schema: `400 kHz - 40 kHz`
- filtri audio indicati come `7 kHz LOWPASS`

Se dopo il bypass compare il ronzio acuto, le ipotesi principali sono:
- il bypass ha tolto `U916`, cioe' lo stadio che doveva ripristinare
  livello/rumore dopo il BBD;
- il ronzio era gia' generato a monte da clock/filtro/BBD, ma prima non era
  udibile perche' il ramo wet veniva bloccato;
- un filtro post-BBD o una rete attorno a `U916` non sta tagliando/gestendo
  correttamente il clock residue.

## Misure consigliate
Usare sonda x10, massa corta e attenzione a non cortocircuitare pin vicini.
Annotare se il difetto e' left, right o entrambi.

1. Documentare esattamente il bypass: quali pin/componenti sono stati uniti e
   se `U918 4007` e' ancora nel percorso.
2. Verificare rail nell'area chorus: `+12V`, `-12V`, `+8V LEFT/RT`, `+5V`.
3. Con `U916` montato, misurare alimentazione, decoupling e bias. Lo schema
   indica riferimenti intorno a circa `1.8V` sugli ingressi del compander.
4. Controllare zoccolo, saldature, piste e continuita' da ogni pin di `U916`
   ai componenti esterni vicini.
5. Cercare segnale all'ingresso di `U916`:
   - left: lato `C957 .22`;
   - right: lato `C954 .22`.
6. Cercare segnale all'uscita di `U916`, con bypass rimosso:
   - left: `U916` pin 7, poi `C911`;
   - right: `U916` pin 10, poi `C966`.
7. Misurare clock BBD:
   - left: `U912` pin 3, `U913` Q/Qbar, `U911` `CP1/CP2`;
   - right: `U906` pin 3, `U907` Q/Qbar, `U909` `CP1/CP2`.
8. Cercare il ronzio prima e dopo i filtri 7 kHz post-BBD.
9. Verificare lo switch chorus:
   - `U918 4007`, controlli `LEFT CHORUS ON` e `RIGHT CHORUS ON`.
10. Verificare le CV chorus da pagina 6:
   - `LEFT CHORUS CV`;
   - `RIGHT CHORUS CV`.

## Interpretazione rapida
| Misura | Interpretazione probabile |
| --- | --- |
| Segnale presente a ingresso `U916` ma assente a pin 7/10 | `U916`, alimentazione, bias, zoccolo o rete esterna |
| Piu' `NE571` sostituiti senza cambiamento | Sospetto su zoccolo, alimentazione, bias, rete esterna o ricambi fake |
| Ronzio gia' prima di `U916` | BBD, clock, filtro post-BBD o rail |
| Ronzio assente prima ma presente dopo `U916` | `U916` o rete esterna/bias |
| Segnale assente gia' a ingresso `U916` | Cercare prima: BBD, clock, filtri, `U903` |
| Ronzio solo dopo `U918 4007` | Switch/controllo chorus ON/routing |
| Ronzio su entrambi i canali | Rail, clock control comune o disturbo comune |
| Ronzio su un solo canale | Ramo left/right specifico: BBD, filtro, `U916` half, switch |

## Componenti da controllare attorno a U916
Left:
- ingresso: `C957 .22`, rete `R979/R980/R997`
- uscita: `U916` pin 7 -> `C911 1.0`
- rete timing/bias: `C989 220pF`, `C979 1.0`, `R981 2.2M`

Right:
- ingresso: `C954 .22`, rete `R978/R973/R995`
- uscita: `U916` pin 10 -> `C966 1.0`
- rete timing/bias: `C974 220pF`, `C975 1.0`, `R972 2.2M`

Da verificare sullo schema/board reale prima di sostituire: l'OCR del manuale e'
imperfetto, l'immagine dello schema e la serigrafia vanno considerate fonte
primaria.

## Conclusione operativa
Il bypass di `U916` e' una prova diagnostica utile per far passare il wet signal
e restringere il guasto, ma non e' una riparazione definitiva: senza `U916` il
chorus non lavora come previsto dal service manual.

Con piu' `NE571` gia' provati senza risultato, non conviene continuare a
cambiare integrati. La priorita' e' misurare `U916` pin-per-pin con integrato
montato e verificare zoccolo, alimentazione, bias, componenti esterni, piste e
carico in uscita. Solo dopo va inseguito il ronzio acuto residuo come possibile
problema separato di clock/filtro/BBD.

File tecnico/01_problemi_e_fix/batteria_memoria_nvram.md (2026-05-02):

# Batteria memoria, SRAM e mod senza batteria

## Risposta breve

`ELD5530` e batteria sono due cose separate.

- `ELD5530` sostituisce i `CEM5530` dello sample & hold/CV.
- La batteria mantiene alimentate le SRAM patch quando il Prophet VS e' spento.
- Montare `ELD5530` non elimina la necessita' della batteria.
- La batteria non serve piu solo se si sostituiscono le SRAM originali con moduli non volatili compatibili.

## Cosa dice la mod Synthelectro

Nel post Synthelectro del 4 luglio 2015, la modifica "no more battery" riguarda la memoria programmi:

- rimuove le due SRAM originali alimentate a batteria;
- rimuove la batteria interna;
- installa due socket/supporti per le nuove SRAM non volatili;
- usa memorie da `32 Kbytes` al posto delle SRAM originali da `8 Kbytes`;
- permette quattro banchi, circa `400` programmi;
- nello stesso Prophet erano presenti anche due `ELD5530`, ma questa e' un'altra modifica.

Quindi il post descrive due upgrade sullo stesso strumento:

1. mod memoria non volatile: elimina la batteria;
2. mod `ELD5530`: sostituisce i `CEM5530`.

Fonte: `https://synthelectro-fr.blogspot.com/2015/07/how-to-upgrade-programm-memory-of.html`

## Cosa fare sul Prophet VS

Se la macchina ha ancora le SRAM originali:

- la batteria serve ancora;
- prima di sostituirla, salvare/dumpare le patch via SysEx se possibile;
- controllare polarita', tensione e segni di perdita/corrosione;
- sostituire la batteria solo con componente corretto e montato da tecnico.

Se si fa la mod SRAM non volatile:

- la batteria puo' essere rimossa;
- le patch vanno ricaricate dopo l'intervento;
- va verificata la protezione contro scritture spurie all'accensione/spegnimento;
- non basta mettere una qualunque SRAM piu grande: serve un adattamento elettrico/logico corretto.

## Batteria Synth-Parts

Link utile se si mantiene la memoria originale a batteria:

- Synth-Parts `Battery 2/3 Solder pins`, Varta `BAVA2-3AHB3`, `3 V`, `1200 mAh`, diametro `17 mm`: `https://www.synth-parts.com/en/products/battery/5181/battery-2/3-solder-pins`

Decisione ordine, aggiornata al 2026-05-02:

- si: ordinarne `1` se il Prophet VS ha ancora le SRAM originali alimentate a batteria;
- no/non ancora: non serve se il tecnico fa subito una vera mod SRAM non volatile/NVRAM;
- i moduli `Straylight X5530` trovati non cambiano questa decisione, perche sostituiscono i `CEM5530` e non la memoria patch;
- la pagina Synth-Parts indica `Actual stock: 4 pcs.`, prezzo `14.28 EUR`, spedizione EU circa `4-14` giorni e attenzione a polarita'/saldatura.

Nota: la pagina Synth-Parts avvisa di controllare la polarita' e che la batteria e' saldata alla scheda. Quindi non va montata "al volo": serve dissaldatura pulita, controllo danni da perdita e orientamento corretto.

## Nota per diagnosi

La batteria scarica o in perdita puo' causare perdita/corruzione patch e danni fisici alla PCB, ma non spiega direttamente il case caldo dei regolatori o il calore dei `CEM5530`.

Tenere separati questi tre piani:

- memoria patch/batteria/SRAM;
- `CEM5530` o `ELD5530` nello sample & hold/CV;
- alimentazione/regolatori `U301/U302/U303`.

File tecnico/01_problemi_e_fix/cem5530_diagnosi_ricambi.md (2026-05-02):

# CEM5530: diagnosi, ricambi e dissipazione

## Ruolo nel Prophet VS

Il Prophet VS usa due `CEM5530` nel blocco sample & hold/CV:

- `U449`: CV legate a `VCA`, `VCF`, `PAN` e altre uscite chorus/final CV;
- `U425`: area `LEV` e altre CV di controllo.

La pagina `pvs_service` 6 e il datasheet `5530.pdf` sono le sorgenti principali. Il `CEM5530` e' un sample & hold multiplexato a 30 canali: quando un'uscita droopa, resta bloccata, e' rumorosa o viene aggiornata male, il problema puo' sembrare audio ma nascere da una CV errata.

## Sintomi compatibili

Possibili sintomi di `CEM5530`, rail o circuito S&H:

- VCA che non chiude e lascia passare audio/bleed;
- pan o livello instabile;
- modulazione percepita anche quando non dovrebbe esserci;
- filtro/VCA con comportamento diverso tra patch o voci;
- chorus/output anomalo se la CV relativa non arriva corretta;
- difetto che compare o peggiora a caldo.

Nota: i forum riportano che i `CEM5530` possono morire in modo parziale/graduale, non sempre "tutto o niente". Quindi un solo gruppo di funzioni puo' essere guasto mentre altro sembra normale.

## Cosa verificare prima di sostituire

Prima di condannare il chip:

1. misurare rail locali `+8V`, `+5.6V`, `-5V`, `+12V`, `-12V` e ripple;
2. controllare `DAC`, `INH`, address/timing e riferimenti;
3. osservare uscite `VCA/VCF/PAN/LEV` con strumento adeguato;
4. ispezionare saldature, socket, piste e jumper intorno a `U449/U425`;
5. controllare connettori tra board: i forum segnalano anche interconnect/pin e piste rotte come fonte di falsi guasti.

Se il tecnico decide di estrarre i chip, evitare molte inserzioni/rimozioni. I socket originali possono essere fragili; se si interviene, valutare socket torniti/tulip di qualita'.

## Ricambi e cloni

Opzioni da considerare, in ordine pratico. Il Prophet VS usa due moduli/chip: uno per `U449` e uno per `U425`.

### Link operativi

1. Straylight Engineering `CEM5530 replacement modules`: questa e' la pista piu chiara per comprare oggi un ricambio moderno. Nel post "What a year." Straylight scriveva che il clone `CEM5530` era ancora disponibile a `75 USD` ciascuno piu spedizione; nel post "Update Jan 2023" riportava ancora `CEM5530 replacement modules` disponibili. Prima di ordinare va comunque confermata disponibilita' attuale:
   - contact form Straylight: `https://www.straylightengineering.com/contact/`
   - disponibilita'/prezzo storico 2020: `https://www.straylightengineering.com/what-a-year/`
   - disponibilita' citata nel 2023: `https://www.straylightengineering.com/update-jan-2023/`
   - vecchia pagina progetto/design 5530: `https://www.straylightengineering.com/5530-clone-boards-available-new-design/`
   - nota sui due moduli gia trovati: `../07_autocostruzione_ricambi/straylight_x5530_moduli_trovati.md`
2. `ELD5530` di Eric Penot / Synthelectro: clone storico specifico per Prophet VS e Studio 440. Non ho trovato una pagina carrello o "buy now" attiva; questi sono quindi link di informazione/contatto col produttore originale, non un negozio automatico:
   - permalink del post Synthelectro 2014: `https://synthelectro-fr.blogspot.com/2014/06/cem5530-pour-prophet-vs-studio-440.html`
   - pagina archivio Synthelectro con il post "Remplacement du CEM5530 pour Prophet VS & Studio 440.", lunedi' 2 giugno 2014: `https://synthelectro-fr.blogspot.com/2014/06/`
   - post 2015 con Prophet VS aggiornato e due `ELD5530`: `https://synthelectro-fr.blogspot.com/2015/07/how-to-upgrade-programm-memory-of.html`
   - email pubblicata da Synthelectro nei commenti del post 2015 per richieste: `synthelectro@netcourrier.com`
3. `CEM5530` originale NOS o pull: comprare solo da fonte affidabile, testato, evitando componenti recuperati non garantiti. Non e' un clone moderno e non risolve il problema affidabilita' di base del componente vecchio.
4. Vecchie board Wine Country / NMC / Cantos / SSM2300: esistono come storia di riparazione, ma non vanno considerate disponibili senza contatto diretto.
5. Vecchie board basate su `PD508/CEM5508`: funzionano come concetto, ma anche quei chip sono rari e vecchi.

Nota importante: non ho trovato un prodotto `CEM5530` su Electric Druid. La sigla corretta da chiedere/cercare e' `ELD5530`, legata a Synthelectro/Eric Penot.

Nota batteria: i due `ELD5530` citati nel post Synthelectro 2015 non eliminano la batteria memoria. La batteria sparisce solo con la modifica separata alle SRAM non volatili; vedere `batteria_memoria_nvram.md`.

### Cosa sono davvero gli `ELD5530`

Gli `ELD5530` non sono `CEM5530` originali modificati. Sono moduli/adattatori sostitutivi che usano almeno un IC sample & hold commerciale moderno al posto del Curtis originale.

La fonte primaria Synthelectro 2014 corregge il quadro:

- la versione 2 del ricambio e' basata su un IC Maxim Integrated, ma la sigla dell'IC non viene pubblicata nella pagina;
- la prima versione era gia' una scheda che si inseriva al posto del `CEM5530`, ma non gestiva tutte le alimentazioni e richiedeva due piccole modifiche sulla board del Prophet VS o dello Studio 440;
- la versione 2 integra la generazione/gestione delle tensioni necessarie, quindi viene presentata come sostituzione plug-in del `CEM5530` guasto;
- nel Prophet VS i due `CEM5530` sono `U449` e `U425`; nello Studio 440 ce n'e' uno;
- Synthelectro segnala anche che i socket originali Prophet VS sono double-lyre, non tulip, e possono rompersi a livello saldature.

La fonte forum cita esplicitamente una clonazione del `CEM5530` con un Maxim `MAX5167`; questo resta quindi una deduzione/indizio esterno, non una sigla confermata da Synthelectro. Il datasheet Maxim/Analog Devices descrive il `MAX5167` come sample & hold a `32` canali con ingresso multiplexato, quindi e' molto vicino al ruolo del `CEM5530` nel Prophet VS, che usa `30` canali per chip.

Tradotto per il tecnico:

- non si prende un `MAX5167` e lo si infila direttamente al posto del `CEM5530`;
- serve una schedina che adatti pinout, alimentazioni, segnali di controllo, output usati/non usati e orientamento;
- se si trova un vero `ELD5530 V2`, l'idea e' rimuovere il `CEM5530` difettoso e inserire il modulo, confermando pin 1 e altezza prima di accendere;
- se il tecnico ha schema, PCB/Gerber, BOM e IC corretti puo' teoricamente costruirli;
- senza file di progetto conviene comprare moduli gia' fatti o chiedere a Synthelectro/Straylight, perche' rifarli diventa un lavoro di progettazione e test, non una normale riparazione.

Per la ricostruzione da zero, vedere anche il dossier dedicato: `../07_autocostruzione_ricambi/cem5530_clone_build_dossier.md`.

Aggiornamento: sono stati trovati due moduli `Straylight Engineering X5530` con quattro `SMP18` per scheda. Sembrano due cloni/ricambi `CEM5530` gia pronti; prima di comprare altro farli verificare al tecnico. Vedere `../07_autocostruzione_ricambi/straylight_x5530_moduli_trovati.md`.

Per contatti, priorita' e email pronte da mandare, vedere `../07_autocostruzione_ricambi/contatti_acquisto_eld5530_cem5530.md`.

Messaggio pratico da mandare a Straylight:

```text
Hello,
I need two CEM5530 replacement modules for a Sequential Circuits Prophet VS,
positions U449 and U425. Can you confirm current availability, price,
shipping to Italy, installation notes, pin-1 orientation, height clearance,
and whether replacing the original sockets with quality turned-pin/tulip
sockets is recommended?

Thank you.
```

Messaggio pratico da mandare a Synthelectro per `ELD5530`:

```text
Hello,
I own a Sequential Circuits Prophet VS and I am looking for two ELD5530
replacement modules for the original CEM5530 chips, positions U449 and U425.
Are ELD5530 modules still available? If yes, can you confirm price, shipping
to Italy, installation notes, pin-1 orientation, height clearance, and whether
socket replacement is recommended?

Thank you.
```

## Dissipatori e temperatura

Nei forum sul Prophet VS ricorre lo stesso consiglio: i `CEM5530` scaldano e conviene aggiungere un piccolo dissipatore sui chip originali.

Nota importante: questa sezione riguarda i `CEM5530` originali in package lungo `40` pin. Non applicare automaticamente gli stessi dissipatori ai moduli clone `Straylight X5530`: quei moduli usano quattro `SMP18` SOIC distribuiti sulla scheda e vanno prima misurati/verificati. Vedere `../07_autocostruzione_ricambi/straylight_x5530_moduli_trovati.md`.

Il datasheet/pinout mostra un package a `40` pin. Nel Prophet VS servono due dissipatori identici, uno per `U449` e uno per `U425`.

Misura target consigliata:

- base circa `50-51 mm` lunga, `13-14 mm` larga, altezza circa `5 mm`;
- non superare `15 mm` di larghezza senza prova a secco sul chip reale;
- evitare dissipatori alti oltre `5 mm` se non si e' verificata la chiusura del case;
- se il dissipatore e' leggermente piu corto del corpo del `CEM5530`, va bene: deve scaricare calore dal corpo centrale senza arrivare ai pin.

Ricambi sensati:

- Aavid/Boyd `508700B00000G`: `50.8 x 13.46 x 4.83 mm`, alluminio nero, per `40-DIP`, adhesive/tape non incluso. E' il formato piu sicuro come larghezza per non avvicinarsi ai pin: `https://www.digikey.com/en/products/detail/boyd-laconia-llc/508700B00000G/373763`
- Mouser per lo stesso `508700B00000G`: `https://www.mouser.com/ProductDetail/Aavid/508700B00000G?qs=2v7q0MSBcBOClotXj3TAvQ%3D%3D`
- Fischer Elektronik `ICK 40 B`: `51 x 19 x 4.8 mm`, per DIP, disponibile tramite Farnell/element14; usarlo solo se una prova a secco conferma che i `19 mm` di larghezza non toccano pin, socket o componenti vicini: `https://es.farnell.com/fischer-elektronik/ick-40-b/disipador-de-calor-dip-pegado/dp/4620926`

Adesivo/pad termico se non integrato:

- 3M `8810-0.5-5`: tape termico biadesivo `12.7 mm` largo, `0.25 mm` spesso, da tagliare a circa `50 mm` per il dissipatore Aavid/Boyd: `https://www.digikey.com/en/products/detail/3m-tc/8810-0-5-5/2649860`
- 3M `8810-0.75-5`: stessa serie, `19.05 mm` larga, adatta come misura al Fischer `ICK 40 B` se viene usato quel dissipatore: `https://www.digikey.com/en/products/detail/3m-tc/8810-0-75-5/2649863`
- 3M `8810SQ-35(100)`: pad `35 x 35 mm`, comodo se si vuole tagliare materiale in piccoli pezzi; per coprire un dissipatore lungo servono piu pezzi tagliati puliti: `https://www.digikey.com/en/products/detail/3m-tc/8810SQ-35-100/3529589`

Nota Amazon, ricerca del 2026-05-02: non sono stati aggiunti link Amazon perche non sono emersi risultati affidabili per `508700B00000G`, `ICK 40 B`, `3M 8810-0.5-5` o `3M 8810-0.75-5`. I risultati generici tipo dissipatori BGA/Raspberry o nastri VHB/montaggio non vanno considerati equivalenti se non riportano chiaramente dimensioni, uso termico, biadesivo termico ed eventuale isolamento elettrico.

Accorgimenti sensati:

- usare un dissipatore adesivo per IC/DIP, o piccolo dissipatore alettato a basso profilo;
- preferire adesivo/pad termico elettricamente isolante;
- non far toccare dissipatore e pin;
- verificare altezza e chiusura del case;
- misurare temperatura prima/dopo, non andare a sensazione;
- evitare ventole o masse pesanti appese al chip.
- se il dissipatore ha gia' pad adesivo termico integrato, non aggiungere un secondo strato;
- non usare pasta termica semplice senza fissaggio meccanico: il dissipatore potrebbe staccarsi;
- evitare adesivi caricati argento o conduttivi; se si usa epoxy termico permanente, preferire un prodotto elettricamente isolante e accettare che la rimozione sara' difficile.

Forum e vecchie note parlano anche di dissipatori neri con alette tipo vecchi Pentium-I senza ventola. Trattarlo come suggerimento di epoca/forum, non come parte obbligatoria: l'importante e' ridurre calore senza stress meccanico o corto.

## Separazione dal case caldo

Questa e' una nota termica diversa dal problema del case caldo.

- I tre TO-220 fissati al case/dissipatore sono regolatori lineari: `U301 7805`, `U302 7812`, `U303 7912`.
- I `CEM5530` sono IC sample & hold `U449/U425`; possono scaldare localmente, ma non sono "uno dei tre transistor" sul retro.
- Il dissipatore sui `CEM5530` serve a ridurre lo stress termico del chip, non a risolvere il case rovente.

Il collegamento possibile tra i due problemi e' elettrico, non meccanico/termico diretto: se un regolatore scalda perche il rail ha carico anomalo, ripple o tensione sbagliata, quel rail puo' anche disturbare l'area S&H/CV. Viceversa, un `CEM5530` guasto in modo pesante potrebbe caricare un rail, ma non e' l'ipotesi da assumere senza misure.

La pagina `5530` 3 indica che la tensione tra `VDD` e `VSS` non deve superare 16 V e che le alimentazioni influenzano lo swing input/output. Quindi:

- non abbassare o modificare rail "per far scaldare meno" senza progetto e misure;
- prima verificare che i rail siano nei valori previsti e con ripple basso;
- se un regolatore scalda troppo, cercare carico a valle, condensatore in perdita, ripple o dissipazione errata;
- se si aggiungono dissipatori ai `CEM5530`, farlo come misura conservativa per quei chip, non come sostituto della diagnosi sul regolatore caldo.

## Supporto meccanico

Un thread Gearspace segnala piste rotte sotto la board dei `5530` dovute a flessione. Per il modello keyboard:

- evitare stand che sostengono solo i lati se il fondo flette;
- usare supporto largo/continuo o flightcase che distribuisca il peso;
- quando la macchina e' aperta, controllare piste e saldature sul lato inferiore della zona `U449/U425`.

## Lista pratica

Da comprare o cercare:

- 2 dissipatori bassi per IC `CEM5530` originali, uno per `U449` e uno per `U425`;
- 2 pezzi di pad/tape termico tagliati a misura, solo se i dissipatori non hanno adesivo integrato;
- 2 ricambi `CEM5530` clone, se il budget lo permette e si vuole una riserva reale;
- socket torniti/tulip di qualita' se si dissaldano i chip o i socket originali sono fragili.

Da non fare:

- non sostituire `CEM5530` solo perche il sintomo e' strano;
- non comprare cloni senza confermare altezza, pin 1, compatibilita' Prophet VS e istruzioni di installazione;
- non usare dissipatori conduttivi o pesanti che possano cortocircuitare o flettere il chip;
- non modificare i rail senza schema, datasheet e misure.

## Fonti esterne consultate

- Gearspace, Prophet VS reliability: `https://gearspace.com/board/electronic-music-instruments-and-electronic-music-production/724391-prophet-vs-reliability.html`
- Gearspace, pagina 2 dello stesso thread: `https://gearspace.com/board/electronic-music-instruments-and-electronic-music-production/724391-prophet-vs-reliability-2.html`
- Gearspace, heatsink CEM5530: `https://gearspace.com/board/geekzone/1064015-where-can-i-find-heatsink-cem5530-chips.html`
- Analog Devices / Maxim `MAX5167L`: `https://www.analog.com/en/products/max5167l.html`
- Analog Devices / Maxim `MAX5167` datasheet PDF: `https://www.analog.com/media/en/technical-documentation/data-sheets/MAX5167-MAX5167N.pdf`
- DigiKey, Aavid/Boyd `508700B00000G`: `https://www.digikey.com/en/products/detail/boyd-laconia-llc/508700B00000G/373763`
- Mouser, Aavid `508700B00000G`: `https://www.mouser.com/ProductDetail/Aavid/508700B00000G?qs=2v7q0MSBcBOClotXj3TAvQ%3D%3D`
- Farnell, Fischer Elektronik `ICK 40 B`: `https://es.farnell.com/fischer-elektronik/ick-40-b/disipador-de-calor-dip-pegado/dp/4620926`
- DigiKey, 3M `8810-0.5-5`: `https://www.digikey.com/en/products/detail/3m-tc/8810-0-5-5/2649860`
- DigiKey, 3M `8810-0.75-5`: `https://www.digikey.com/en/products/detail/3m-tc/8810-0-75-5/2649863`
- Straylight Engineering, contact form: `https://www.straylightengineering.com/contact/`
- Straylight Engineering, prezzo storico `CEM5530` clone 2020: `https://www.straylightengineering.com/what-a-year/`
- Straylight Engineering, update Jan 2023: `https://www.straylightengineering.com/update-jan-2023/`
- Straylight Engineering, vecchia pagina clone 5530: `https://www.straylightengineering.com/5530-clone-boards-available-new-design/`
- Synthelectro ELD5530 / CEM5530 replacement: `https://synthelectro-fr.blogspot.com/2014/06/cem5530-pour-prophet-vs-studio-440.html`
- Synthelectro archivio giugno 2014 con lo stesso post: `https://synthelectro-fr.blogspot.com/2014/06/`
- Synthelectro Prophet VS memory upgrade con due `ELD5530`: `https://synthelectro-fr.blogspot.com/2015/07/how-to-upgrade-programm-memory-of.html`

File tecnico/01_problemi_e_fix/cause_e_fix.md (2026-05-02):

# Cause possibili e fix consigliati

Questa e' la pagina da leggere per prima. Non e' una diagnosi certa: e' una lista ordinata di ipotesi, prove e interventi ragionevoli da far fare a un tecnico.

## Problema 1: audio/modulazione passa con volume a zero

| Priorita | Possibile causa | Come verificarla | Fix possibile |
| --- | --- | --- | --- |
| Alta | Segnale che rientra dopo il controllo volume | Seguire il segnale prima/dopo volume e confrontare left/right, dry/chorus/output | Riparare punto di accoppiamento, jack/connettore, saldatura o componente nello stadio output |
| Alta | VCA che non chiude per CV errata | Misurare CV `VCA` a volume zero e durante il bleed | Correggere la causa della CV errata: S&H, riferimento, rail, saldatura, componente nel percorso VCA |
| Alta | S&H/CEM5530 con droop, ripple, guasto parziale o timing errato | Osservare uscite `VCA/VCF/PAN/LEV`, `INH`, DAC/riferimenti e rail locali; vedi `cem5530_diagnosi_ricambi.md` | Riparare rail locali, timing/logica o componente S&H solo dopo prova strumentale; valutare clone/dissipatore sul chip se confermato |
| Media | Chorus/output/op amp che lascia passare o distorce | Confrontare uscita dry/chorus, canali left/right, DC offset e saturazione op amp | Riparare op amp, condensatori o reti R/C dello stadio output/chorus se misurati difettosi |
| Media | Rail analogici/digitali rumorosi o bassi | Misurare `+5VD`, `+12V`, `-12V`, `+8V`, `+5.6V`, `-5V` e ripple | Riparare alimentazione, condensatori, diodi/rectifier, ground o carico a valle |
| Media | Pressure/aftertouch che contamina CV | Misurare `PRESSURE/SENSOR`, `TP301/TP302`, valori ECR e risposta aftertouch | Correggere rete pressure, saldature, connettori o modifiche ECR fatte male |
| Media | Riparazione precedente / ECR sbagliata | Ispezione di jumper, tagli piste, pad sollevati, valori resistenze | Rifare la riparazione in modo pulito seguendo schema e board reale |
| Media | Jack output/footswitch rotti o normalizzazione ossidata | I 4 jack posteriori hanno plastica rotta; verificare tip/ring/sleeve/switch e footprint | Sostituire tutti e 4 i jack; vedi `jack_sostituzione.md` e `pannello_posteriore_ricambi.md` |
| Media | Porta/selettore `MIDI OUT/THRU` rugginoso | Verificare se e' la presa DIN, un piccolo slide switch `OUT/THRU`, o entrambi; test MIDI OUT e THRU separati | Pulire solo se recuperabile; se ruggine forte, sostituire presa DIN/switch con stesso footprint; vedi `pannello_posteriore_ricambi.md` |
| Bassa/media | Batteria memoria scarica, in perdita o SRAM patch corrotte | Salvare/dumpare patch via SysEx, verificare tensione/polarita' batteria, corrosione e tipo SRAM montate; vedi `batteria_memoria_nvram.md` | Se SRAM originali: sostituire batteria corretta. Se mod SRAM non volatile: batteria non necessaria. Non confondere con `ELD5530` |

Prima prova pratica: capire se il bleed e' gia' presente prima del volume oppure nasce dopo. Questo decide se partire da VCA/S&H o da output/chorus.

## Problema 2: case caldo / regolatore che scalda troppo

I tre TO-220 nella foto `../foto/IMG_5543.jpg` sono regolatori:

- sinistra: `U301 7805`, rail `+5VD`
- centro: `U302 7812`, rail `+12V`
- destra: `U303 7912`, rail `-12V`

| Priorita | Possibile causa | Come verificarla | Fix possibile |
| --- | --- | --- | --- |
| Alta | Carico eccessivo a valle del rail caldo | Identificare quale regolatore scalda, misurare corrente/carico e cercare IC o condensatore caldo | Riparare o sostituire il componente a valle che assorbe troppo |
| Alta | Condensatore in perdita/corto sul rail | Misurare ripple, resistenza a freddo, temperatura dei condensatori vicini | Sostituire solo i condensatori difettosi o sospetti con evidenza |
| Alta | Caduta Vin-Vout troppo alta sul regolatore | Misurare ingresso, uscita e temperatura del regolatore | Correggere causa a monte o dissipazione; non basta montare un regolatore piu grosso |
| Media | Rectifier/filtro a monte difettoso | Misurare ripple ingresso regolatore e controllare diodi/ponte/filtro | Riparare rettifica/filtro se fuori norma |
| Media | Montaggio termico errato | Controllare vite, isolamento, mica/rondella, pasta termica e contatto col case | Rimontare correttamente il regolatore sul dissipatore/case |
| Media | Parte sostituita non equivalente o montata male | Verificare pinout, isolamento tab, saldature e riferimento esatto | Correggere componente/montaggio, poi rimisurare rail e temperatura |
| Media | Ground o riparazione precedente difettosa | Controllare continuita' `AGND/DGND`, pad e jumper nell'area alimentazione | Rifare saldature, piste o jumper solo dove misurato difettoso |

Nota importante: il regolatore caldo e' gia' stato sostituito con uno piu capiente. Quindi il fix non e' "metterne uno ancora piu grande" finche non si misura cosa lo sta facendo dissipare.

Nota separazione problemi: il calore dei `CEM5530` e il case caldo nella zona `U301/U302/U303` sono problemi termici distinti. Possono essere collegati solo se una misura mostra rail disturbato o carico anomalo comune.

## Ordine di lavoro consigliato

1. Ispezione visiva a strumento spento: regolatori, condensatori, connettori, zone ECR e output.
2. Identificare quale regolatore scalda: `U301`, `U302` o `U303`.
3. Misurare rail, ripple, Vin/Vout e temperatura prima di toccare IC audio o S&H.
4. Se i rail sono sani, seguire il bleed: volume -> VCA -> S&H/CV -> output/chorus.
5. Se un rail e' rumoroso o caricato, risolvere prima alimentazione/carico a valle.
6. Evitare recap o sostituzione IC a tappeto senza misura.

## File da aprire subito

- `technician_briefing_volume_zero_bleed.md`
- `quick_navigation_map.md`
- `cem5530_diagnosi_ricambi.md`
- `batteria_memoria_nvram.md`
- `jack_sostituzione.md`
- `pannello_posteriore_ricambi.md`
- `../02_checklist_misure/visual_inspection_checklist.md`
- `../02_checklist_misure/safe_measurement_plan.md`

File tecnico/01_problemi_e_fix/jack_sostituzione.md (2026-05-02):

# Jack posteriori: sostituzione

## Quanti sono

Sul Prophet VS i jack 1/4" posteriori da considerare sono 4:

- 2 jack audio output: left/right o left/phones/right-mono secondo cablaggio e pannello reale
- 2 jack footswitch: `Second Release Footswitch` e `Auxiliary Footswitch`

La pagina `pvs_service` 4 mostra chiaramente i due footswitch (`J301` e `J302`). Le pagine `pvs_service` 11/12 mostrano la sezione output/chorus con i connettori dell'area audio (`J901/J902/P901` nello schema/board).

## Sono tutti uguali?

Meccanicamente potrebbero essere della stessa famiglia di jack PCB, ma elettricamente non vanno trattati come identici:

- gli output audio portano segnale audio e possono usare contatti normalizzati/switch;
- i footswitch leggono contatti di comando e possono usare tip/sleeve o contatti switch in modo diverso;
- un jack stereo/switch puo' essere usato su circuiti mono se la PCB e' progettata cosi', ma non bisogna dedurlo dal solo fatto che il segnale e' mono.

Quindi: confrontare sempre pin, footprint, altezza, ghiera, contatti switch e continuita' del jack originale prima di dissaldare.

## Il pezzo Synth-Parts linkato

Il pezzo linkato e' un buon candidato, non una garanzia assoluta senza confronto fisico:

- Jalco `YKB21-5078`
- 1/4" / 6.3 mm PCB
- stereo con switch
- filetto `M12x1`
- equivalenti dichiarati: `YKB21-5078`, `HLJ-2305`, `HTJ-064-16D`
- venduto nella categoria Prophet VS da Synth-Parts

Link: `https://www.synth-parts.com/en/products/connectors-and-cable/14-phone-jack/5460/ykb21-5078-phone-jack-1/4-6.3-mm-for-printed-circuits-stereo`

## Stato attuale

Aggiornamento: la plastica dei jack posteriori e' rotta. In questo caso non ha piu senso considerarli solo "da testare": vanno sostituiti tutti e 4, sempre verificando footprint, altezza, contatti e orientamento prima di ordinare o saldare.

Foto locali aggiunte:

- `../foto/jack_pcb_01.JPG`
- `../foto/jack_pcb_02.JPG`

Le foto confermano plastiche rotte e jack PCB fissati alla board/pannello. Non permettono pero' da sole di dichiarare stereo e mono identici: serve confronto lato saldature, conteggio pin e test continuita'.

## Link Synth-Parts per jack mono

Se i due jack footswitch risultano davvero mono, i candidati Synth-Parts sono:

1. Jalco `YKB21-5076`, mono con switch, PCB, filetto `M12x1`, equivalente dichiarato `HLJ-2305-01-3030`:
   - `https://www.synth-parts.com/en/products/connectors-and-cable/14-phone-jack/5475/ykb21-5076-phone-jack-1/4-6.3-mm-pcb-mono`
2. Jalco `YKB21-5012`, mono con switch, PCB, filetto `M12x1`, equivalenti dichiarati `HLJ 4306` / `HLJ 4306-01-3000`:
   - `https://www.synth-parts.com/en/products/connectors-and-cable/14-phone-jack/5461/ykb21-5012-phone-jack-1/4-6.3-mm-for-printed-circuits-mono`

Priorita' pratica: confrontare prima `YKB21-5076`, perche resta nella stessa famiglia Jalco/HLJ vicina al ricambio stereo gia individuato. `YKB21-5012` e' un'alternativa da misurare, non da ordinare alla cieca.

Nota importante: se la PCB originale usa lo stesso footprint stereo anche per funzioni mono, puo' essere piu sicuro montare lo stesso `YKB21-5078` su tutti e 4 i posti e lasciare non usati ring/switch non richiesti. Decidere solo dopo confronto dei fori e continuita' del jack originale.

## Prima di sostituirli

1. Ispezione: jack crepato, ghiera lenta, saldature rotte, piste sollevate, ossido.
2. Foto lato componenti e lato saldature prima di dissaldare.
3. Test continuita' di un jack originale con plug inserito e non inserito: tip, ring, sleeve e contatti switch.
4. Confronto con il ricambio: pin, passo, altezza, filetto, dado, contatti switch.
5. Sostituzione dei 4 jack rotti, evitando di stressare piste e fori metallizzati.

Se il problema principale e' bleed a volume zero, i jack sono una possibile causa solo se il segnale cambia toccando/muovendo cavi o se le normalizzazioni risultano ossidate. Se il difetto resta identico su tutte le uscite, prima controllare VCA/S&H/output/rail.

## Alternative

Alternative sensate:

- stesso Jalco `YKB21-5078`;
- equivalenti indicati dal venditore: `HLJ-2305`, `HTJ-064-16D`;
- per jack mono confermati: Jalco `YKB21-5076` oppure `YKB21-5012`, solo se footprint e switch combaciano;
- altra fonte dello stesso identico footprint e stesso schema contatti.

Alternative da evitare salvo necessita':

- jack mono tipo `YKB21-5012` o `YKB21-5076` montati senza verificare pinout e switch;
- jack panel-mount Switchcraft/Neutrik con fili volanti, se la PCB originale e' sana;
- jack "simile" ma con altezza o foratura diversa, perche puo' stressare pannello e piste.

## Acquisto pratico

Se il tecnico conferma che tutti e 4 i footprint originali corrispondono al Jalco `YKB21-5078`, comprare 4 pezzi piu eventuali dadi `M12x1` di ricambio.

Se invece i footswitch sono footprint mono:

- 2 x `YKB21-5078` per i jack stereo/output confermati;
- 2 x `YKB21-5076` o `YKB21-5012` solo dopo confronto footprint/contatti.

Nota collegata: per MIDI, power switch e selettore tensione vedere `pannello_posteriore_ricambi.md`.

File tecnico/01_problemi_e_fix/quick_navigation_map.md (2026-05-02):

# Mappa rapida di navigazione per riparazione Prophet VS

Usare questa mappa come indice pratico. I due sintomi principali, bleed a volume zero e case/regolatore caldo, possono essere collegati da un rail disturbato ma vanno diagnosticati separatamente finche le misure non li uniscono.

## 1. Audio che passa con volume a zero

| PDF sorgente | Pagina | Immagine | Nota | Perche importante | Ispezionare per primo |
| --- | --- | --- | --- | --- | --- |
| `../06_pdf_originali/pvs_service.pdf` | 9 | `../05_pagine_rilevanti/immagini/pvs_service/page_009.png` | `../05_pagine_rilevanti/note/pvs_service/page_009.md` | VCF/VCA/PAN e percorso voce analogico | `VCAIN/VCAOUT`, net `VCA/VCF/PAN`, saldature e R/C vicino a U455-U458 |
| `../06_pdf_originali/pvs_service.pdf` | 11 | `../05_pagine_rilevanti/immagini/pvs_service/page_011.png` | `../05_pagine_rilevanti/note/pvs_service/page_011.md` | Output/chorus left-right | Differenza left/right, op amp output, condensatori C9xx/R9xx |
| `../06_pdf_originali/pvs_service.pdf` | 12 | `../05_pagine_rilevanti/immagini/pvs_service/page_012.png` | `../05_pagine_rilevanti/note/pvs_service/page_012.md` | Output, lowpass 7 kHz, right voice/chorus | TL082, rail `+12V/-12V/+8V`, DC offset o saturazione |

Non concludere automaticamente che il pot volume sia guasto: prima capire se il segnale residuo nasce prima o dopo il controllo volume.

## 2. Contaminazione CV / modulazione

| PDF sorgente | Pagina | Immagine | Nota | Perche importante | Ispezionare per primo |
| --- | --- | --- | --- | --- | --- |
| `../06_pdf_originali/pvs_service.pdf` | 6 | `../05_pagine_rilevanti/immagini/pvs_service/page_006.png` | `../05_pagine_rilevanti/note/pvs_service/page_006.md` | Main analog sample & hold / sensor, CEM5530, DAC e CV `VCA/VCF/PAN/LEV` | `U449/U425`, `U451`, `INH`, `DAC`, rail `+8V/+5.6V/-5V` |
| `../06_pdf_originali/5530.pdf` | 2 | `../05_pagine_rilevanti/immagini/5530/page_002.png` | `../05_pagine_rilevanti/note/5530/page_002.md` | Pinout/diagramma CEM5530, utile anche per dissipatori e orientamento | Package `40` pin, `U449/U425` |
| `../06_pdf_originali/5530.pdf` | 3 | `../05_pagine_rilevanti/immagini/5530/page_003.png` | `../05_pagine_rilevanti/note/5530/page_003.md` | Limiti alimentazione e comportamento uscite CEM5530 | Carichi e capacita' sulle uscite CV, rail CEM5530 |
| `../06_pdf_originali/5530.pdf` | 4 | `../05_pagine_rilevanti/immagini/5530/page_004.png` | `../05_pagine_rilevanti/note/5530/page_004.md` | Timing, inhibit e droop dello sample & hold | Droop, ripple o modulazione sulle uscite hold |

Se la modulazione sembra seguire patch/LFO/envelope, partire da CV e S&H prima di sostituire audio op amp.

## 2b. CEM5530 / cloni / autocostruzione

| Sorgente | Pagina | Immagine | Nota | Perche importante | Ispezionare per primo |
| --- | --- | --- | --- | --- | --- |
| `../07_autocostruzione_ricambi/cem5530_clone_build_dossier.md` | dossier | n/a | `../07_autocostruzione_ricambi/cem5530_clone_build_dossier.md` | Stato reale schemi ELD5530, architetture `MAX5167`, `SSM2300`, `PD508/CEM5508` e test minimi | Non esistono Gerber/BOM pubblici verificati; usare come brief di progettazione |
| `../07_autocostruzione_ricambi/max5167_v2_like_pre_design.md` | progetto preliminare | n/a | `../07_autocostruzione_ricambi/max5167_v2_like_pre_design.md` | Pista `MAX5167` portata a pin mapping, rail locali, vincoli PCB e piano test | Non PCB-ready: verificare timing, carichi e spazio sulla macchina reale |
| `../07_autocostruzione_ricambi/rev_a_max5167_prototipo/README.md` | prototipo Rev A | n/a | `../07_autocostruzione_ricambi/rev_a_max5167_prototipo/README.md` | Schema testuale, netlist CSV, BOM funzionale, vincoli PCB e collaudo per prototipo `MAX5167` | Prototipo non validato: non montare senza test fuori macchina |
| `../06_pdf_originali/5530.pdf` | 2 | `../05_pagine_rilevanti/immagini/5530/page_002.png` | `../05_pagine_rilevanti/note/5530/page_002.md` | Pinout da ricavare manualmente prima di qualsiasi clone | Pin 1, 40 pin, output e rail |
| `../06_pdf_originali/5530.pdf` | 3-4 | `../05_pagine_rilevanti/immagini/5530/page_003.png` | `../05_pagine_rilevanti/note/5530/page_003.md` | Alimentazioni, swing, timing `INH`, droop e acquisition | Rail e timing reali da misurare su `U449/U425` |
| `../06_pdf_originali/component_datasheets/README.md` | link datasheet | n/a | `../06_pdf_originali/component_datasheets/README.md` | Link ufficiali `MAX5167` e `SSM2300` per lavoro offline/manuale | Scaricare datasheet esterni se si progetta una scheda |

## 3. Pressure / aftertouch

| PDF sorgente | Pagina | Immagine | Nota | Perche importante | Ispezionare per primo |
| --- | --- | --- | --- | --- | --- |
| `../06_pdf_originali/pvs_service.pdf` | 4 | `../05_pagine_rilevanti/immagini/pvs_service/page_004.png` | `../05_pagine_rilevanti/note/pvs_service/page_004.md` | Pressure circuit su keyboard/power board | `U310`, `R321`, `R307/R308/R309/R320/R304`, `TP301/TP302` |
| `../06_pdf_originali/pvs_service.pdf` | 6 | `../05_pagine_rilevanti/immagini/pvs_service/page_006.png` | `../05_pagine_rilevanti/note/pvs_service/page_006.md` | Pressure/SENSOR collegato a main analog/S&H | `U459`, `R458`, net `PRESSURE/SENSOR`, connettori `P402/P403` |
| `../06_pdf_originali/sci_prophet_vs_ecr738.pdf` | 2 | `../05_pagine_rilevanti/immagini/sci_prophet_vs_ecr738/page_002.png` | `../05_pagine_rilevanti/note/sci_prophet_vs_ecr738/page_002.md` | ECR738 modifica pressure sensor lato main analog | Valore `R458`, jumper/tagli, saldature nella modifica |
| `../06_pdf_originali/sci_prophet_vs_ecr739.pdf` | 4 | `../05_pagine_rilevanti/immagini/sci_prophet_vs_ecr739/page_004.png` | `../05_pagine_rilevanti/note/sci_prophet_vs_ecr739/page_004.md` | ECR739 pressure/power/reset su keyboard board | Rete `U310` e valori resistenze, `SENSOR/PRESSURE` |

Non assumere che ECR738/ECR739 siano presenti: verificarle fisicamente sulla macchina.

## 3b. Batteria memoria / SRAM / patch

| Sorgente | Pagina | Immagine | Nota | Perche importante | Ispezionare per primo |
| --- | --- | --- | --- | --- | --- |
| `batteria_memoria_nvram.md` | nota locale | n/a | `batteria_memoria_nvram.md` | Chiarisce che `ELD5530` non elimina la batteria: la mod senza batteria e' una modifica separata alle SRAM patch | Stato batteria, polarita', corrosione, backup patch/SysEx e tipo SRAM montate |
| `../06_pdf_originali/pvs_service.pdf` | board CPU/memoria | n/a | `../05_pagine_rilevanti/note/pvs_service/page_003.md` | Memoria programmi e area CPU da verificare se si lavora su SRAM/batteria | Due SRAM originali, ROM vicine, battery backup e piste corrose |
| Synthelectro 2015 | post web | n/a | `https://synthelectro-fr.blogspot.com/2015/07/how-to-upgrade-programm-memory-of.html` | Esempio di mod SRAM non volatile: due SRAM `32 Kbytes`, quattro banchi, batteria rimossa | Non confondere con i due `ELD5530` citati nello stesso post |

Se le SRAM originali sono ancora montate, la batteria serve ancora. Se si monta una vera SRAM non volatile compatibile, la batteria puo' essere rimossa.

## 4. Instabilita alimentazione / rail

| PDF sorgente | Pagina | Immagine | Nota | Perche importante | Ispezionare per primo |
| --- | --- | --- | --- | --- | --- |
| `../06_pdf_originali/pvs_service.pdf` | 4 | `../05_pagine_rilevanti/immagini/pvs_service/page_004.png` | `../05_pagine_rilevanti/note/pvs_service/page_004.md` | Power supply digital/keyboard e reset | `U301 7805`, `U302 7812`, `U303 7912`, `U304 78L05`, `U305 HC132` |
| `../06_pdf_originali/sci_prophet_vs_ecr739.pdf` | 4 | `../05_pagine_rilevanti/immagini/sci_prophet_vs_ecr739/page_004.png` | `../05_pagine_rilevanti/note/sci_prophet_vs_ecr739/page_004.md` | Conferma rail `+5VD/+12V/-12V`, reset e pressure | Ripple, Vin/Vout, `AGND/DGND`, `TP301/TP302` |
| `../06_pdf_originali/pvs_service.pdf` | 6 | `../05_pagine_rilevanti/immagini/pvs_service/page_006.png` | `../05_pagine_rilevanti/note/pvs_service/page_006.md` | Rail analogici locali per S&H/CV | `U401 7905`, `U402 78M05`, `U450 78M08`, `+8V/+5.6V/-5V` |

Misurare rail e ripple prima di interpretare segnali piccoli o sostituire IC rari.

## 5. Case caldo / regolatore che scalda troppo

| Sorgente | Pagina | Immagine | Nota | Perche importante | Ispezionare per primo |
| --- | --- | --- | --- | --- | --- |
| `../foto/IMG_5543.jpg` | foto utente | `../foto/IMG_5543.jpg` | `technician_briefing_volume_zero_bleed.md` | Mostra i tre TO-220 fissati al dissipatore/case | Identificare quale dei tre scalda: sinistra `U301`, centro `U302`, destra `U303` secondo layout |
| `../06_pdf_originali/pvs_service.pdf` | 5 | `../05_pagine_rilevanti/immagini/pvs_service/page_005.png` | `../05_pagine_rilevanti/note/pvs_service/page_005.md` | Designator map fisica della board | Confermare ordine `U301/U302/U303`, condensatori e connettori vicini |
| `../06_pdf_originali/pvs_service.pdf` | 4 | `../05_pagine_rilevanti/immagini/pvs_service/page_004.png` | `../05_pagine_rilevanti/note/pvs_service/page_004.md` | Schema rail dei tre regolatori | `U301 +5VD`, `U302 +12V`, `U303 -12V`, condensatori/diodi/filtro |
| `../06_pdf_originali/sci_prophet_vs_ecr739.pdf` | 4 | `../05_pagine_rilevanti/immagini/sci_prophet_vs_ecr739/page_004.png` | `../05_pagine_rilevanti/note/sci_prophet_vs_ecr739/page_004.md` | Conferma ECR/power supply | Vin/Vout/ripple, carico a valle, isolamento/pasta/vite |

Non concludere automaticamente che il regolatore sia guasto: e' gia' stato sostituito con uno piu capiente, quindi cercare carico eccessivo, condensatore in perdita/corto, caduta Vin-Vout o montaggio termico errato.

## 6. Riparazione precedente / pista sollevata / ECR sbagliata

| PDF sorgente | Pagina | Immagine | Nota | Perche importante | Ispezionare per primo |
| --- | --- | --- | --- | --- | --- |
| `../06_pdf_originali/sci_prophet_vs_ecr738.pdf` | 2 | `../05_pagine_rilevanti/immagini/sci_prophet_vs_ecr738/page_002.png` | `../05_pagine_rilevanti/note/sci_prophet_vs_ecr738/page_002.md` | Modifica pressure sensor lato main analog | `R458`, jumper, tagli piste, flussante, pad sollevati |
| `../06_pdf_originali/sci_prophet_vs_ecr738.pdf` | 3 | `../05_pagine_rilevanti/immagini/sci_prophet_vs_ecr738/page_003.png` | `../05_pagine_rilevanti/note/sci_prophet_vs_ecr738/page_003.md` | Riferimento artwork/layout ECR | Routing fisico e riparazioni non documentate |
| `../06_pdf_originali/sci_prophet_vs_ecr739.pdf` | 4 | `../05_pagine_rilevanti/immagini/sci_prophet_vs_ecr739/page_004.png` | `../05_pagine_rilevanti/note/sci_prophet_vs_ecr739/page_004.md` | ECR pressure/power/reset | Valori resistenze, tagli/jumper, saldature su `U310/U301-U303` |
| `../06_pdf_originali/pvs_service.pdf` | 5 | `../05_pagine_rilevanti/immagini/pvs_service/page_005.png` | `../05_pagine_rilevanti/note/pvs_service/page_005.md` | Layout per confronto fisico | Serigrafia, pad, vias, connettori e componenti attorno ai regolatori |

Prima ispezione a strumento spento; non correggere ECR "a memoria" senza confronto schema/foto/board reale.

## 7. Chorus / output

| PDF sorgente | Pagina | Immagine | Nota | Perche importante | Ispezionare per primo |
| --- | --- | --- | --- | --- | --- |
| `../06_pdf_originali/pvs_service.pdf` | 11 | `../05_pagine_rilevanti/immagini/pvs_service/page_011.png` | `../05_pagine_rilevanti/note/pvs_service/page_011.md` | Chorus/output left-right | `U903/U904/U920`, C9xx/R9xx, differenza canali |
| `../06_pdf_originali/pvs_service.pdf` | 12 | `../05_pagine_rilevanti/immagini/pvs_service/page_012.png` | `../05_pagine_rilevanti/note/pvs_service/page_012.md` | Right voices, chorus e lowpass 7 kHz | `TL082`, `RIGHT CHORUS`, `LEV`, rail `+12V/-12V/+8V` |
| `../06_pdf_originali/pvs_service.pdf` | 6 | `../05_pagine_rilevanti/immagini/pvs_service/page_006.png` | `../05_pagine_rilevanti/note/pvs_service/page_006.md` | CV chorus/final generate da S&H | `LEFT/RIGHT CHORUS CV`, `RIGHT FINAL CV`, CEM5530 |

Se chorus/output cambia il difetto, seguire prima questa sezione; se il difetto e' gia' presente a monte, tornare a VCA/S&H.

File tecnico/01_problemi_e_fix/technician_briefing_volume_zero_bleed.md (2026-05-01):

# Briefing tecnico: Prophet VS audio/modulazione che passa con volume a zero

## 1. Sintomo noto

Il Prophet VS lascia passare qualcosa anche con il volume a zero: puo' essere suono residuo, patch distorta, bleed audio o una modulazione percepibile tipo LFO in alcune patch. Il sintomo non va interpretato subito come "VCA guasto": puo' stare nel percorso audio, nel controllo CV del VCA, nello sample & hold, nell'output/chorus, nei rail o in una riparazione precedente.

Sintomo termico separato:

- Il retro del case diventa molto caldo in corrispondenza dei tre dispositivi TO-220 fissati al dissipatore/case.
- Dalla documentazione questi tre dispositivi non risultano transistor generici ma regolatori lineari della sezione alimentazione digital/keyboard: `U301 7805`, `U302 7812`, `U303 7912`.
- La designator map di `pvs_service` pagina 5 indica l'ordine fisico sinistra->destra come `U301`, `U302`, `U303`; confermare sulla serigrafia reale se visibile.
- Uno di questi regolatori scalda troppo. E' gia' stato sostituito con un componente piu' capiente, quindi il sospetto principale deve spostarsi sul circuito alimentato, sul carico a valle o sulle condizioni di dissipazione, non sul solo regolatore.

## 2. Documenti/pagine sorgente piu rilevanti

- `../foto/IMG_5543.jpg`: foto locale della board `PC2400-3 REV B`, area alimentazione, tre TO-220 su dissipatore/case, connettori e condensatori vicini.
- `../05_pagine_rilevanti/note/pvs_service/page_004.md` ([nota](../05_pagine_rilevanti/note/pvs_service/page_004.md)) e `../05_pagine_rilevanti/immagini/pvs_service/page_004.png` ([immagine](../05_pagine_rilevanti/immagini/pvs_service/page_004.png)): keyboard/power supply, pressure circuit, `U301/U302/U303`, `U304`, `U305`, `U310`, rail `+5VD`, `+12V`, `-12V`, `AGND`, `DGND`.
- `../05_pagine_rilevanti/note/pvs_service/page_005.md` ([nota](../05_pagine_rilevanti/note/pvs_service/page_005.md)) e `../05_pagine_rilevanti/immagini/pvs_service/page_005.png` ([immagine](../05_pagine_rilevanti/immagini/pvs_service/page_005.png)): layout/artwork fisico della board, utile per localizzare i riferimenti e confrontarli con la foto.
- `../05_pagine_rilevanti/note/sci_prophet_vs_ecr739/page_004.md` ([nota](../05_pagine_rilevanti/note/sci_prophet_vs_ecr739/page_004.md)) e `../05_pagine_rilevanti/immagini/sci_prophet_vs_ecr739/page_004.png` ([immagine](../05_pagine_rilevanti/immagini/sci_prophet_vs_ecr739/page_004.png)): ECR739, pressure circuit e power supply; conferma `U301 7805`, `U302 7812`, `U303 7912`, `U304 78L05`, `U305 HC132`, `U310`, `TP301/TP302`.
- `../03_mappe_circuito/power_reset.md` ([mappa](../03_mappe_circuito/power_reset.md)): mappa rail/reset e failure mode associati a rail bassi, ripple e ground.
- `../04_componenti_net_rail/ics.md` ([indice](../04_componenti_net_rail/ics.md)): indice IC/regolatori, inclusi `U301/U302/U303`, CEM5530 `U449/U425`, `U459`, `U310`, `U401/U402/U450`.
- `../04_componenti_net_rail/power_rails.md` ([indice](../04_componenti_net_rail/power_rails.md)): indice rail `+5VD`, `+12V`, `-12V`, `+8V`, `+5.6V`, `-5V`, `AGND/DGND`.
- `../03_mappe_circuito/audio_path.md` ([mappa](../03_mappe_circuito/audio_path.md)): percorso VCF/VCA/PAN/output e possibili cause di bleed.
- `../03_mappe_circuito/sample_hold_cv.md` ([mappa](../03_mappe_circuito/sample_hold_cv.md)): CEM5530, DAC, timing `INH`, uscite CV `VCA/VCF/PAN/LEV`.
- `../03_mappe_circuito/pressure_aftertouch.md` ([mappa](../03_mappe_circuito/pressure_aftertouch.md)): `PRESSURE/SENSOR`, `U310`, `U459`, reti ECR.
- `../03_mappe_circuito/board_revisions_ecr.md` ([mappa](../03_mappe_circuito/board_revisions_ecr.md)): confronto ECR738/ECR739 e checklist di modifica fisica.

## 3. Albero ipotesi ad alto livello

### A. Percorso audio dopo il controllo volume

Perche compatibile: se il bleed e' udibile anche con il potenziometro volume a zero, il segnale potrebbe accoppiarsi o rientrare dopo il punto in cui il volume dovrebbe attenuarlo. Un difetto in uscita, un accoppiamento tra piste, un condensatore in perdita o un jack/connettore possono lasciare passare audio residuo.

Area da ispezionare: pagine `pvs_service` 9, 11, 12; nets `LEFT`, `RIGHT`, `CHORUS`; componenti audio/output `U455/U456/U457/U458`, `U903/U904/U920`, `TL082`, reti R/C C9xx/R9xx.

Supporterebbe: segnale presente dopo il controllo volume anche quando il segnale prima del volume e' correttamente attenuato; differenza tra uscite left/right, cuffie/line, dry/chorus.

Escluderebbe: audio nullo in tutti i punti dopo il volume quando il volume e' a zero, con bleed presente solo come CV/modulazione su stadi precedenti.

Componenti/net/pagine: `LEFT/RIGHT/CHORUS`, `pvs_service` pagine 9, 11, 12, `audio_path.md`, `named_nets.md`.

### B. Problema VCA / control voltage

Perche compatibile: un VCA che non chiude completamente, o una CV VCA fuori livello, puo' lasciare passare voce anche se il controllo utente e' a zero. Se il difetto cambia tra patch, inviluppi o modulazioni, la pista CV diventa piu' sospetta.

Area da ispezionare: CV `VCA` generate dallo S&H, percorso VCF/VCA/PAN su `pvs_service` pagine 6 e 9.

Supporterebbe: CV VCA non raggiunge il livello di chiusura, e il bleed segue envelope/LFO/patch; il segnale audio prima del VCA e' normale ma l'uscita VCA non si chiude.

Escluderebbe: CV VCA corretta e stabile con VCA effettivamente chiuso, ma segnale che appare solo in uno stadio output successivo.

Componenti/net/pagine: `VCA`, `VCF`, `PAN`, `LEV`, CEM5530 `U449/U425`, `pvs_service` pagine 6 e 9.

### C. Leakage/droop/uscita errata dal sample & hold

Perche compatibile: lo S&H genera molte CV, incluse `VCA/VCF/PAN/LEV`, chorus/final CV e altre linee di controllo. Droop, hold step, timing `INH` errato, riferimento/DAC instabile o rail disturbati possono produrre modulazione residua o livelli errati.

Area da ispezionare: main analog sample & hold su `pvs_service` pagina 6; datasheet CEM5530 pagine 1, 3, 4; linee `DAC`, `INH`, `VREF`, rail locali `+8V`, `+5.6V`, `-5V`.

Supporterebbe: CV che deriva, ripple o modulazione sulle uscite hold, livello VCA/LEV non fermo, sintomo che cambia con patch o con modulazioni.

Escluderebbe: tutte le CV interessate sono stabili, prive di ripple e coerenti quando il sintomo e' presente.

Componenti/net/pagine: `U449`, `U425`, `U451`, `U453/U454`, `DAC`, `INH`, `VCA/VCF/PAN/LEV`, `pvs_service` pagina 6, `5530` pagine 1/3/4.

### D. Leakage sezione chorus/output o op amp guasto

Perche compatibile: se il bleed resta in una uscita finale o cambia con chorus/output, puo' derivare da op amp, filtri, condensatori di accoppiamento o routing left/right/chorus.

Area da ispezionare: output/chorus e filtro lowpass su `pvs_service` pagine 11 e 12.

Supporterebbe: differenza netta tra uscita dry e chorus/output, DC offset o saturazione su un op amp, un canale piu' difettoso dell'altro.

Escluderebbe: output/chorus puliti e silenziosi quando viene iniettato o seguito il segnale con volume a zero, mentre il bleed e' gia' presente a monte.

Componenti/net/pagine: `LEFT`, `RIGHT`, `CHORUS`, `LEFT CHORUS`, `RIGHT CHORUS`, `U903/U904/U920`, `TL082`, `pvs_service` pagine 11 e 12.

### E. Problema rail alimentazione / ground / reset

Perche compatibile: rail bassi o con ripple possono creare distorsione, CV sbagliate, refresh digitale instabile, reset incerto, rumore o bleed. Il regolatore caldo rende questa ipotesi importante, soprattutto se il rail alimentato ha carico eccessivo o ripple anomalo.

Area da ispezionare: power supply digital/keyboard su `pvs_service` pagina 4 e `sci_prophet_vs_ecr739` pagina 4; local analog rails su `pvs_service` pagina 6; ground `AGND/DGND`.

Supporterebbe: `+5VD`, `+12V` o `-12V` fuori valore, ripple eccessivo, caduta Vin-Vout anomala sui regolatori, reset instabile, temperatura correlata al carico.

Escluderebbe: rail stabili, ripple basso, assorbimento normale e ground continui mentre il difetto si localizza chiaramente in un solo blocco audio/CV.

Componenti/net/pagine: `U301 7805`, `U302 7812`, `U303 7912`, `U304 78L05`, `U305 HC132`, `U401 7905`, `U402 78M05`, `U450 78M08`, `+5VD`, `+12V`, `-12V`, `+8V`, `+5.6V`, `-5V`, `AGND/DGND`.

### F. Problema CV keyboard/pressure/aftertouch

Perche compatibile: il pressure/aftertouch entra nelle CV e puo' produrre comportamento percepito come modulazione o livello anomalo, specialmente se la taratura o le ECR sono state applicate male.

Area da ispezionare: `PRESSURE/SENSOR`, `U310`, `U459`, `R321`, `R307/R308/R309/R320/R304`, `R458`, `TP301/TP302`.

Supporterebbe: valore `PRESSURE/SENSOR` bloccato, rumoroso, saturato o dipendente dal tocco anche quando non dovrebbe; modifiche ECR incoerenti.

Escluderebbe: pressure sensor stabile e coerente, nessuna correlazione con aftertouch/pressure, CV audio principali corrette.

Componenti/net/pagine: `pvs_service` pagine 4 e 6, `sci_prophet_vs_ecr738` pagina 2, `sci_prophet_vs_ecr739` pagina 4, `pressure_aftertouch.md`.

### G. Riparazione precedente fatta male

Perche compatibile: piste tagliate, jumper, resistenze errate, saldature fredde o ponti di stagno possono creare sia bleed/CV instabili sia carico eccessivo su un rail. Lo strumento e' vecchio e potrebbe essere stato modificato secondo ECR o riparato in modo parziale.

Area da ispezionare: zone ECR738/ECR739, regolatori, connettori, pressure sensor, S&H, output/chorus.

Supporterebbe: flussante scuro, pad sollevati, filo/jumper non documentato, taglio pista non isolato, valore resistenza diverso da schema/ECR, saldatura crepata.

Escluderebbe: board pulita, revision e modifiche coerenti con documenti, continuita' verificata e nessun segno di riparazione nelle aree sospette.

Componenti/net/pagine: `board_revisions_ecr.md`, `pvs_service` pagine 4/5/6, ECR738 pagina 2, ECR739 pagina 4.

### H. Problema normalizzazione connettori/jack

Perche compatibile: connettori e jack ossidati o normalizzazioni difettose possono lasciare passare segnale, introdurre rumore, cambiare canale o alterare riferimenti. L'ossidazione e' plausibile dopo anni di inutilizzo.

Area da ispezionare: connettori tra digital/analog e S&H/output, jack output/aux/footswitch/MIDI, `P402/P403`, `P302/P305`, `P901`, `P3908`, `P4093`.

Supporterebbe: sintomo che cambia muovendo o reinserendo cavi/connettori, differenze tra uscite, contatti ossidati o meccanicamente lenti.

Escluderebbe: contatti puliti, continuita' affidabile, nessun cambiamento muovendo cablaggi e localizzazione elettrica del difetto altrove.

Componenti/net/pagine: `connectors.md`, `pvs_service` pagine 4, 6, 9, 11.

### I. Surriscaldamento dei regolatori `U301/U302/U303` sul dissipatore/case

Perche compatibile: un regolatore caldo puo' essere effetto di carico eccessivo, condensatore in perdita/corto, rail disturbato, tensione di ingresso troppo alta o cattivo accoppiamento termico. Se il rail disturbato alimenta CV/audio/reset, puo' contribuire al bleed; se invece il rail e' elettricamente sano, puo' essere un secondo problema separato.

Area da ispezionare: `U301 7805` su `+5VD`, `U302 7812` su `+12V`, `U303 7912` su `-12V`, condensatori e diodi/rectifier/filtro vicini, cablaggio, vite, isolamento, rondella, mica/pasta termica e contatto col case.

Supporterebbe: temperatura anomala solo su un regolatore, Vin/Vout/ripple fuori norma, corrente assorbita alta sul rail, condensatore caldo o in perdita, caduta Vin-Vout elevata, isolamento termico montato male.

Escluderebbe: temperatura coerente con carico previsto, rail puliti e assorbimento normale, problema audio/CV localizzato altrove.

Componenti/net/pagine: `U301/U302/U303`, `+5VD`, `+12V`, `-12V`, `C301/C304/C305/C307/C308/C309`, `pvs_service` pagine 4/5, `sci_prophet_vs_ecr739` pagina 4, `../foto/IMG_5543.jpg`.

## 4. Controlli sicuri e non invasivi da fare prima

- Ispezione visiva a strumento spento: componenti anneriti, crepati, montati al contrario, condensatori gonfi/in perdita, saldature opache, pad sollevati, piste tagliate, jumper e flussante.
- Reinserimento/reseating prudente dei connettori, senza forzare plastica o pad vecchi.
- Controllo corrosione/ruggine evidente intorno a MIDI, footswitch, aux, jack output, connettori tra board.
- Controllo revisione board e confronto con ECR738/ECR739: resistenze annotate, tagli piste, jumper, qualita' delle saldature.
- Controllo rail alimentazione con la dovuta cautela e solo su punti accessibili, evitando l'area mains/trasformatore se non si e' qualificati.
- Test di ascolto: confronto tra uscita dry e chorus/output, canale left/right, cuffie/line se applicabile.
- Inizializzazione patch e confronto tra patch inizializzata e factory patch: annotare se il bleed segue envelope/LFO/modulation matrix o se resta fisso.
- Verifica comportamento del pot volume: capire se il segnale residuo e' prima o dopo il volume control, senza sostituire il potenziometro a priori.
- Identificazione visiva dei tre regolatori su `../foto/IMG_5543.jpg`: `U301 7805`, `U302 7812`, `U303 7912`; la designator map indica sinistra->destra `U301/U302/U303`, da confermare sulla PCB reale se la serigrafia e' visibile.
- Controllo segni di stress termico intorno a `U301/U302/U303`, condensatori elettrolitici/tantalio vicini, diodi/rectifier/filtro e connettori.
- Controllo che vite, isolamento, rondella, pasta termica e contatto con dissipatore/case siano corretti per il package e per il tipo di regolatore installato.

## 5. Misure per tecnico qualificato

- Misurare rail `+5VD`, `+12V`, `-12V`, `+8V`, `+5.6V`, `-5V` e ripple, con massa corretta e puntali sicuri.
- Per `U301 7805`, `U302 7812`, `U303 7912`: misurare tensione ingresso, tensione uscita, ripple, caduta Vin-Vout, temperatura e corrente/carico se misurabile in sicurezza.
- Confrontare la temperatura tra i tre regolatori, senza concludere automaticamente che quello piu' caldo sia guasto.
- Controllare assorbimento a valle dei rail `+5VD`, `+12V`, `-12V`, cercando eventuale carico anomalo o IC/condensatore che scalda.
- Controllare condensatori in perdita/corto e diodi/rectifier/filtro nella sezione del rail interessato.
- Osservare il comportamento della CV VCA quando il volume e' a zero e quando il sintomo e' presente.
- Osservare le uscite sample & hold, soprattutto `VCA/VCF/PAN/LEV`, per droop, rumore, ripple, livelli DC errati o modulazione non prevista.
- Verificare DAC/riferimenti e timing `INH` solo dopo aver confermato rail stabili.
- Controllare op amp/output per uscite bloccate, saturate, con DC offset o rumore anomalo.
- Misurare concettualmente `PRESSURE/SENSOR`, `TP301/TP302` e i valori delle reti `R321`, `R307/R308/R309/R320/R304`, `R458` quando pertinenti.
- Verificare continuita' di piste tagliate/jumper ECR e continuita' ground `AGND/DGND` secondo schema, senza creare ponti accidentali.

Non dare per scontato lato mains: trasformatore, primario, cablaggi AC e zone esposte vanno trattati solo da tecnico qualificato con strumenti e isolamento appropriati.

## 6. Rilevanza ECR738/ECR739

ECR738 e ECR739 sono rilevanti perche toccano aree pressure/aftertouch e, nel caso di ECR739, anche keyboard/power/reset. Non sono automaticamente la causa del bleed o del regolatore caldo: indicano pero' zone dove una modifica mancata, parziale o fatta male puo' introdurre offset, CV fuori scala, rumore, instabilita' o saldature fragili.

ECR738 mostra l'area pressure sensor sul lato main analog/sample & hold, con `U459`, `R458`, rail `+12V/-12V` e vicinanza alle uscite CEM5530. ECR739 mostra la pressure circuit su digital/keyboard con `U310`, rete `R321/R307/R308/R309/R320/R304`, `TP301/TP302`, e la sezione alimentazione `U301/U302/U303/U304`.

La verifica corretta e':

- controllare se le modifiche sono presenti sulla board reale;
- controllare se i valori fisici corrispondono a schema/ECR;
- ispezionare tagli piste e jumper;
- misurare rail e CV prima di attribuire il sintomo a un componente raro.

## 7. Componenti/aree da attenzionare

| Area | Componenti/net | Perche rilevante | Pagina sorgente |
| --- | --- | --- | --- |
| Regolatori principali su dissipatore/case | `U301 7805`, `U302 7812`, `U303 7912`; rail `+5VD`, `+12V`, `-12V`; ordine fisico sinistra->destra dalla designator map `pvs_service` pagina 5 | Uno dei tre scalda troppo; se il rail ha ripple, carico eccessivo o caduta Vin-Vout anomala puo' disturbare audio/CV/reset o essere un guasto separato | `pvs_service` pagine 4/5, `sci_prophet_vs_ecr739` pagina 4, `../foto/IMG_5543.jpg` |
| Reset e power digital/keyboard | `U304 78L05`, `U305 HC132`, `RESET`, `+5VD`, `DGND` | Reset o logica instabili possono alterare refresh CV, inizializzazione e comportamento digitale | `pvs_service` pagina 4, `sci_prophet_vs_ecr739` pagina 4, `power_reset.md` |
| Rail analogici locali S&H | `U401 7905`, `U402 78M05`, `U450 78M08`; rail `-5V`, `+5.6V`, `+8V`, `+12V`, `-12V` | Alimentano e polarizzano S&H/CV; ripple o rail bassi possono causare CV errate e bleed | `pvs_service` pagina 6, `power_rails.md` |
| Sample & hold / CV generation | CEM5530 `U449/U425`, `U451`, `U453/U454`, net `DAC`, `INH`, `VCA/VCF/PAN/LEV`, `RIGHT FINAL CV` | Droop, hold step o timing/riferimenti errati possono lasciare VCA aperto o introdurre modulazione | `pvs_service` pagina 6, `5530` pagine 1/3/4, `sample_hold_cv.md` |
| VCA/VCF/PAN audio path | `U455/U456/U457/U458`, net `VCA`, `VCF`, `PAN`, `LEFT`, `RIGHT`, R/C pagina 9 | Area diretta per audio distorto, VCA che non chiude o pan/level anomali | `pvs_service` pagina 9, `audio_path.md`, `named_nets.md` |
| Output/chorus/lowpass | `U903/U904/U920`, `TL082`, net `LEFT`, `RIGHT`, `CHORUS`, `LEFT CHORUS`, `RIGHT CHORUS`, `LEV` | Se il bleed appare dopo il controllo volume, output/chorus/op amp/filtro possono essere il punto di rientro | `pvs_service` pagine 11/12, `audio_path.md` |
| Pressure/aftertouch | `U310`, `U459`, `R321`, `R307/R308/R309/R320/R304`, `R458`, `PRESSURE`, `SENSOR`, `TP301/TP302` | Pressure o ECR errate possono contaminare CV o produrre modulazioni indesiderate | `pvs_service` pagine 4/6, `sci_prophet_vs_ecr738` pagina 2, `sci_prophet_vs_ecr739` pagina 4 |
| Interconnessioni e test point | `P402/P403`, `P302/P305`, `P303`, `P901`, `P3908`, `P4093`, `TP301/TP302` | Connettori ossidati o lenti possono creare intermittenti, ground incerti, audio/CV che cambia muovendo cavi | `connectors.md`, `pvs_service` pagine 4/6/9/11 |
| Condensatori e reti vicine ai rail | `C301`, `C304`, `C305`, `C307`, `C308`, `C309`, `C401/C402`, C9xx/R9xx output | Condensatori in perdita/corto o ESR elevata possono aumentare carico, ripple, distorsione o bleed | `resistors_caps.md`, `pvs_service` pagine 4/6/11/12, `sci_prophet_vs_ecr739` pagina 4 |

## 8. Domande da fare al riparatore

- Puoi verificare se le modifiche ECR738/ECR739 sono presenti e fatte correttamente?
- Puoi controllare rail e ripple prima di sostituire IC a caso?
- Puoi verificare se il bleed e' prima o dopo il potenziometro volume/output stage?
- Puoi controllare con oscilloscopio le linee CV rilevanti e il controllo VCA?
- Puoi ispezionare solder bridge, piste sollevate o riparazioni precedenti?
- Puoi identificare fisicamente i tre regolatori sul dissipatore/case (`U301/U302/U303`) e dirmi quale dei tre scalda?
- Puoi misurare Vin/Vout/ripple e caduta termica sui regolatori, e verificare se c'e' carico eccessivo a valle?
- Puoi controllare condensatori/diodi/ponte rettificatore e IC alimentati dal rail del regolatore caldo?
- Puoi verificare isolamento, vite, rondelle e pasta termica del regolatore sul dissipatore/case?
- Puoi confrontare il comportamento su patch inizializzata e factory patch?
- Puoi evitare recap generalizzato se le misure non indicano problemi ai condensatori?

## 9. Conclusione

Ordine diagnostico consigliato:

1. Separare elettricamente il sintomo audio/CV dal sintomo termico: identificare quale regolatore scalda e quale rail alimenta.
2. Misurare rail e ripple, perche un rail disturbato puo' spiegare sia riscaldamento sia comportamento audio/CV anomalo.
3. Se i rail sono corretti, seguire il bleed: prima/dopo volume, VCA, S&H/CV, output/chorus.
4. Controllare ECR738/ECR739 e riparazioni precedenti solo come aree sospette, non come diagnosi gia' decisa.

Il bleed/distorsione puo' venire da audio path, CV VCA, S&H o output/chorus. Il regolatore caldo puo' essere una causa comune se il rail e' basso/rumoroso o se un carico a valle disturba la macchina. Puo' pero' anche essere un secondo problema separato: la cosa importante e' non sostituire componenti a catena prima di avere rail, ripple, temperature e punto di ingresso del bleed misurati.

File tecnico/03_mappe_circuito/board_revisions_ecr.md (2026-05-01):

# Board Revisions / ECR738 / ECR739

## Ruolo nel Prophet VS
Questa mappa confronta gli engineering change records scannerizzati. Non assumere che il Prophet VS reale abbia una di queste modifiche: va verificato sulla board.

## Pagine/sorgenti
- [sci_prophet_vs_ecr738 pagina 2](../05_pagine_rilevanti/note/sci_prophet_vs_ecr738/page_002.md)
- [sci_prophet_vs_ecr738 pagina 3](../05_pagine_rilevanti/note/sci_prophet_vs_ecr738/page_003.md)
- [sci_prophet_vs_ecr739 pagina 4](../05_pagine_rilevanti/note/sci_prophet_vs_ecr739/page_004.md)
- [pvs_service pagina 4](../05_pagine_rilevanti/note/pvs_service/page_004.md)
- [pvs_service pagina 6](../05_pagine_rilevanti/note/pvs_service/page_006.md)

## ECR738
Motivo dichiarato della modifica: non incluso in questo pacchetto pulito. La pagina 2 mostra una modifica nell'area pressure sensor / sample & hold sensor.

Componenti/piste visibili:
- PRESSURE SENSOR, U459, R458, +12V, -12V, C4148/C4147 circa, P402/SENSOR/DGND sono visibili o inferibili dall'immagine ECR738 pagina 2.
- R458 appare annotata come 15K; nell'immagine e' anche visibile una rete con +12V e valori manoscritti, incluso 6.8K e 1K vicino al nodo pressure. Verificare sull'immagine e sulla board.

Perche puo essere importante:
- Cambiare resistenze o bias nel pressure sensor puo alterare offset, range e saturazione dell'aftertouch.
- Una modifica errata puo far arrivare CV fuori scala, contaminare letture o creare sintomi intermittenti se jumper/tagli sono fragili.

Cosa verificare fisicamente:
- Revisione board e presenza di tagli piste/jumper nella zona pressure sensor.
- Valore reale di R458 e delle resistenze annotate vicino a +12V.
- Qualita saldature, piste sollevate, flussante/ossidazione e continuita verso P402/SENSOR/DGND.

## ECR739
Motivo dichiarato della modifica: non incluso in questo pacchetto pulito. La pagina 4 mostra chiaramente pressure circuit, keyboard/power supply e reset/power rails.

Componenti/piste visibili:
- R321 OFFSET 50K, R307 20K, R308 10K, R309 47K, R320 10K, R304 15K, R305 470K, U310 op amp, U305 HC132, U301 7805, U302 7812, U303 7912, U304 78L05.
- TP301/TP302, SENSOR, PRESSURE, +5VD, +12V, -12V, DGND, AGND sono leggibili sulla pagina 4.

Confronto con ECR738:
- Entrambi toccano il pressure/aftertouch path, ma ECR738 e' mostrato sul lato main analog/sample & hold sensor, mentre ECR739 e' mostrato sul lato digital/keyboard/power supply.
- Rete, connettori e nomi net non vanno fusi automaticamente: confrontare le pagine ECR con pvs_service pagine 4 e 6.

## Checklist verifica ECR
- Revisione board stampata/silkscreen corrisponde ai documenti?
- Ci sono piste tagliate? Sono pulite e isolate?
- Ci sono jumper aggiunti? Sono meccanicamente stabili?
- Valori resistenze corrispondono alle annotazioni ECR e allo schema di servizio?
- Le saldature nella zona pressure sensor/regolatori sono lucide e non sollevano pad?
- Il routing fisico corrisponde all'artwork scannerizzato?
- I rail +5VD, +12V, -12V, +8V/+5.6V/-5V sono presenti prima di interpretare il segnale pressure?

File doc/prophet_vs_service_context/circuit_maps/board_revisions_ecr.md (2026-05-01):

# Board Revisions / ECR738 / ECR739

## Ruolo nel Prophet VS
Questa mappa confronta gli engineering change records scannerizzati. Non assumere che il Prophet VS reale abbia una di queste modifiche: va verificato sulla board.

## Pagine/sorgenti
- [sci_prophet_vs_ecr738 pagina 1](../page_notes/sci_prophet_vs_ecr738/page_001.md)
- [sci_prophet_vs_ecr738 pagina 2](../page_notes/sci_prophet_vs_ecr738/page_002.md)
- [sci_prophet_vs_ecr738 pagina 3](../page_notes/sci_prophet_vs_ecr738/page_003.md)
- [sci_prophet_vs_ecr739 pagina 1](../page_notes/sci_prophet_vs_ecr739/page_001.md)
- [sci_prophet_vs_ecr739 pagina 4](../page_notes/sci_prophet_vs_ecr739/page_004.md)
- [pvs_service pagina 4](../page_notes/pvs_service/page_004.md)
- [pvs_service pagina 6](../page_notes/pvs_service/page_006.md)

## ECR738
Motivo dichiarato della modifica: [NON CHIARO] nella scansione/OCR della pagina 1. La pagina 2 mostra una modifica nell'area pressure sensor / sample & hold sensor.

Componenti/piste visibili:
- PRESSURE SENSOR, U459, R458, +12V, -12V, C4148/C4147 circa, P402/SENSOR/DGND sono visibili o inferibili dall'immagine ECR738 pagina 2.
- R458 appare annotata come 15K; nell'immagine e' anche visibile una rete con +12V e valori manoscritti, incluso 6.8K e 1K vicino al nodo pressure. Verificare sull'immagine e sulla board.

Perche puo essere importante:
- Cambiare resistenze o bias nel pressure sensor puo alterare offset, range e saturazione dell'aftertouch.
- Una modifica errata puo far arrivare CV fuori scala, contaminare letture o creare sintomi intermittenti se jumper/tagli sono fragili.

Cosa verificare fisicamente:
- Revisione board e presenza di tagli piste/jumper nella zona pressure sensor.
- Valore reale di R458 e delle resistenze annotate vicino a +12V.
- Qualita saldature, piste sollevate, flussante/ossidazione e continuita verso P402/SENSOR/DGND.

## ECR739
Motivo dichiarato della modifica: [NON CHIARO] nelle pagine 1-3. La pagina 4 mostra chiaramente pressure circuit, keyboard/power supply e reset/power rails.

Componenti/piste visibili:
- R321 OFFSET 50K, R307 20K, R308 10K, R309 47K, R320 10K, R304 15K, R305 470K, U310 op amp, U305 HC132, U301 7805, U302 7812, U303 7912, U304 78L05.
- TP301/TP302, SENSOR, PRESSURE, +5VD, +12V, -12V, DGND, AGND sono leggibili sulla pagina 4.

Confronto con ECR738:
- Entrambi toccano il pressure/aftertouch path, ma ECR738 e' mostrato sul lato main analog/sample & hold sensor, mentre ECR739 e' mostrato sul lato digital/keyboard/power supply.
- Rete, connettori e nomi net non vanno fusi automaticamente: confrontare le pagine ECR con pvs_service pagine 4 e 6.

## Checklist verifica ECR
- Revisione board stampata/silkscreen corrisponde ai documenti?
- Ci sono piste tagliate? Sono pulite e isolate?
- Ci sono jumper aggiunti? Sono meccanicamente stabili?
- Valori resistenze corrispondono alle annotazioni ECR e allo schema di servizio?
- Le saldature nella zona pressure sensor/regolatori sono lucide e non sollevano pad?
- Il routing fisico corrisponde all'artwork scannerizzato?
- I rail +5VD, +12V, -12V, +8V/+5.6V/-5V sono presenti prima di interpretare il segnale pressure?

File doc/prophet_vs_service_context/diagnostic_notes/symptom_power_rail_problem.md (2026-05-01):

# Sintomo: Power rail problem

## Descrizione sintomo
Sintomi multipli, reset, distorsione, rumore o instabilita che suggeriscono alimentazione.

## Aree circuito piu rilevanti
7805/7812/7912/78L05/78M08/78M05/7905, rettificatori, condensatori, AGND/DGND.

## Pagine sorgente da ispezionare
- [pvs_service pagina 4](../page_notes/pvs_service/page_004.md)
- [pvs_service pagina 6](../page_notes/pvs_service/page_006.md)
- [sci_prophet_vs_ecr739 pagina 4](../page_notes/sci_prophet_vs_ecr739/page_004.md)
- [5530 pagina 3](../page_notes/5530/page_003.md)

## Possibili cause ordinate dalla piu probabile alla meno probabile
1. Ripple eccessivo
2. Regolatore guasto
3. Condensatore elettrolitico/tantalio in perdita
4. Ground aperto o sporco
5. Carico eccessivo a valle

## Quale evidenza supporterebbe ogni causa
- Il sintomo cambia quando si osservano/isolano concettualmente le aree circuito indicate nelle pagine sorgente.
- Le misure mostrano rail, CV o audio fuori range rispetto alle etichette presenti nello schema.
- Ispezione visiva trova saldature, jumper, piste o componenti nella stessa zona delle pagine linkate.

## Quale evidenza la escluderebbe
- Rail e ground stabili, nessun ripple anomalo, e segnale/CV corretto prima e dopo il blocco sospetto.
- Il difetto resta invariato dopo esclusione documentata del blocco indicato.
- Continuita e componenti fisici corrispondono agli schemi/ECR.

## Misure/controlli da eseguire
- Prima controllare rail principali e locali indicati nelle page note.
- Poi osservare segnali etichettati nella pagina sorgente con massa corretta e strumenti adatti.
- Confrontare comportamento statico e dinamico: valore DC, ripple, risposta a patch/controlli, eventuale modulazione residua.

## Aree scheda/componenti da ispezionare visivamente
- Connettori citati nelle page note.
- Zone ECR e riparazioni precedenti, soprattutto tagli piste/jumper.
- Regolatori, op amp, CEM5530/S&H, condensatori tantalio/elettrolitici e jack/output.

## Rischi / cautele
- Non operare su mains/trasformatore senza tecnico qualificato.
- Evitare corti con puntali; vecchie PCB possono sollevare pad con calore o forza.
- Non sostituire parti rare senza prova; alcuni IC possono essere difficili da reperire.

## Domande per un tecnico
- Il difetto cambia tra uscita left/right, cuffie/line out o chorus on/off?
- Il bleed segue VCA/VCF/PAN/LEV o resta nel percorso audio finale?
- I rail locali e reference sono stabili a freddo/caldo?
- La board mostra ECR738/ECR739 applicati, parziali o assenti?
